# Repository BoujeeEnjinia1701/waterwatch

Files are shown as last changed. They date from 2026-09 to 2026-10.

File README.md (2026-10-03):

# WaterWatch

     

**Area:** Water Security · **TRL:** 3 of 9 (proof of concept on paper) · **Value-engineering target:** USD 300 (estimated cost of the constructable design: USD 322) · **Difficulty:** 3 of 5

Solar sentinel sensor that logs turbidity, free chlorine and temperature at a tap or tank and alerts over GSM or LoRa.

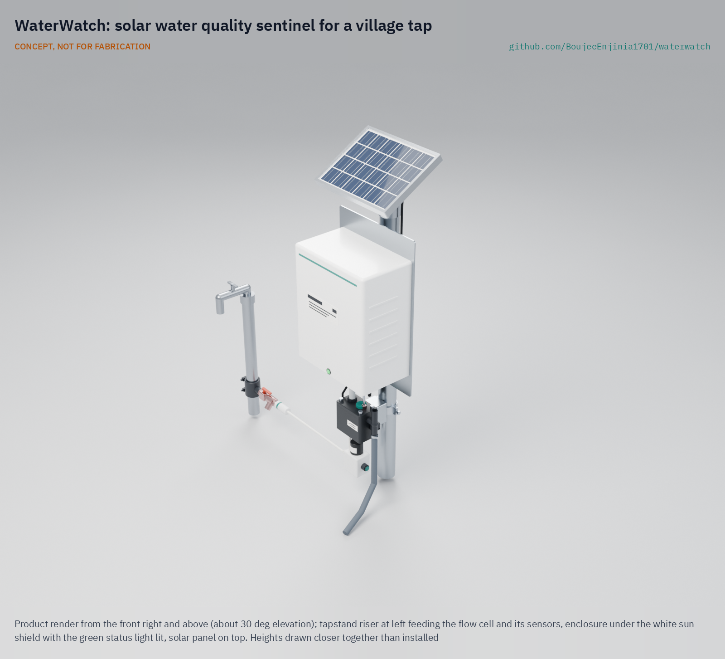
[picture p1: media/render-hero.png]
WaterWatch: solar water quality sentinel for a village tap, product render


[Exploded render](media/render-exploded.png) · [Detail render](media/render-detail.png) · [Interactive 3D model](media/viewer.html) · [Concept blueprint (PDF)](media/concept-blueprint.pdf) · [General arrangement (PDF)](cad/drawings/WWT-DWG-001.pdf) · [Sizing calculations](docs/04-calcs/01-sizing.md) · [Prototype build plan](docs/05-build-plan.md) · [Design decisions](docs/06-design-decisions.md) · [Review note](docs/REVIEW.md)

## Concept rationale

The two readings that tell a rural operator most about treated water at the tap are free chlorine residual and turbidity, and both can be measured without reagents. WaterWatch therefore pairs a membrane-free graphite chlorine sensor and an open-source infrared turbidimeter with a timed hourly flush, a small solar supply and plain SMS alerts, rather than a mains-powered utility analyzer whose chlorine probe alone costs about $1,900. It watches indicators and raises an alert; it does not dose, and it never declares water safe.

Keeping the design open and garage-buildable matters because the people who would install and maintain it are small scheme operators, maintenance service providers and caretakers, not utility instrument technicians. Every part is off the shelf or made from simple stock, the calibration is a monthly DPD comparator check that caretakers already know, and the CERN-OHL-S license lets a regional workshop build, repair and adapt the unit without a vendor.

## Burning platform

In 2024, 2.1 billion people still lacked safely managed drinking water ([WHO and UNICEF JMP, 2025](https://www.who.int/news/item/26-08-2025-1-in-4-people-globally-still-lack-access-to-safe-drinking-water---who--unicef)). WHO estimates that at least 1.7 billion people use a drinking water source contaminated with faeces, and that contaminated drinking water causes about 505,000 diarrhoeal deaths each year ([WHO, drinking-water fact sheet, 2023](https://www.who.int/news-room/fact-sheets/detail/drinking-water)).

Chlorination is the cheapest defense a piped rural scheme has, but it only protects people when a residual of at least 0.2 mg/L reaches the tap ([Oxfam WASH, chlorination in emergencies](https://www.oxfamwash.org/chlorination-in-emergencies/)). Today that is checked by hand when a technician visits, so a chlorinator that runs dry or a storm that clouds the source can go unnoticed for weeks. Remote sensors have already cut repair times for broken handpumps when someone was paid to act on the data ([Nagel et al., ES&T 2015](https://pubs.acs.org/doi/10.1021/acs.est.5b04077)); nothing comparable, open and affordable yet watches the quality of the water itself.

## Where it could be used

### By industry

| Industry | Use |
| --- | --- |
| Rural water utilities and scheme operators | Watch chlorine residual and turbidity at tapstands across many villages and target dosing and repairs |
| Maintenance service providers | Add water quality alerts to existing handpump and scheme functionality monitoring contracts |
| Humanitarian WASH response | Track free chlorine at tapstands in camps and after floods, where chlorination is routine and outbreaks spread fast |
| Schools and health facilities | Monitor the tank outlet or tap that serves pupils and patients between official tests |
| Water kiosks and small private operators | Give customers and regulators a running record of the water they sell |
| Universities and WASH research groups | Collect long, open data sets on residual decay and turbidity events at the point of use |

### By country or region

| Country or region | Why it matters there |
| --- | --- |
| Rwanda | Cellular handpump sensors paired with a paid maintenance service shortened repair times ([Nagel et al., 2015](https://pubs.acs.org/doi/10.1021/acs.est.5b04077)); the same service model could act on water quality alerts |
| Nigeria (Plateau State) | Sensors have already tracked functionality and use of rural water points ([Plateau State sensors, 2022](https://www.sciencedirect.com/science/article/pii/S2352728522000094)); water quality alerts would extend the same approach |
| India | Rural household tap connections rose from 17 % to over 49 % between 2019 and 2022 under the Jal Jeevan Mission, yet [less than 49 % of rural people use safely managed drinking water](https://www.unicef.org/india/what-we-do/clean-drinking-water); a logged residual at the tap would show whether new piped schemes deliver treated water |
| Honduras | Community water boards run passive chlorinators at storage tanks; in a 2023 study [77 % of samples met the 0.2 mg/L WHO minimum, board errors caused 39 % of chlorination lapses, and more frequent circuit-rider visits went with better results](https://pubmed.ncbi.nlm.nih.gov/38094914/) (Lindmark et al., ACS ES&T Water) |
| Canada (Ontario) | A high-income example: at Walkerton in May 2000 operators did not measure chlorine residuals at a municipal well as they should have, seven people died and 2,300 fell ill ([CBC News, highlights of the Walkerton Inquiry report](https://www.cbc.ca/news/canada/highlights-of-the-walkerton-inquiry-report-1.867604)) |

## What sparked the idea

The idea traces back to the E. coli outbreak in Walkerton, Ontario, in May 2000. Part One of the Walkerton Inquiry, released by Associate Chief Justice Dennis O'Connor in 2002, found that the Well 5 water was to carry a chlorine residual of 0.5 mg/L after 15 min of contact, that operators routinely used less chlorine than required, did not measure residuals on most days and made false entries in the daily operating records, and that seven people died and 2,300 became ill ([CBC News, highlights of the Walkerton Inquiry report](https://www.cbc.ca/news/canada/highlights-of-the-walkerton-inquiry-report-1.867604); [National Academies, Lessons from Waterborne Disease Outbreaks](https://www.ncbi.nlm.nih.gov/sites/books/NBK28459/)). The inquiry concluded that continuous chlorine residual and turbidity monitors at Well 5 would have prevented the outbreak. A town in a high-income country, with a regulated municipal supply, lost its chlorine barrier without anyone noticing in time. At a village tapstand checked only on rare visits, the gap is wider, and a logged, automatic residual and turbidity reading that raises its own alert is the part WaterWatch aims to supply.

## Problem

Rural water points go untested between rare lab visits, so a chlorinator that runs dry or a storm that clouds the source can go unnoticed for weeks. Full problem statement: [docs/01-problem.md](docs/01-problem.md)

## Concept

A pole-mounted sentinel beside a village tapstand flushes a small sample through a dark flow-through cell once an hour, measures turbidity, free chlorine and temperature, logs the readings and sends them over cellular (LTE-M, NB-IoT or 2G; LoRaWAN as a variant). An SMS goes to the caretaker and operator when chlorine drops below 0.2 mg/L or turbidity passes 5 NTU. The TRL 3 calculations give 0.54 Wh per day, 28.5 days on battery without sun, 18 L per day of flushed water and an estimated USD 322 in parts for the constructable design, USD 22 over the USD 300 value-engineering target. Following Amish's decisions of 2026-09-25 (WWT-DDR-002), the chlorine accuracy target is ±0.2 mg/L or ±25 %, and sites above pH 7.5 or with a moving pH take a pH probe in a spare port of the cell; the error budget then meets the target before drift, but the low-cost sensor's long-term drift is unknown, so chlorine accuracy and the monthly maintenance interval remain at risk.

Full design precis: [docs/02-concept.md](docs/02-concept.md)

## Key components

- Infrared (860 nm) nephelometric turbidity optics: LED, 90° scatter and 180° reference detectors on three walls of the cell
- Membrane-free three-electrode free chlorine sensor with a potentiostat front end
- Temperature probe
- Opaque 0.19 L flow-through cell fed through a pressure-compensating regulator and a latching solenoid valve from a tee on the tapstand riser, draining through an open air break
- Two aluminium back plates on U-bolts hold the enclosure and the flow cell to the pole
- ESP32 controller with microSD logging
- Cellular modem (LTE-M, NB-IoT, 2G fallback), LoRaWAN as a variant
- 5 W solar panel and 3.2 V, 6 Ah LiFePO4 battery in an enclosure under a ventilated sun shield

The priced bill of materials is in [bom/bom.csv](bom/bom.csv). The parametric model is `cad/src/model.py`, with STEP files in `cad/step/`.

## Building the prototype

The prototype build plan ([docs/05-build-plan.md](docs/05-build-plan.md)) shows how to make and fit every component of the first proof-of-concept unit, with a making sketch for each made part, close-ups of the joints and a picture for every assembly step. Making it buildable changed the concept in places: the enclosure and the flow cell now hang on aluminium back plates held to the pole by U-bolts, every cable enters the box from below so the sun shield slides off, and the turbidity optics sit on three walls of the cell (decision record WWT-DDR-003, accepted by Amish on 2026-10-02). The plan is paper only; building and testing to it is TRL 4 work. The decisions, all made as of 2026-10-02, are in the [design decisions register](docs/06-design-decisions.md).

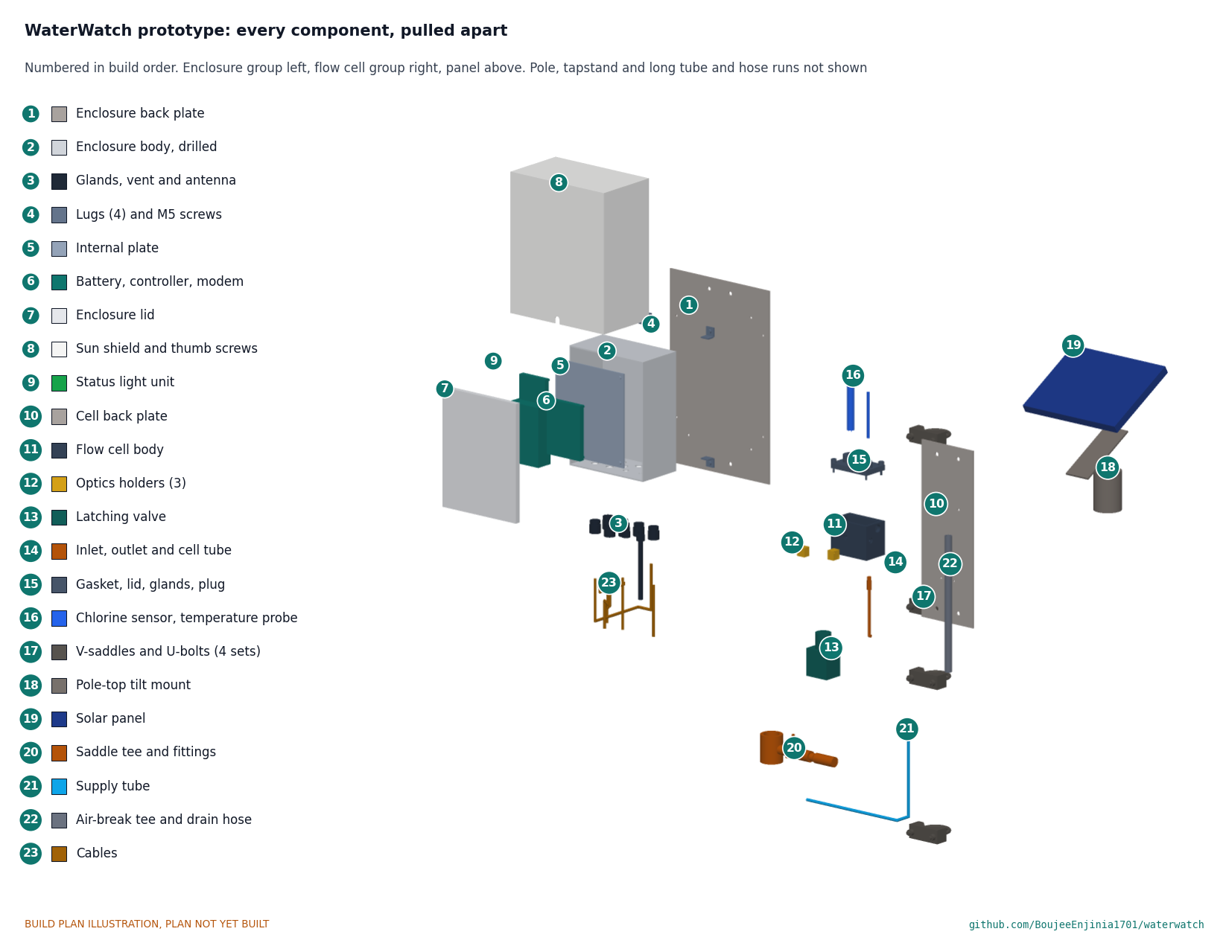
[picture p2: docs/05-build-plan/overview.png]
WaterWatch prototype: every component, pulled apart and numbered in build order


## Safety

> A sensor alert does not replace accredited lab testing, and a normal reading does not mean the water is safe to drink. Contains a LiFePO4 battery: use a protection board, a fuse and charging temperature cut-offs. The sample line connects to a pressurized drinking water supply: fit an isolation valve and a check valve so nothing flows back into the supply.

## Repository layout

| Folder | Contents |
| --- | --- |
| `docs/` | Problem, concept, requirements, calculations and design decisions |
| `cad/src/` | build123d Python source, the source of truth for all geometry |
| `cad/step/`, `cad/stl/` | Exported models for FreeCAD, other CAD tools and printing |
| `cad/drawings/` | 2D sketches and dimensioned drawings |
| `bom/` | Bill of materials |
| `electronics/` | KiCad schematics and PCB layouts |
| `firmware/` | Microcontroller code |
| `media/` | Renders, perspectives and photos |
| `build-log/` | Dated prototyping notes |

## Documentation

Controlled documents follow the portfolio [documentation standard](.kit/STANDARDS.md). Each carries a document ID (WWT-PRC-001 for the precis), a version and a revision history. Branded PDFs are built with `python .kit/render.py` and attached to GitHub Releases when a document is tagged, for example `WWT-PRC-001/v1.0`.

## Credits

Designed by Amish Chadha. See [CONTRIBUTORS.md](CONTRIBUTORS.md) for roles. To cite this design, use [CITATION.cff](CITATION.cff) (GitHub shows it as "Cite this repository").

AI assistance (Claude) was used to accelerate concept renders, prototype documentation and first-pass sizing calculations. Design direction and all decisions are Amish Chadha's, recorded in this repository's decision records (`docs/decisions/`).

## Licenses

- **Hardware** (CAD, drawings, BOM, electronics): [CERN-OHL-S v2](LICENSE)
- **Software** (firmware, scripts, notebooks): [MIT](LICENSE-SOFTWARE)

A project of the [Design Molecule](https://designmolecule.com) lab.

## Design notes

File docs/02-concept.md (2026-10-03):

---
doc_id: WWT-PRC-001
title: WaterWatch design precis
project: WaterWatch
doc_type: Design precis
version: "0.7"
status: Draft
date: '2026-10-02'
author: Amish Chadha
license: CERN-OHL-S-2.0
revisions:
- version: "0.1"
  date: '2026-09-24'
  author: Amish Chadha
  change: Initial scaffold
- version: "0.2"
  date: '2026-09-25'
  author: Amish Chadha
  change: Populate to TRL 2 (architecture, components, first-order numbers, safety, open questions, media)
- version: "0.3"
  date: '2026-09-25'
  author: Amish Chadha
  change: For TRL 3, decisions from WWT-DDR-001; numbers from WWT-CAL-001; smaller flow cell, pressure-compensating regulator, 30 s settling wait, air-break drain and sun shield; parametric model and drawing WWT-DWG-001
- version: "0.4"
  date: '2026-09-25'
  author: Amish Chadha
  change: Recommendations accepted by Amish (DDR-002)
- version: "0.5"
  date: '2026-10-02'
  author: Amish Chadha
  change: Design made constructable (WWT-DDR-003); components table, cost and drawings updated; budget treated as a value-engineering target
- version: "0.6"
  date: '2026-10-02'
  author: Amish Chadha
  change: Partner, alert and data open questions answered by Amish's decisions of 2026-10-02 (WWT-DEC-001)
- version: "0.7"
  date: '2026-10-02'
  author: Amish Chadha
  change: "Energy, autonomy and cost from WWT-CAL-001 v0.4 (status light, WWT-DEC-001)"
---

# WaterWatch design precis

WaterWatch is a solar sentinel that stands on its own pole beside a village tapstand. Once an hour a latching valve on a tee in the tapstand riser opens for 90 s and flushes water through a small, dark flow-through cell. An infrared nephelometer measures turbidity, a membrane-free three-electrode sensor measures free chlorine and a sealed probe measures temperature. An ESP32 controller logs the readings, a cellular modem uploads them every 4 h, and an SMS goes to the caretaker and operator when chlorine drops below 0.2 mg/L or turbidity passes 5 NTU. The TRL 3 calculations (WWT-CAL-001) give 0.54 Wh per day, 28.5 days on a 3.2 V, 6 Ah LiFePO4 battery without sun, 18.0 L per day of flushed water and $322 in parts for the constructable design (WWT-DDR-003 and the status light of WWT-DEC-001), USD 22 over the USD 300 value-engineering target. How each part is made and fitted is in the prototype build plan (WWT-BLD-001). The weak point is still the chlorine reading. Under Amish's decisions of 2026-09-25 (WWT-DDR-002), R1 is relaxed to ±0.2 mg/L or ±25 %, and sites whose pH is above 7.5 or moves more than 0.2 between visits take a pH probe in a spare port of the cell. With that rule the error budget meets R1 before sensor drift, but the low-cost sensor's drift over months is unknown, so R1 and R10 remain at risk. The design choices below were decided by Amish on 2026-09-25 (WWT-DDR-001 and WWT-DDR-002).

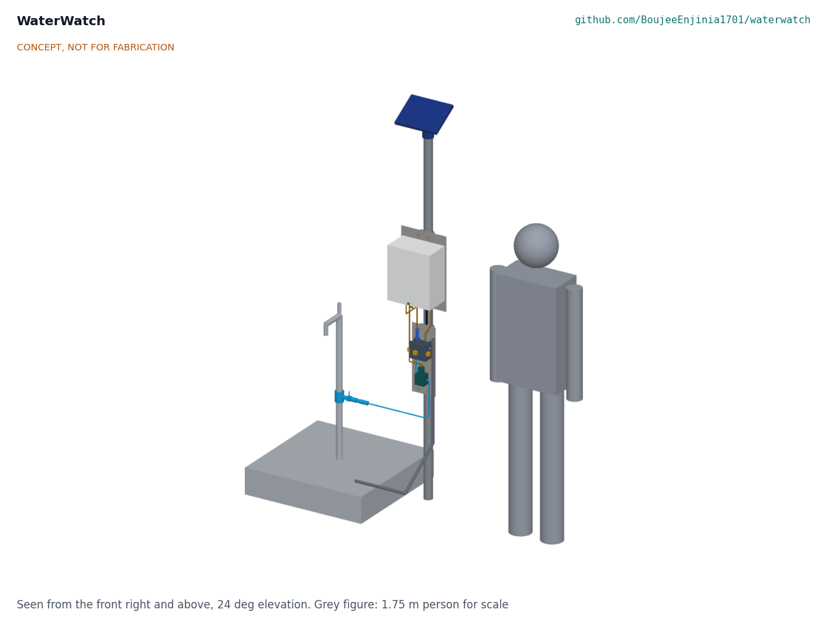
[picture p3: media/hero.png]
Hero render


*Figure 1. WaterWatch beside an existing tapstand (grey), with a 1.75 m person for scale. Solar panel on top, electronics enclosure under a white sun shield at eye height, flow-through cell below it, latching valve and sample line from a tee on the tapstand riser, drain hose to the tapstand basin. Rendered from the parametric model `cad/src/model.py`.*

## How it works

1. **Sample.** A saddle tee with an isolation valve on the tapstand riser feeds a strainer, a check valve, a pressure-compensating flow regulator (0.5 L/min) and a normally closed, direct-acting latching solenoid valve. Every hour the controller opens the valve for 90 s, flushing 0.75 L, about four volumes of the 0.19 L cell, then closes it. The sample enters at the bottom of the cell and leaves near the top, so the cell stays full and the electrodes stay wet between flushes. The outlet rises to an open air-break vent before the drain hose falls to the basin, so the hose cannot siphon the cell empty and the drain can never connect back to the cell.
2. **Measure.** During the last 10 s of flow the controller reads the chlorine sensor, because amperometric sensors need steady flow across the electrode. After the valve closes it waits 30 s for bubbles to rise clear, then reads turbidity for 5 s and temperature. The cell is opaque so daylight does not reach the turbidity detector.
3. **Log.** Each reading is stored with a timestamp on a microSD card (90 days or more) and in a short ring buffer in flash.
4. **Report.** Every 4 h the modem wakes, attaches to LTE-M, NB-IoT or 2G, and posts a compact batch to an open endpoint the operator chooses. If a reading crosses a threshold, the controller takes a confirming reading 15 min later rather than waiting for the next hourly one (WWT-DDR-002). If that one also crosses, it sends an SMS at once, retrying up to three times at 3 min spacing, without waiting for the next upload.
5. **Power.** A 5 W panel charges a 3.2 V, 6 Ah LiFePO4 battery through a small solar charger with temperature cut-offs. A ventilated sun shield keeps the enclosure cool enough for the battery to charge on hot days. Everything else sleeps between readings.

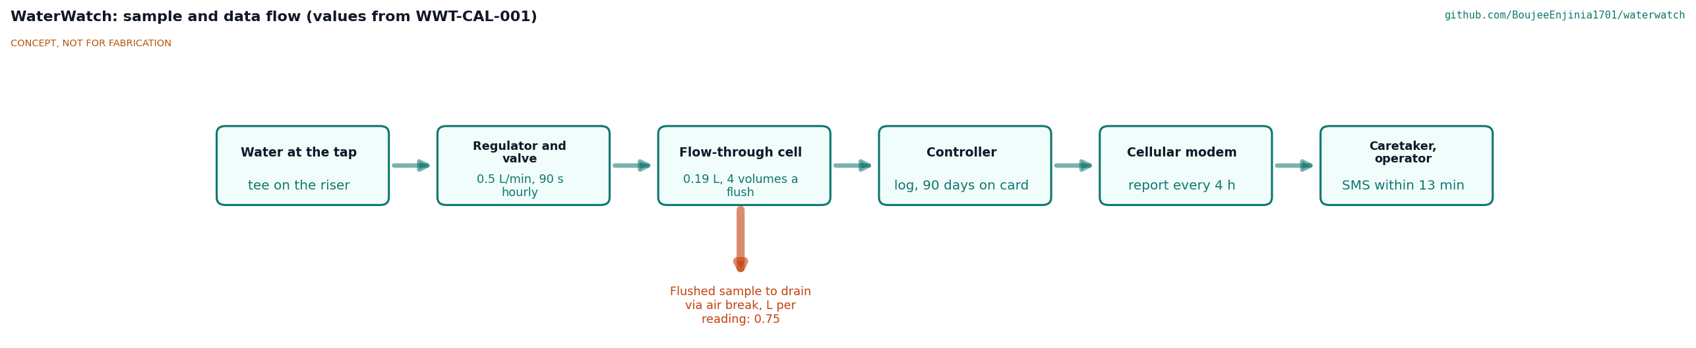
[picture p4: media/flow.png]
Sample and data flow


*Figure 2. Sample and data flow. Values from WWT-CAL-001 for the default hourly schedule.*

## Main components

Table 1. Main components. Numbers match `bom/bom.csv` and Figure 5.

| # | Component | Choice | Notes |
| --- | --- | --- | --- |
| 1 | Mounting pole, U-bolts and V-saddles | 48.3 x 3.2 mm galvanized tube, 2.1 m above ground, 0.6 m in a 300 mm concrete footing beside the tapstand; four M8 U-bolts with V-saddles hold the two back plates (item 18) | Keeps the tapstand itself unchanged; factor 4.5 in a 35 m/s gust (WWT-CAL-001, I) |
| 2 | Solar panel | 5 W monocrystalline, about 250 x 190 mm, tilted 30° toward the equator on a bought pole-top tilt mount | Oversized for the load so cloudy weeks are covered |
| 3 | Enclosure base | IP66 polycarbonate, 200 x 120 x 260 mm, UV-stabilized, pressure-equalizing vent; every cable, the vent and the antenna enter through the bottom face (WWT-DDR-003) | Light grey, under the sun shield (item 17) |
| 4 | Enclosure lid and gasket | Supplied with item 3; tamper-resistant screws | |
| 5 | Battery | LiFePO4, 1S2P 32700 cells, 3.2 V, 6 Ah (19.2 Wh), protection board and NTC | Chemistry chosen for heat tolerance and thermal stability |
| 6 | Controller board | ESP32-S3 module, LiFePO4 solar charger, LMP91000-class potentiostat front end, valve driver with boost to 12 V, microSD, real-time clock | Carrier board; a custom PCB is TRL 4 work |
| 7 | Cellular modem | LTE-M and NB-IoT with 2G fallback (SIM7000G class), SIM | Swappable; LoRaWAN module as a variant (WWT-DDR-001, D3) |
| 8 | Antenna | External LTE and GSM whip on a bulkhead in the bottom face, pointing down | Moved from the top so the sun shield can slide off (WWT-DDR-003) |
| 9 | Flow-through cell | Opaque black PVC or printed ASA block, 96 x 60 x 74 mm with a 14 mm back wall screwed to the cell plate, gasket and 10 mm lid on four studs with thumb nuts, 80 x 38 x 66 mm cavity, 0.19 L of water, baffle on the back wall, inlet in the floor and outlet near the top; lid glands for the sensors and a spare M20 port with a blanking plug | Half the TRL 2 volume so the flush clears it; opens without tools for cleaning; the spare port takes the pH probe variant (WWT-DDR-002) |
| 10 | Turbidity optics | 860 nm infrared LED on the left wall, light-to-frequency detectors on the front wall (90°, scatter) and right wall (180°, reference), each in a small holder with a window, after [Kelley et al. (2014)](https://www.mdpi.com/1424-8220/14/4/7142) | ISO 7027 style wavelength |
| 11 | Free chlorine sensor | Membrane-free three-electrode sensor: graphite working electrode, Ag/AgCl reference, stainless counter, in a PVC holder, after [Pan et al. (2015)](https://pubs.acs.org/doi/10.1021/acs.analchem.5b03164) | Decided (WWT-DDR-001, D1); long-term drift unknown |
| 12 | Temperature probe | DS18B20 in a stainless sheath | Also used for chlorine sensor temperature compensation |
| 13 | Latching solenoid valve | 12 V, 1/4 in (6.35 mm) port, normally closed, direct acting, food-safe wetted parts; screwed to the cell plate under the cell | Latching, so it draws power only while switching; direct acting so it opens at 0.5 bar |
| 14 | Sample line | Saddle tee with isolation ball valve, strainer, check valve, pressure-compensating 0.5 L/min regulator, 1/4 in food-grade PE tube | The only change to the tapstand; the regulator holds R8 from 0.7 to 4 bar |
| 15 | Drain hose and air break | Outlet elbow with an open air-break vent, then 12 mm hose to the tapstand basin | Basin by default, soakaway or container per site (WWT-DDR-001, D7) |
| 16 | Cables, glands and fuse | Sensor and panel leads, IP68 glands, battery fuse | |
| 17 | Sun shield | White aluminum hood with a 25 mm ventilated gap over the enclosure top, sides and front; flanges at the back held by four thumb screws; slides off forward | Added at TRL 3 so the battery can charge on hot days (WWT-CAL-001, C) |
| 18 | Mounting plates | Enclosure back plate 270 x 420 mm and cell back plate 140 x 385 mm, 3 mm aluminium, drilled | Added for construction (WWT-DDR-003) |
| 19 | Lugs and internal plate | The enclosure maker's four mounting lugs; a printed internal plate on the box's moulded bosses carrying the battery, controller and modem | Added for construction (WWT-DDR-003) |
| 20 | Fixings | Stainless screws, thumb screws, standoffs, battery strap, cable ties | Added for construction (WWT-DDR-003) |

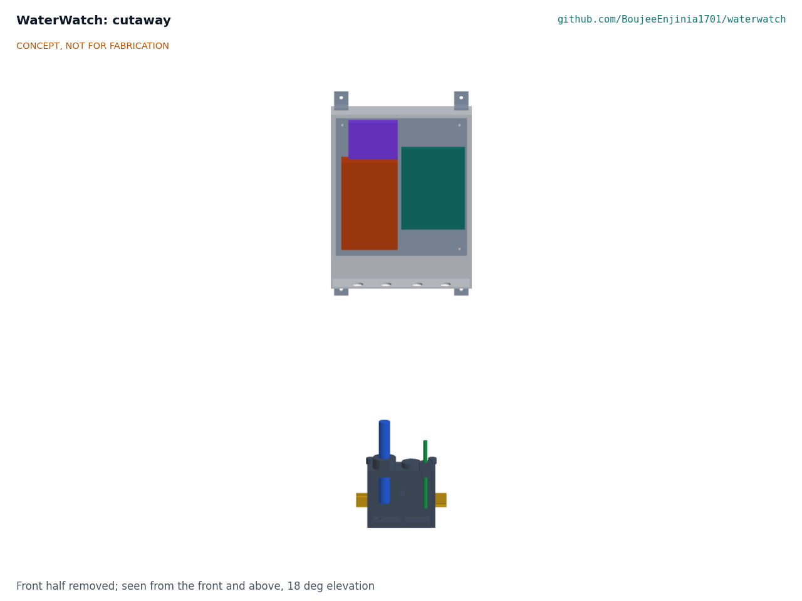
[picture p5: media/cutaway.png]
Cutaway


*Figure 3. Section through the flow cell, 7 mm in front of its centre, looking at the front, with the sun shield removed. Top: enclosure with the modem (7, purple) and battery (5, orange) on the left and the controller board (6, teal) on the right, on the internal plate. Bottom: flow-through cell (9) with the chlorine sensor (11, blue) and temperature probe (12, green) entering through the lid, the LED and 180° detector holders of the turbidity optics (10, yellow) on the left and right walls, and the outlet near the top on the right.*

## Key numbers

All values come from WWT-CAL-001, which states its assumptions; the tags in brackets are the lines of `docs/04-calcs/sizing.py` that print them. The main assumptions are hourly readings, 130 s awake per reading at 0.264 W, a 50 µA sleep floor, six uploads a day at 20 mWh each, a 1.5 margin and 4.5 peak sun hours with a 0.6 derating.

*Table 2. Key numbers.*

| Quantity | Value | Basis | Requirement |
| --- | --- | --- | --- |
| Daily energy with margin | 0.540 Wh/day | 0.229 Wh measuring, 0.120 Wh uploads, 9 mWh sleep and valve, 2 mWh status light, x 1.5 [A3] | |
| Autonomy without sun | 28.5 days (24.2 at 0 °C) | 15.36 Wh usable [B1] | R7 met on paper |
| Solar yield, 5 W panel | 13.5 Wh per clear day, 7.5 Wh overcast | [B2]; 1.19 clear days to refill [B3] | R7 met on paper |
| Enclosure peak on a 45 °C day | 50.8 °C with the sun shield; 69.8 °C without | Dusty enclosure, sun square to the front [C4] | R9 at risk |
| Flow-through cell | 0.185 L of water | Parametric model [D1] | |
| Water per reading and per day | 0.75 L; 18.0 L (19.8 L at regulator tolerance) | 0.5 L/min for 90 s, 24 readings [D2], [D5] | R8 met on paper, thin margin |
| Old water left at the chlorine reading | 2.9 % | Well-mixed cell [D3] | R1 |
| Chlorine error at 0.5 mg/L, pH 7.5 | ±0.131 mg/L before drift, against ±0.2 mg/L | Site pH ±0.2 between visits, DPD reference [E4] | R1 at risk (drift unknown) |
| Room for sensor drift | 0.13 mg/L or more | Relaxed R1 with the pH probe rule, 25 °C [E8] | R1, R10 at risk |
| Data per month | 0.86 MB | 780 B payload and 4 kB overhead per upload [G1] | R6 met on paper |
| Confirmation to SMS | 13.0 min worst case; 77 min from the event | Three tries at 3 min spacing [H1]; 15 min confirming reading [H2] | R5 met on paper |
| Installation day | 65 min critical path | Footing cast on the survey visit [J2] | R11 met on paper |
| Parts cost | $322 per base unit; $382 to $422 at a pH probe site | `bom/bom.csv` [K1], [K2] | R12: USD 22 over the USD 300 value-engineering target |
| Shared calibration kit | about $60 | DPD free chlorine and pH comparator, turbidity standards (estimate) | Not in the unit cost |

The chlorine reading is the least certain number. Free chlorine is the sum of hypochlorous acid (HOCl) and hypochlorite (OCl⁻); their split depends on pH, with a pKa of 7.54 at 25 °C, so at pH 8 only 0.26 of free chlorine is HOCl, while at pH 7 0.77 is [E2]. Amperometric sensors respond mainly to HOCl, so the same free chlorine gives very different signals across the pH range in R1. Calibrating at the site against the DPD comparator absorbs the pH on the day of calibration, but a change of 0.2 pH before the next visit shifts the reading by 12 % at pH 7.0, 22 % at pH 7.5 and 38 % at pH 8.0 [E4]. The site pH method is therefore adequate at near-neutral, stable sites and not elsewhere. That is why WWT-DDR-002 fits the pH probe variant where site pH is above 7.5 or moves more than 0.2 between visits, and relaxes R1 to ±0.2 mg/L or ±25 %, since the DPD comparator used as the field reference already takes ±0.07 mg/L. With both, all eight cases in WWT-CAL-001 meet R1 before drift [E6]; at 40 °C, 1.5 mg/L at pH 7.5 with site pH misses by 0.006 mg/L [E7].

## Key design choices

Each choice below was decided by Amish on 2026-09-25, going with the recommendation (WWT-DDR-001 and WWT-DDR-002). The options considered are kept for the record.

- **Chlorine sensor (D1).** Chosen: a membrane-free graphite three-electrode sensor with a potentiostat front end, after [Pan et al. (2015)](https://pubs.acs.org/doi/10.1021/acs.analchem.5b03164) and the [pencil graphite work in PLOS ONE (2021)](https://journals.plos.org/plosone/article?id=10.1371%2Fjournal.pone.0248142), about $25 in parts, with a monthly DPD comparison built into the maintenance routine. Not chosen: an industrial membrane amperometric probe, well proven but about $1,900 for the probe alone ([Sensorex FCL](https://sensorex.com/product/fcl-amperometric-free-chlorine-sensor/)); an ORP probe as a proxy, about $175 as a kit ([Atlas Scientific](https://atlas-scientific.com/kits/ezo-complete-orp-kit/)), which tracks chlorine only loosely. The long-term performance literature ([Water Science and Technology, 2025](https://iwaponline.com/wst/article/92/2/326/108695/Long-term-performance-of-low-cost-free-chlorine)) could not be checked in full; see `docs/REVIEW.md`.
- **pH (D2).** Chosen: site pH entered at installation and checked monthly, at no cost. A pH probe and interface (about $60 to $100, estimate) is a documented variant. Under WWT-DDR-002 it is fitted at sites whose pH is above 7.5 or moves more than 0.2 between visits, in a spare port in the cell lid that is plugged at other sites; it is priced per variant site, outside the $300 base-unit budget, which stays unchanged.
- **R1 target (WWT-DDR-002).** Chosen: relax to ±0.2 mg/L or ±25 %, whichever is greater. Not chosen: keep ±0.1 mg/L and accept that R1 is not met; keep it and make the pH probe standard, which exceeds the budget.
- **Confirming reading (WWT-DDR-002).** A firmware rule: after a first threshold crossing, the next reading is taken 15 min later instead of at the next hour, cutting the worst case from event to SMS from 122 min to 77 min for about 10 mWh and 0.75 L per event.
- **Footing on the survey visit (WWT-DDR-002).** The pole footing is dug and cast, with the pole set, on the survey visit, so installation day takes about 65 min instead of 140 min.
- **Sampling by timed flush (D5).** An hourly 90 s flush uses 18.0 L per day; continuous flow at 0.5 L/min would use 720 L. At TRL 3 the cell was halved in volume, the fixed restrictor replaced by a pressure-compensating regulator, and the outlet moved near the top with an air break, all within this decision.
- **Pole beside the tapstand (D4).** A separate pole keeps the panel above head height, keeps the electronics out of reach of splashing and buckets, and needs no drilling into the tapstand. The cost is one more concrete footing, which also sets the installation time (R11).
- **Connectivity (D3).** Cellular LTE-M and NB-IoT with 2G fallback and SMS alerts for the first build, with the modem as a swappable module so LoRaWAN is a variant; this keeps the "GSM or LoRa" pitch.
- **LiFePO4 battery (D9).** Chosen over lithium-ion 18650 cells for heat tolerance and thermal stability, with charging blocked below 0 °C and above 45 °C. At TRL 3 a ventilated sun shield was added because, without it, the enclosure stays above 45 °C for almost all of a clear hot day.
- **Default alert thresholds (D6).** Free chlorine below 0.2 mg/L and turbidity above 5 NTU, confirmed by two consecutive readings, adjustable per site.
- **Drain (D7).** To the tapstand basin by default, to a soakaway or a container for non-drinking use where users prefer, decided per site.
- **First site type (D8).** Tapstands first; tank outlets and kiosks later.
- **SwapCell (D10).** Not used: WaterWatch needs about 0.5 Wh per day, and the portfolio's 48 V SwapCell pack does not fit.

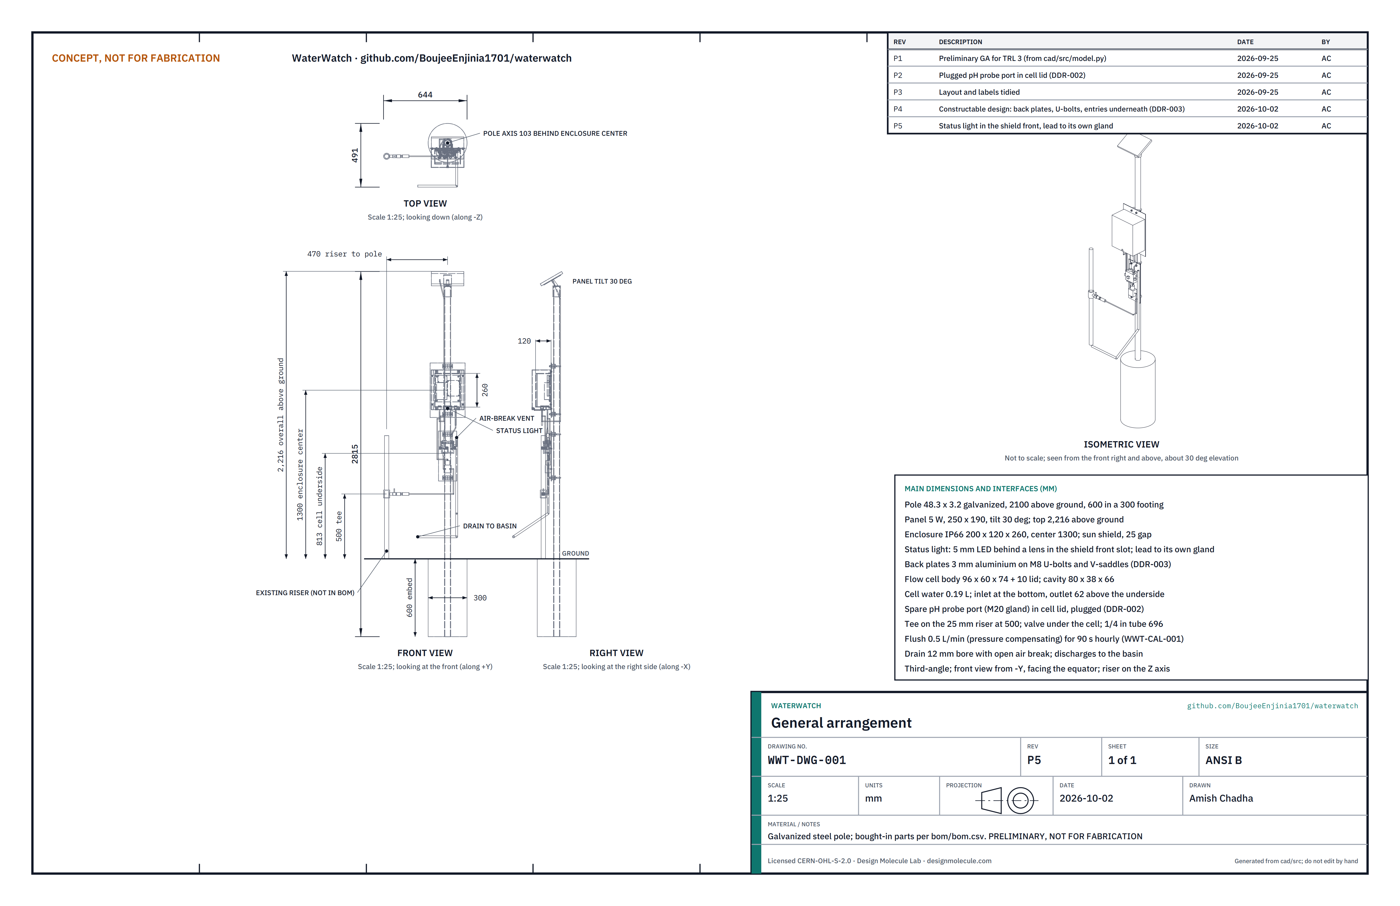
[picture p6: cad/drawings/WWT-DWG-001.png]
General arrangement


*Figure 4. General arrangement WWT-DWG-001, Rev P4, generated from `cad/src/model.py` by `cad/src/sheets.py`. Preliminary, not for fabrication.*

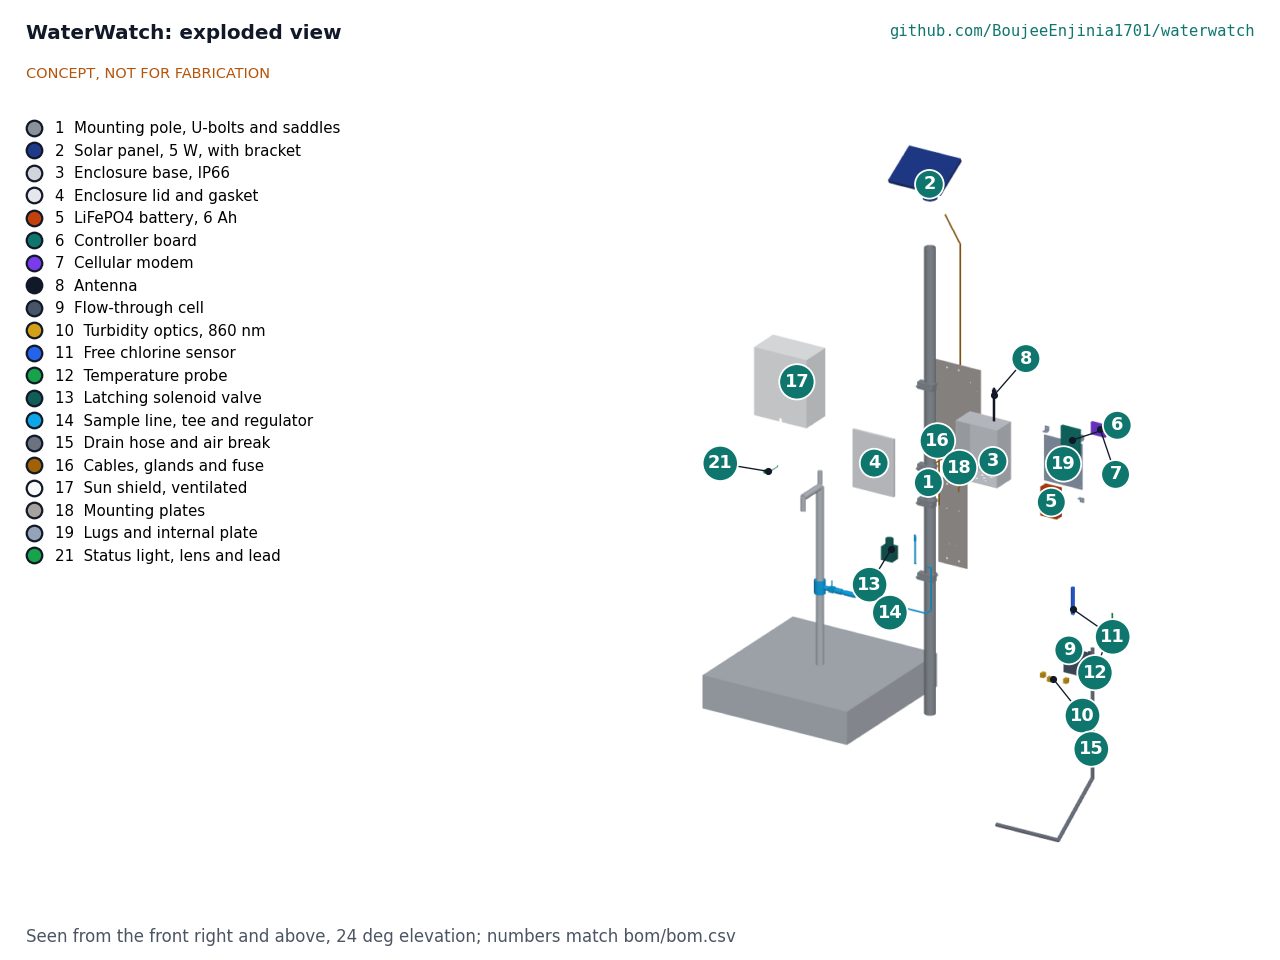
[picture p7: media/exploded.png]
Exploded view


*Figure 5. Exploded view with BOM numbers. The tapstand (grey) is existing infrastructure and not in the BOM.*

## Safety

> **Safety:** WaterWatch is a monitoring aid, not a certification of water safety. A normal reading does not mean the water is free of pathogens or chemical contaminants; accredited laboratory testing, including microbiological testing, remains necessary. Alerts must be worded as measurements, never as "safe" or "unsafe".

> **Safety:** The design contains a lithium iron phosphate battery (19.2 Wh). Use cells with a protection board, a fuse at the battery, and charging cut-offs below 0 °C and above 45 °C. Keep the enclosure vented, light-colored and under its sun shield; WWT-CAL-001 shows that an unshaded enclosure reaches about 70 °C inside on a 45 °C day.

> **Safety:** The sample line connects to a pressurized drinking water supply. Fit an isolation valve and a check valve so nothing can flow back into the supply, use food-safe wetted materials, keep the open air break at the cell outlet, and never let the flushed sample return to the drinking water. Fitting the saddle tee needs the supply shut off unless a tool for tapping under pressure is used. Flushed water contains chlorine; drain it where it cannot pool against the tapstand or be mistaken for a separate water point.

> **Safety:** Calibration and cleaning use chemicals: DPD reagent tablets, and formazin turbidity standards, which are hazardous if made from their precursors. Use prepared, stabilized standards, gloves and the supplier's safety data sheets; do not make formazin in the field.

- The pole is a fall and impact hazard if it is not set properly; set it in concrete and keep sharp edges on the panel frame and clamps covered.
- Radio and battery equipment must meet local type-approval rules before any field installation.

## Open questions

- [ ] What does the published long-term data say about low-cost chlorine sensor drift, and is it below the 0.13 mg/L per month that R1 and R10 now allow? (the WST 2025 paper is still unchecked in full)
- [ ] Does the sun shield cut the solar gain as much as assumed (a quarter)? (R9)
- [ ] How fast do the cell windows and the chlorine electrode foul at a turbid site, and does a monthly clean suffice? (R2, R10)
- [ ] How much does source pH move between monthly visits at candidate sites? (R1)
- [ ] Confirm with caretakers and operators the alert and data defaults decided by Amish on 2026-10-02 (WWT-DEC-001): SMS in the local language to the caretaker and the operator's maintenance contact, and data owned by the scheme operator.
- [ ] Approach the first candidate partner, Water Mission, and choose the first region from its East African country programs (decided by Amish, 2026-10-02, WWT-DEC-001).

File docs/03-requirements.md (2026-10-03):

---
doc_id: WWT-REQ-001
title: WaterWatch requirements
project: WaterWatch
doc_type: Requirements
version: "0.6"
status: Draft
date: '2026-10-02'
author: Amish Chadha
license: CERN-OHL-S-2.0
revisions:
- version: "0.1"
  date: '2026-09-24'
  author: Amish Chadha
  change: Initial scaffold
- version: "0.2"
  date: '2026-09-25'
  author: Amish Chadha
  change: First measurable requirements for TRL 2, with concept status
- version: "0.3"
  date: '2026-09-25'
  author: Amish Chadha
  change: For TRL 3, status of every requirement from WWT-CAL-001; decisions from WWT-DDR-001 recorded; targets unchanged
- version: "0.4"
  date: '2026-09-25'
  author: Amish Chadha
  change: Recommendations accepted by Amish (DDR-002)
- version: "0.5"
  date: '2026-10-02'
  author: Amish Chadha
  change: Status from WWT-CAL-001 v0.3 for the constructable design (WWT-DDR-003); R12 stated against the value-engineering target
- version: "0.6"
  date: '2026-10-02'
  author: Amish Chadha
  change: "R7 and R12 figures from WWT-CAL-001 v0.4 (status light); no status changed"
---

# WaterWatch requirements

These requirements were first set for the concept and are checked by calculation in WWT-CAL-001 v0.4. Version 0.4 applies Amish's decisions of 2026-09-25 (WWT-DDR-002): R1 is relaxed, R11 is restated for a footing cast on the survey visit, R5 gains a 15 min confirming reading and R12 now states that the pH probe variant is priced per variant site. The targets are still not user-validated needs and will be revised after co-design. On paper, no requirement is missed outright; four are at risk (R1, R10, R2 and R9), five are met by calculation and three by design, and the parts cost of the constructable design (WWT-DDR-003) is USD 19 over the USD 300 value-engineering target (R12). Version 0.5 updates the status for that design; no target changed. In v0.3, R1 and R10 were not met and R11 was at risk. Amish's decisions are in WWT-DDR-001 and WWT-DDR-002.

*Table 1. Requirements and TRL 3 status (from WWT-CAL-001 v0.4, Table 4), at-risk items first.*

| ID | Requirement | Target | Verification | TRL 3 status |
| --- | --- | --- | --- | --- |
| R1 | Measure free chlorine at the tap | 0 to 2.0 mg/L; within ±0.2 mg/L or ±25 %, whichever is greater, at pH 6.5 to 8.5 and 5 to 40 °C (relaxed from ±0.1 mg/L below 1.0 mg/L and ±15 % above, WWT-DDR-002). Sites whose pH is above 7.5 or moves more than 0.2 between visits use the pH probe variant | Error budget (WWT-CAL-001, E); later side-by-side with a DPD comparator | **At risk**: met in 8 of 8 cases at 25 °C before drift, with at least 0.13 mg/L left for drift; 1.5 mg/L at pH 7.5 and 40 °C misses by 0.006 mg/L; sensor drift unknown |
| R10 | Be maintainable by a caretaker | One visit per month or less, 30 min or less, no special tools: clean the cell, compare with a DPD kit, adjust calibration from a phone or keypad | Task analysis (WWT-CAL-001, J) | **At risk**: the visit takes 30 min, at the limit, and a monthly interval needs chlorine drift below about 0.13 mg/L per month under the relaxed R1 (was 0.04 mg/L), which no verified data show |
| R2 | Measure turbidity | 0 to 100 NTU, reporting "above 100 NTU" beyond; within ±0.5 NTU or ±10 %, whichever is greater | Published open-source design; bubble and settling calculation (WWT-CAL-001, F); later stabilized standards | **At risk**: the 30 s wait clears 100 µm bubbles at 5 °C; window fouling between cleans is unknown |
| R9 | Survive outdoors | Electronics IP65 or better; ambient 0 to 45 °C in direct sun; UV-stable parts; flow cell opaque to daylight; battery charging blocked below 0 °C and above 45 °C | Thermal estimate (WWT-CAL-001, C); parts selection | **At risk**: with the sun shield the inside peaks at 50.8 °C on a 45 °C day (69.8 °C without); the shield factor is assumed |
| R5 | Alert the people who act | SMS to up to three numbers within 15 min of a confirmed crossing (two consecutive readings, the second taken 15 min after the first crossing, WWT-DDR-002): free chlorine below 0.2 mg/L, turbidity above 5 NTU, device fault or low battery; thresholds adjustable per site | Latency calculation (WWT-CAL-001, H) | Met on paper where there is coverage: 13.0 min worst case with three tries at 3 min spacing; 77 min from the event (was 122 min) |
| R6 | Report and keep data | Upload readings at least every 4 h over LTE-M, NB-IoT or 2G (LoRaWAN variant); keep 90 days on board if the link fails; open CSV or JSON format; works without a cloud service | Data budget (WWT-CAL-001, G) | Met on paper: 0.86 MB per month; 90 days in 138 kB |
| R7 | Run on sunlight alone | 7 days or more with no sun from full; back to full in 3 clear days or fewer | Energy budget (WWT-CAL-001, A and B) | Met on paper: 28.5 days (24.2 at 0 °C); 1.19 clear days to refill; the status light costs 2 mWh a day; hot days rely on the sun shield (R9) |
| R8 | Use little treated water | 20 L/day or less at hourly sampling | Flow calculation (WWT-CAL-001, D) | Met on paper, thin margin: 18.0 L/day nominal, 19.8 L at the regulator's tolerance |
| R11 | Install simply and safely | Two people, 2 h or less on installation day, with the pole footing dug and cast on the survey visit (WWT-DDR-002); hand tools only; one tee and isolation valve on the riser; backflow prevented; wetted parts food-safe | Task analysis (WWT-CAL-001, J); design review | Met on paper: 65 min critical path on installation day (140 min if done in one visit); the design parts are met |
| R12 | Stay within the concept budget | Parts cost per base unit against a value-engineering target of $300 (a hypothetical control target, not a limit), excluding the shared calibration kit, airtime and the pH probe variant, which is priced per variant site (WWT-DDR-002) | Priced BOM (WWT-CAL-001, K) | Over the value-engineering target by $22: $322 per base unit for the constructable design; $382 to $422 at a pH probe variant site |
| R3 | Measure water temperature | 0 to 50 °C, within ±0.5 °C | Sensor datasheet | Met by design |
| R4 | Sample on a schedule | One reading per hour by default; configurable from 15 min to 24 h | Energy at the 15 min schedule (WWT-CAL-001, A and B) | Met by design (15 min schedule: 1.589 Wh/day, 9.7 days on battery, but 72 L/day of water) |
| R13 | Report measurements, not verdicts | Messages state what was measured and when; the device never says the water is "safe" | Design review of alert wording | Met by design |

## Assumptions

- Site: public tapstand on a piped, chlorinated rural scheme, with a supply pressure of 0.5 to 4 bar (7 to 58 psi) at the riser. Tapstands come first; tank outlets and kiosks later (WWT-DDR-001, D8).
- Alert thresholds follow the field guidance summarized in WWT-PRB-001: at least 0.2 mg/L free chlorine at the point of delivery, and chlorination losing effectiveness as turbidity rises. The defaults of 0.2 mg/L and 5 NTU were decided by Amish on 2026-09-25 (WWT-DDR-001, D6) and remain adjustable per site.
- The caretaker's DPD test is the field reference for free chlorine. The v0.3 target of ±0.1 mg/L matched the resolution of common DPD comparator kits, which WWT-CAL-001 showed made it as tight as the reference itself (the comparator alone takes ±0.07 mg/L); R1 was relaxed to ±0.2 mg/L or ±25 % for that reason (WWT-DDR-002).
- pH affects the split between hypochlorous acid and hypochlorite, and amperometric sensors respond mainly to hypochlorous acid. R1 is assessed with a site pH entered at installation and checked monthly (WWT-DDR-001, D2), assumed to move no more than ±0.2 between visits. Under WWT-DDR-002 the pH probe variant (read to ±0.1) is fitted at sites whose pH is above 7.5 or moves more than 0.2 between visits; the cell lid carries a plugged spare port for it.
- Budget: the $300 in `project.yaml` is a value-engineering target for one base unit's parts, not a spending limit (Amish, 2026-10-01). A shared calibration kit (about $60), airtime (about $1 to $3 per month) and, at variant sites only, the pH probe and interface (about $60 to $100) are listed separately; all are estimates.
- Installation: the pole footing is dug and cast on the survey visit, so the pole is set and cured before installation day (WWT-DDR-002).

> **Safety:** Meeting these requirements does not make the water safe to drink or the unit safe to install. The sample line connects to a pressurized drinking water supply and the unit contains a lithium iron phosphate battery; see WWT-PRC-001, Safety.

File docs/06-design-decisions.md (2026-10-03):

---
doc_id: WWT-DEC-001
title: WaterWatch design decisions register
project: WaterWatch
doc_type: Design decisions register
version: "0.3"
status: Draft
date: '2026-10-02'
author: Amish Chadha
license: CERN-OHL-S-2.0
revisions:
  - version: "0.1"
    date: '2026-10-02'
    author: Amish Chadha
    change: Register opened with the build plan; budget treated as a value-engineering target
  - version: "0.2"
    date: '2026-10-02'
    author: Amish Chadha
    change: Amish approved the recommendations for open items 1 to 10 on 2026-10-02 (WWT-DDR-003 accepted with A1 to A3, render and appearance items, Water Mission as first candidate partner, alert and data rules); moved to decisions made
  - version: "0.3"
    date: '2026-10-02'
    author: Amish Chadha
    change: "Decisions carried out: status light in the model, BOM line 21 and a seventh gland (cost USD 322); alert message templates; tamper-resistant shield screws named for field units"
---

# WaterWatch design decisions register

Every design decision still to be made, and every decision made, in one place. Each decision is argued in full in its decision record under `docs/decisions/`; this register is the index Amish works from. The build plan (`docs/05-build-plan.md`, WWT-BLD-001) describes the design as it stands and does not list open decisions.

## Open decisions

None. All open decisions were decided on 2026-10-02.

## To confirm when parts are bought

| # | What to confirm | Why it matters | Source |
| --- | --- | --- | --- |
| 1 | The enclosure model, its boss spacing (assumed 166 x 185 mm) and its four-lug kit | They set the internal plate holes and the lug holes in the back plate | WWT-DDR-003, P2 and P3 |
| 2 | The U-bolt and V-saddle kits fit 48.3 mm pipe, and the depth of the saddle's V | The V sets how far the pole sits behind the plates (40 mm assumed) | WWT-DDR-003, P1 |
| 3 | The valve has two M4 mounting holes in its back face, or a maker's bracket | Sets the valve holes in the cell plate | WWT-DDR-003, P10 |
| 4 | The pole-top mount fits 48.3 mm pipe and the panel frame's holes | The panel position and tilt depend on it | WWT-DDR-003, P11 |
| 5 | The M25 gland grips the 16 mm chlorine sensor body and the M12 gland the 6 mm temperature probe | Gland clamping ranges differ between makers | WWT-DDR-003, P7 |
| 6 | The push-fit elbows and the inlet fitting are 1/8 BSPT; the hose tail is 3/8 BSP for 12 mm hose | Sets the taps for the cell body | WWT-DDR-003, P9 and P10 |
| 7 | The light-to-frequency detectors and the 860 nm LED fit a 5 mm bore | Sets the holder bore | WWT-DDR-003, P6 |
| 8 | The charger's charging window is 0 to 45 °C in its datasheet | Some chargers of this class fix a different window | WWT-DDR-001, D9 |

## Value engineering

Value-engineering target: USD 300 (a hypothetical control target, not a limit). Estimated cost of the constructable design: USD 322 per base unit (USD 22 over the target), from `bom/bom.csv` (WWT-CAL-001, K1). A pH probe variant site costs about USD 382 to 422. Main cost drivers and savings worth trying:

- The largest lines are the pole with its U-bolts and saddles (USD 35), the controller carrier board (USD 32), the cellular modem (USD 30), the chlorine sensor (USD 25), the enclosure (USD 22), the battery (USD 20) and the sample line fittings (USD 20).
- Making the design constructable added USD 36: the two back plates (USD 10), the lugs and internal plate (USD 8), fixings (USD 6), three more glands and a blanking plug (USD 4), the cell's gasket, studs and lid glands (USD 4), push-fit elbows (USD 2), the shield fixing (USD 1) and the drain hose tail (USD 1). The status light of 2026-10-02 added USD 3 (lens unit and lead USD 2, a seventh gland USD 1).
- Savings worth trying: the LoRaWAN modem variant (about USD 12 instead of USD 30) where a gateway is in range, which alone brings the unit to about USD 301; a box with moulded mounting flanges instead of a separate lug kit (about USD 3); cutting both back plates from one offcut and buying fixings in bulk for several units (about USD 3 to 5); a locally sourced pole or an existing post at sites that have one (up to about USD 25).

## Decisions made

| Date | Decision | Decided by | Record |
| --- | --- | --- | --- |
| 2026-09-25 | TRL 2 review items D1 to D10: membrane-free graphite chlorine sensor with monthly DPD check, site pH with a pH probe variant, cellular with LoRaWAN as a variant, separate pole, hourly 90 s flush, 0.2 mg/L and 5 NTU alerts, drain to the basin, tapstands first, LiFePO4 with 0 to 45 °C charging, no SwapCell | Amish: "proceed with all of your recommendations across all batches. Make sure we don't proceed to TRL 4 on any of them." | WWT-DDR-001 |
| 2026-09-25 | D11 to D14: R1 relaxed to ±0.2 mg/L or ±25 %; pH probe at sites above pH 7.5 or moving more than 0.2; confirming reading 15 min after a first crossing; footing cast on the survey visit | Amish: "i accept all your recommendations, go with them across all repos." | WWT-DDR-002 |
| 2026-09-30 | Make the design physically buildable while drawing the build plan; keep open decisions out of the build plan and in this register | Amish: "If you are realising that the design cannot be built as per concept - fix the design assumptions to match and be physically feasible as you draw the illustrations." | WWT-DDR-003 (changes made under this instruction, open for review: open decision 1) |
| 2026-10-01 | `budget_usd` is a value-engineering target, not a limit | Amish: "the budgets are a hypothethical control target to ensure we are thinking along a value engineering lens." | `.kit/STANDARDS.md` section 18; this register |
| 2026-10-02 | Design for construction accepted: the changes P1 to P13 of WWT-DDR-003, as made | Amish: "APPROVED: The open decisions from the last wave (TremorTrace to ZeerBox) came in after the review and aren't on the page either." | WWT-DDR-003, Table 1 |
| 2026-10-02 | Shield fixing: knurled thumb screws for the prototype; tamper-resistant M5 screws on field units after the first site visit | Amish: "APPROVED: The open decisions from the last wave (TremorTrace to ZeerBox) came in after the review and aren't on the page either." | WWT-DDR-003, A1 |
| 2026-10-02 | Antenna: the whip points down from the bottom face, and signal strength is measured at TRL 4; a pole-top antenna is used only at a weak-signal site | Amish: "APPROVED: The open decisions from the last wave (TremorTrace to ZeerBox) came in after the review and aren't on the page either." | WWT-DDR-003, A2 |
| 2026-10-02 | Water volume in the calculation: the full-cavity 0.185 L is kept, conservative for flushing; the standing volume is measured at TRL 4 | Amish: "APPROVED: The open decisions from the last wave (TremorTrace to ZeerBox) came in after the review and aren't on the page either." | WWT-DDR-003, A3 |
| 2026-10-02 | Product render layout: the render-only layout with heights drawn closer together is kept, with the note on the hero render | Amish: "APPROVED: The open decisions from the last wave (TremorTrace to ZeerBox) came in after the review and aren't on the page either." | `docs/REVIEW.md`, 2026-09-26, item 1 |
| 2026-10-02 | Status light: one low-duty LED behind a lens in the shield front, with an open-bottom slot so the shield still slides off (carried out 2026-10-02: lens unit in a 12.2 mm slot, BOM line 21, USD 2 plus a gland USD 1) | Amish: "APPROVED: The open decisions from the last wave (TremorTrace to ZeerBox) came in after the review and aren't on the page either." | `docs/REVIEW.md`, 2026-09-26, item 2 |
| 2026-10-02 | Enclosure lid: a clear-lid enclosure is accepted, and BOM line 3 says so | Amish: "APPROVED: The open decisions from the last wave (TremorTrace to ZeerBox) came in after the review and aren't on the page either." | `docs/REVIEW.md`, 2026-09-26, item 3 |
| 2026-10-02 | First co-design partner and region: a scheme operator that runs chlorinated, solar-powered piped schemes with public tapstands; the first candidate to approach is Water Mission, which runs such schemes in East Africa, with the first region taken from its country programs | Amish: "APPROVED: The open decisions from the last wave (TremorTrace to ZeerBox) came in after the review and aren't on the page either." | WWT-DDR-001, O1 |
| 2026-10-02 | Alert language and recipients: alerts go by SMS in the site's main local language, with an English copy to the operator, stating only what was measured, when and the threshold crossed; they go to the caretaker and the operator's maintenance contact, with a weekly summary to the district water officer | Amish: "APPROVED: The open decisions from the last wave (TremorTrace to ZeerBox) came in after the review and aren't on the page either." | WWT-DDR-001, O2 |
| 2026-10-02 | Data ownership: the scheme operator owns the data; the water committee and the district water and health offices can see it; anonymized site data are published only with the operator's written agreement | Amish: "APPROVED: The open decisions from the last wave (TremorTrace to ZeerBox) came in after the review and aren't on the page either." | WWT-DDR-001, O3 |

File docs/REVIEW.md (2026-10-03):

# Review note: WaterWatch

## Session 2026-09-25: /populate to a strong TRL 2 (overnight batch run)

Amish was not available during this run, so every choice below is recorded as proposed, awaiting Amish.

### What was done

- `docs/01-problem.md` (WWT-PRB-001 v0.2): the problem with cited figures (2.1 billion people without safely managed drinking water; chlorine and turbidity guidance), users and context, constraints, out of scope, prior work, co-design checklist, open questions.
- `docs/03-requirements.md` (WWT-REQ-001 v0.2): 13 measurable requirements (R1 to R13) with targets, planned verification and concept status.
- `docs/02-concept.md` (WWT-PRC-001 v0.2): how it works, components table numbered to the BOM and exploded view, first-order numbers with assumptions, design choices with options, safety, open questions.
- `cad/src/concept_media.py`: massing model of the pole, 5 W panel, enclosure and lid, battery, controller, modem, antenna, flow-through cell, turbidity head, chlorine sensor, temperature probe, latching valve, sample line, drain hose and cables, beside an existing tapstand (grey, not in the BOM). The scene is shifted so the enclosure sits near the origin, because the kit's cutaway cutter is centered on the origin.
- `media/`: hero with a 1.75 m person, blueprint sheet (PNG, PDF, SVG), cutaway, exploded view with BOM callouts, sample and data flow diagram (estimates marked), `model.glb` and `viewer.html`.
- `bom/bom.csv`: 16 lines with indicative prices, numbered to match the exploded view; `bom/bom-notes.md` updated.
- `README.md`: hero image, links line, concept paragraph, key components and safety updated.
- `docs/pdf/`: branded PDFs of the three controlled documents.
- `project.yaml`: unchanged. The pitch and problem still match the concept.

### Key results (estimates, to be checked at TRL 3)

| Quantity | Estimate | Requirement |
| --- | --- | --- |
| Daily energy | about 0.5 Wh (0.32 Wh plus 50 % margin) | |
| Autonomy without sun | about 30 days on 3.2 V, 6 Ah LiFePO4 | R7 met (7 days) |
| Solar refill, 5 W panel | about 13 Wh per clear day; about 1.2 days from empty | R7 met |
| Water to drain | about 0.75 L per reading, about 18 L/day | R8 met (20 L), thin margin |
| Data | under 1 MB per month | R6 met |
| Parts cost | about $270 | R12 met, about $30 margin |
| Shared calibration kit and airtime | about $60 once; about $1 to $3 per month | Outside the unit budget |

Requirements not met on present evidence:

- **R1, free chlorine accuracy.** No low-cost membrane-free sensor has shown months of unattended accuracy at the ±0.1 mg/L level, and the reading depends on pH, which the base design does not measure.
- **R10, monthly maintenance.** The chlorine sensor's drift and recalibration interval are unknown.

At risk: R2 (turbidity accuracy under fouling and bubbles in continuous use) and R9 (enclosure and battery temperature in full sun).

### Proposed, awaiting Amish

(Record of the TRL 2 run. Items 1 to 8 and 10 were decided by Amish, 2026-09-25: go with recommendation (WWT-DDR-001, D1 to D10); item 9, the first partner, stays proposed, awaiting Amish (WWT-DDR-001, O1).)

1. **Chlorine sensor.** (a) Membrane-free graphite three-electrode sensor with a potentiostat front end, about $25; (b) industrial membrane amperometric probe, about $1,900, over budget; (c) ORP probe as a proxy, about $175 as a kit, loose correlation. Recommendation: (a), with a monthly DPD comparison.
2. **pH.** (a) Site pH entered at installation and checked monthly; (b) add a pH probe (about $60 to $100, estimate), raising parts to about $330 to $370, over the $300 budget. Recommendation: (a) now, (b) as a documented variant. If Amish prefers (b), the budget in `project.yaml` would need to rise to about $375; that change is proposed only, and `project.yaml` is unchanged at $300.
3. **Connectivity.** Cellular LTE-M and NB-IoT with 2G fallback and SMS alerts (recommended), with a LoRaWAN module as a swappable variant.
4. **Mounting.** Separate pole beside the tapstand (recommended) rather than on the tapstand itself.
5. **Sampling.** Hourly 90 s timed flush with a latching valve (recommended) rather than continuous flow (about 720 L/day).
6. **Default alert thresholds.** Free chlorine below 0.2 mg/L and turbidity above 5 NTU, two consecutive readings, adjustable per site.
7. **Drain destination.** Tapstand basin by default; soakaway or a container for non-drinking use per site.
8. **First site type.** Tapstands first; tank outlets and kiosks later.
9. **First partner.** A rural utility or maintenance service provider already using handpump sensors, a WASH NGO running chlorinated piped schemes, or a university WASH research group. Recommendation: a maintenance service provider, because alerts only help if someone is paid to act on them.
10. **SwapCell.** Not proposed; WaterWatch needs under 1 Wh per day, and a 48 V pack does not fit.

### Safety concerns

- The biggest risk is false reassurance: a normal reading must never be presented as "safe water". Alert wording is a requirement (R13).
- Backflow into a drinking water supply: an isolation valve, a check valve and food-safe wetted parts are in the concept; they need review against local plumbing rules.
- LiFePO4 battery in a sun-heated box: protection board, fuse and charging temperature cut-offs are in the concept; the enclosure temperature is not yet estimated.
- Calibration chemicals (DPD reagents, turbidity standards): prepared, stabilized standards only; no formazin preparation in the field.

### Gaps and notes

- Some sources could not be opened in full during this run (access limits on publisher sites). The long-term low-cost chlorine sensor study (Water Science and Technology, 2025) and the Rwanda handpump study are cited from their titles and abstracts, not the full text; check them at TRL 3.
- Several prices, including items 6, 9, 10 and 11, are rough estimates without a named supplier listing.
- The exploded view is dense around the flow-through cell; small callouts (10 to 12) partly cover their parts.

### Recommended next step

Review this note and the media. If Amish approves, run `/advance-trl3` to review the low-cost chlorine sensor literature for drift and pH effects, size the energy and thermal budgets by calculation, estimate the enclosure temperature, and produce the parametric model and drawing sheet.

## Session 2026-09-25: TRL 3

Amish reviewed the TRL 2 review points on 2026-09-25 and wrote: "proceed with all of your recommendations across all batches. Make sure we don't proceed to TRL 4 on any of them." This session ran `/advance-trl3` on that instruction and stopped at TRL 3.

### What was done

- `docs/decisions/0001-trl2-review-decisions.md` (WWT-DDR-001 v0.1): ten items decided by Amish on 2026-09-25, going with the recommendations (D1 to D10), and three items left open (O1 to O3).
- `docs/04-calcs/01-sizing.md` (WWT-CAL-001 v0.1) and `docs/04-calcs/sizing.py`: energy, solar, enclosure temperature, flushing and water use, a free chlorine error budget, turbidity bubbles and settling, data, alert latency, wind on the pole and footing, installation and maintenance task times, and cost, with a status for every requirement. The script imports the model's parameters and reads the BOM and `project.yaml`; every number in the note is printed by it.
- `cad/src/model.py`: parametric build123d model (pole and footing, panel, enclosure and contents, sun shield, flow cell with ports and baffle, sensors, valve, sample line from the riser tee, drain with air break). Exports `cad/step/` and `cad/stl/` for `waterwatch-assembly`, `flow-cell` and `enclosure`.
- `cad/src/sheets.py` and `cad/drawings/WWT-DWG-001.svg`, `.pdf`, `.png`: general arrangement at Rev P1, 1:25, marked "CONCEPT, NOT FOR FABRICATION" and "PRELIMINARY, NOT FOR FABRICATION". WWT-DWG-001 was free because the concept blueprint is WWT-DWG-010.
- `bom/bom.csv` (17 lines, all priced with a supplier type, $282.00) and `bom/bom-notes.md`.
- `cad/src/concept_media.py` now builds from the model; all of `media/` was re-rendered and every image checked. The cutaway now cuts on the cell's center plane (a project-side wrapper; the kit is unchanged) so the cavity and both sensors show.
- WWT-PRB-001, WWT-PRC-001 and WWT-REQ-001 revised to v0.3; `README.md` and `project.yaml` (`trl: 3`, `trl_target: 3`, evidence list) updated. PDFs rebuilt in `docs/pdf/`.

Design changes found necessary by the calculations, all within the decided choices: the flow cell is halved to 0.19 L of water (the TRL 2 cell kept 17 % old water at the chlorine reading); a pressure-compensating 0.5 L/min regulator replaces the fixed restrictor (a restrictor would pass 36 L/day at 4 bar); the outlet sits near the top with an open air break so the cell stays full and cannot siphon; the valve is specified direct acting for 0.5 bar sites; the bubble wait before the turbidity reading rises from 10 s to 30 s; SMS retries are at 3 min spacing; and a ventilated sun shield (item 17, $8) is added.

### Requirement status (WWT-CAL-001, Table 4)

2 not met, 3 at risk, 5 met on paper, 3 met by design.

| ID | Status | Key number |
| --- | --- | --- |
| R1 Free chlorine | **Not met** | ±0.131 mg/L at 0.5 mg/L and pH 7.5 with site pH, before sensor drift (target ±0.1); met only at pH 7.0 |
| R10 Maintenance | **Not met** on present evidence | Visit 30 min, at the limit; monthly interval needs drift below about 0.04 mg/L per month, unknown |
| R2 Turbidity | At risk | Bubbles handled by the 30 s wait; window fouling unknown |
| R9 Outdoors | At risk | 50.8 °C inside on a 45 °C day with the shield, 69.8 °C without; shield factor assumed |
| R11 Installation | At risk | 140 min critical path with the footing cast on the day (target 120 min); 65 min if cast earlier |
| R5, R6, R7, R8, R12 | Met on paper | 13.0 min to SMS; 0.86 MB/month; 28.6 days autonomy, 1.18 days to refill; 18.0 L/day (19.8 L at tolerance); $282 of $300 |
| R3, R4, R13 | Met by design | DS18B20 ±0.5 °C; 15 min schedule within energy; wording rule |

Key numbers: 0.537 Wh/day; 13.5 Wh per clear day from the 5 W panel; pole 52 MPa (factor 4.5) and footing factor 4.9 in a 35 m/s gust.

### Decisions recorded (WWT-DDR-001)

Decided by Amish, 2026-09-25, going with the recommendation: D1 membrane-free graphite chlorine sensor with monthly DPD comparison; D2 site pH, pH probe as a variant, budget unchanged at $300; D3 cellular with LoRaWAN as a swappable variant; D4 separate pole; D5 hourly 90 s timed flush; D6 defaults of 0.2 mg/L and 5 NTU, two consecutive readings; D7 drain to the basin by default, per site; D8 tapstands first; D9 LiFePO4 with 0 to 45 °C charging; D10 no SwapCell. No budget, pitch or problem rewording was recommended, so none was applied. The SwapCell interface v0.3 items do not apply to this design.

### Still awaiting Amish

1. **O1, first co-design partner and region.** Left open by Amish's direction that community designs pick partners per area later.
2. **O2, alert language and recipients; O3, data ownership.** No recommendation was made; for co-design.
3. **New, R1 target.** Options: (a) keep ±0.1 mg/L and accept that R1 is not met; (b) relax to ±0.2 mg/L or ±25 %, whichever is greater, which the design meets with site pH up to pH 7.5 at zero drift (WWT-CAL-001, E6); (c) keep the target and make the pH probe standard, which exceeds the budget. Recommendation: (b), because the DPD field reference alone takes ±0.07 of the ±0.1 mg/L budget. Decided by Amish, 2026-09-25: go with recommendation (WWT-DDR-002, D11).
4. **New, pH probe trigger.** Recommendation: fit the pH probe variant at sites whose pH is above 7.5 or moves more than 0.2 between visits. Decided by Amish, 2026-09-25: go with recommendation (WWT-DDR-002, D12).

Suggestions at the time (now decided by Amish, 2026-09-25: go with recommendation, WWT-DDR-002, D13 and D14): a confirming reading 15 min after a first threshold crossing would cut the worst case from event to SMS from 122 min to 77 min (WWT-CAL-001, H2); casting the footing on a survey visit would bring installation to about 65 min.

### Safety concerns

- False reassurance remains the biggest risk: R1 is not met, so a low chlorine reading could be missed at high-pH sites. Alerts must stay worded as measurements (R13), and the monthly DPD test stays part of the routine.
- Battery heat: without the sun shield the enclosure reaches about 70 °C on a 45 °C day, above typical LiFePO4 discharge limits. The shield is essential, and its benefit is assumed, not measured.
- Backflow and cross-connection: the check valve, isolation valve and the new open air break at the outlet need review against local plumbing rules; fitting the saddle tee needs the supply shut off or a tool for tapping under pressure.
- Calibration chemicals: prepared, stabilized standards only; no formazin preparation in the field.

### Gaps and notes

- Citations: a web search on 2026-09-25 confirmed the titles and venues of "Long-term performance of low-cost free chlorine sensors to monitor on-site water reuse" (Water Science and Technology, 2025, doi 10.2166/wst.2025.090) and the Rwanda handpump study (Nagel et al., Environmental Science and Technology 49(24), 2015, doi 10.1021/acs.est.5b04077). Neither the full text nor the abstract could be opened (publisher 403, a CAPTCHA on PubMed, and the proxy blocked Europe PMC), so their findings, and in particular any drift data for R1 and R10, remain unchecked.
- Assumptions that only tests can settle: the sun shield factor, sensor drift, pH movement between visits, and window fouling.
- The exploded view is still dense around the flow cell: callouts 9 to 12 partly cover their small parts.
- Existing material beyond TRL 3: `build-log/README.md` (scaffold) is present, untouched and not extended. No test, build or firmware material exists.

### Recommended next step

TRL 4 is on hold by Amish's instruction; this repo stops at TRL 3. Amish's review is needed on the R1 target and the pH probe trigger above. For the record only, TRL 4 would need: a bench build of the flow cell, chlorine sensor and turbidity head; a lab test report (TST, `environment: lab`) of chlorine accuracy and drift against DPD over pH 6.5 to 8.5, turbidity against stabilized standards with bubbles and fouling, and enclosure temperature with and without the shield in sun; and build log entries. None of this has been started.

## Session 2026-09-25: recommendations accepted

Amish wrote on 2026-09-25: "i accept all your recommendations, go with them across all repos." Every item with a recommendation is now decided by Amish, 2026-09-25: go with recommendation. Items without one stay proposed, awaiting Amish. Recorded in `docs/decisions/0002-recommendations-accepted.md` (WWT-DDR-002 v0.1).

### Decisions applied and what changed

| # | Decision | Before | After |
| --- | --- | --- | --- |
| D11 | Relax R1 to ±0.2 mg/L or ±25 %, whichever is greater | ±0.1 mg/L below 1.0 mg/L, ±15 % above; 2 of 8 cases met at zero drift; 0.038 mg/L left for drift | 8 of 8 cases met at 25 °C and zero drift (with D12); at least 0.130 mg/L left for drift; R10 drift allowance about 0.13 mg/L per month (was 0.04) |
| D12 | pH probe variant where site pH is above 7.5 or moves more than 0.2 between visits | No port for a probe | Spare 12 mm port with blanking plug in the cell lid; BOM item 9 $12 to $13; parts $282 to $283; variant site $343 to $383, priced outside the base-unit budget (R12 restated) |
| D13 | Confirming reading 15 min after a first threshold crossing (firmware rule) | 122 min worst case from event to SMS | 77 min; 9.7 mWh and 0.75 L per event |
| D14 | Cast the pole footing on the survey visit | 140 min critical path on installation day | 65 min; R11 restated as 2 h on installation day |

Budget: `budget_usd` unchanged at $300; no budget change was recommended. Pitch and problem in `project.yaml` unchanged; `trl: 3` and `trl_target: 3`.

Files changed: `cad/src/model.py` (plugged pH port; STEP and STL re-exported), `cad/src/sheets.py` and WWT-DWG-001 (Rev P1 to P2), `bom/bom.csv` and `bom/bom-notes.md`, `docs/04-calcs/sizing.py` and WWT-CAL-001 (v0.1 to v0.2: new sections E4 to E8, H2, H3, J2, K2 and Table 4), WWT-REQ-001 (v0.3 to v0.4: R1, R5, R11 and R12 restated), WWT-PRC-001 (v0.3 to v0.4), WWT-DDR-001 (v0.1 to v0.2), `cad/src/concept_media.py` and all of `media/` regenerated, `README.md` (new write-up sections before "Problem"), `project.yaml` (DDR-002 added to the evidence list), all PDFs in `docs/pdf/` rebuilt.

### Requirement status (WWT-CAL-001 v0.2)

0 not met, 4 at risk, 6 met on paper, 3 met by design (before: 2 not met, 3 at risk, 5 met on paper, 3 met by design).

| ID | Status | Key number |
| --- | --- | --- |
| R1 Free chlorine | **At risk** (was not met) | 8 of 8 cases at 25 °C before drift; 1.5 mg/L at pH 7.5 and 40 °C with site pH misses by 0.006 mg/L; drift unknown |
| R10 Maintenance | **At risk** (was not met) | Visit 30 min, at the limit; needs drift below about 0.13 mg/L per month, unverified |
| R2 Turbidity | At risk | Window fouling unknown |
| R9 Outdoors | At risk | 50.8 °C inside on a 45 °C day with the shield; shield factor assumed |
| R11 Installation | Met on paper (was at risk) | 65 min on installation day |
| R5, R6, R7, R8, R12 | Met on paper | 13.0 min to SMS (77 min from the event); 0.86 MB/month; 28.6 days; 18.0 L/day; $283 of $300 |
| R3, R4, R13 | Met by design | |

### Still awaiting Amish

- O1, first co-design partner and region (no choice made; partners are picked per area later).
- O2, alert language and recipients; O3, data ownership. No recommendation was made for either.

### Cross-repo actions

None. No decision in this repo needs a change in another repo.

### Other changes in this session

- Every generated file was re-rendered so that the footer shows designmolecule.com: `docs/pdf/`, WWT-DWG-001 and `media/`. The hero, blueprint and exploded images were checked after rendering.
- `README.md` gained "Concept rationale", "Burning platform", "Where it could be used" and "What sparked the idea". The inspiration point is the Walkerton, Ontario outbreak of May 2000 and Part One of the Walkerton Inquiry (2002). The inquiry report itself could not be opened from this environment (access blocked); its figures are cited as summarized, with the report's archive link.

### TRL 4

TRL 4 remains on hold by Amish's instruction. Nothing was built, bought, tested or programmed. D13 is recorded as a firmware rule only. The drift test that would settle R1 and R10 is TRL 4 work and has not started.

## Session 2026-09-26: sources strengthened

Amish asked to fix the weaker sources in the README (2026-09-26). Every new link below was fetched and checked against the claim it supports. No controlled document changed; `docs/01-problem.md` did not cite the replaced sources.

| Where | Old source | New source |
| --- | --- | --- |
| Country row, India (was "South Asia (Bangladesh, India)") | None | [UNICEF India, clean drinking water](https://www.unicef.org/india/what-we-do/clean-drinking-water): rural tap connections 17 % to over 49 % (2019 to 2022); under 49 % of rural people use safely managed water. Bangladesh and the uncited monsoon and intermittent-chlorination claims were dropped |
| Country row, Honduras (was "Andean and Central American rural schemes") | None | Lindmark et al., ACS ES&T Water 2023 ([PubMed 38094914](https://pubmed.ncbi.nlm.nih.gov/38094914/)): passive tank chlorinators run by community water boards; 77 % of samples at or above 0.2 mg/L; board errors 39 % of lapses; circuit-rider visits correlated with better chlorination |
| Country row, Canada (Walkerton) | Walkerton Inquiry Part One on archives.gov.on.ca (could not be opened from this session) | [CBC News, highlights of the Walkerton Inquiry report](https://www.cbc.ca/news/canada/highlights-of-the-walkerton-inquiry-report-1.867604): residuals not measured daily, seven deaths, 2,300 ill |
| What sparked the idea (Walkerton) | Walkerton Inquiry Part One (archives.gov.on.ca, unopened) plus Wikipedia summary | CBC News (above) and the [National Academies workshop summary, Lessons from Waterborne Disease Outbreaks](https://www.ncbi.nlm.nih.gov/sites/books/NBK28459/). The residual range "0.12 to 0.4 mg/L" and "weekly instead of daily" tests could not be verified in a credible source and were removed; the text now states what CBC and the National Academies report: 0.5 mg/L required after 15 min, too little chlorine used, residuals not measured on most days, false entries, seven deaths, 2,300 ill, and the inquiry's finding that continuous residual and turbidity monitors would have prevented the outbreak |

The inspiration event is unchanged; its line in `INSPIRATIONS.md` was updated to match the verified findings. Kept but not re-opened this session: Nagel et al., ES&T 2015 (publisher returned 403) and the Oxfam WASH chlorination page (fetch refused). No budget change.

## Session 2026-09-26: product appearance model and photoreal renders

Amish chose this repo for the first batch of product renders on 2026-09-26.

### What was added

`cad/src/product_model.py` exposes `product_parts()` (79 parts: 49 shell, 14 internal, 15 accessory, 1 context), `TITLE` and `RENDER_VIEWS` (hero, exploded and a detail view without the tapstand and plumbing). It reuses PARAMS and derived() from `cad/src/model.py`; every part size, the X and Y positions and every interface are as model.py. It adds:

- Sun shield: rounded front and top edges, pressed side louvers, a teal accent band, a printed name plate, a grommet for the antenna and a lit green status light.
- Enclosure: filleted IP66 base with cable glands and a vent plug, a clear polycarbonate lid, a gasket line and four tamper-resistant lid screws.
- Inside: the LiFePO4 pack with a label, fuse holder and a hook-and-loop strap; the controller board (ESP32-S3 module and shield can, charger, potentiostat and boost ICs, microSD and RTC, terminal blocks); the cellular modem board with its module can and SIM holder; the whip antenna.
- Solar panel: aluminum frame, backsheet, cell grid with busbars, junction box, tilt rail, hinge and pole-top bracket.
- Flow cell: filleted black body and top plate, four knurled thumb nuts for the tool-free lid, the teal blanking plug in the spare pH port, a label; the turbidity head with flange, screws, label and gland; the chlorine sensor with gland nut and strain relief; the temperature probe with its fitting.
- Plumbing: saddle tee, isolation ball valve with lever, strainer, check valve and regulator, 1/4 in tube, the latching solenoid valve with push-fit ports, the inlet fitting, the outlet elbow with its open air-break vent, and the drain hose and clamp.
- Pole section with band clamps, mounting plates and a top cap; sensor and panel cables.
- Context (not in the BOM): a short section of the tapstand riser with its tap.

`README.md` now shows `media/render-hero.png` and links `media/render-exploded.png`; the orchestrator produces both files.

### Differences from model.py (Proposed, awaiting Amish)

1. **Render layout of heights.** Installed, the parts spread over 2.2 m of pole, which makes each part small in a product render. The appearance model keeps the enclosure at its model.py height and draws the panel and pole top 520 mm lower, the flow cell 130 mm higher and the saddle tee and valve 350 mm higher (tee at 850 mm instead of 500 mm). The pole, riser and drain hose are shown as short sections, and the sample tube is rerouted to suit. All sizes and X and Y positions are unchanged. Proposed, awaiting Amish. Recommendation: keep this as a render-only layout (the hero note says heights are drawn closer together than installed); the installed heights stay as in model.py and WWT-DWG-001.
2. **Status light.** model.py and the BOM have no status light. The appearance model shows a lit green lens in the shield front, which would be fed by a light pipe from an LED on the controller board (BOM line 6). Proposed, awaiting Amish. Recommendation: adopt a single low-duty status LED behind a lens in the shield, with an open-bottom slot so the shield still lifts off; its power draw is negligible against the 0.54 Wh per day budget but should be added to WWT-CAL-001 if adopted. Option: omit the light and show nothing lit.
3. **Clear enclosure lid.** BOM lines 3 and 4 specify an IP66 polycarbonate enclosure without saying whether the lid is clear. The appearance model uses a clear lid so the exploded view shows the board, battery and modem; under the sun shield a clear lid gains no sun load. Proposed, awaiting Amish. Recommendation: accept a clear-lid enclosure (common and similar in price) and add "clear lid" to BOM line 3 at the next BOM revision; the BOM was not edited now.
4. **Panel cable gland on the enclosure top.** model.py brings the panel cable to the enclosure top but shows glands only underneath. The appearance model adds a fourth, small gland on the top, under the shield. Proposed, awaiting Amish. Recommendation: accept; it is within BOM line 16 (glands). Option: route the panel cable down the pole to a fourth gland underneath, which keeps all entries on the bottom face.
5. **Appearance detail only.** The louvers, labels, thumb nuts, strap and fixings are appearance detail within the existing BOM lines; no new BOM lines are implied. The flow cell stays opaque black, as the turbidity measurement requires.

### Status

This is an appearance model only: no tolerances, no fabrication detail, nothing past TRL 3. `trl: 3` and `trl_target: 3` are unchanged, and TRL 4 remains on hold. model.py, the BOM and the other documents were not edited.

## Session 2026-09-27: kit 1.5.0 and image quality

- Kit 1.5.0 synced: STANDARDS v1.5 (sections 12 to 15: product renders, storefront images and image quality, public release, authorship and signing), `.kit/cards.py`, `.kit/image_qc.py`, `.kit/release_gate.py`, issue templates, and the `/render-product` and `/release` commands. `CLAUDE.md` now matches `.kit/CLAUDE.md`.
- Every `media/render-*.png` recaptioned from its original render with the new layout: the title, concept label and repository sit in a band above the render and the view note in a band below it, each line wrapped to the image width, so no text overlaps other text or the render or runs off the image. `media/card.png` and `media/social-preview.png` regenerated with the same rules.
- `python .kit/image_qc.py` and `python .kit/release_gate.py` pass. trl stays 3.

## Session 2026-10-02: kit 1.7.0, constructable design and prototype build plan

Amish approved the build plan format on 2026-09-30 and asked for it in every repo, with outstanding decisions kept in a separate register, and wrote: "If you are realising that the design cannot be built as per concept - fix the design assumptions to match and be physically feasible as you draw the illustrations." On 2026-10-01 he set budgets as value-engineering targets. This session applied both to WaterWatch. Nothing was built, bought or tested; `trl` stays 3.

### What was done

- Kit 1.7.0 installed (`.kit/`, `.claude/commands/`); `CLAUDE.md` now matches `.kit/CLAUDE.md`.
- Constructability review with build123d: `cad/src/model.py` rewritten to separate components and now runs 97 checks (`python cad/src/model.py --check`: 68 required contacts, 17 clearances, an overlap scan of all 53 parts, the light path in the cell and the standing water level). All pass. STEP and STL re-exported.
- `docs/decisions/0003-design-for-construction.md` (WWT-DDR-003 v0.1, Draft): every change, made under Amish's 2026-09-30 instruction to make the design physically buildable; open for his review.
- `docs/05-build-plan.md` (WWT-BLD-001 v0.1) from the kit template, with `cad/src/build_plan_media.py`: overview, 9 making sketches (`cad/drawings/WWT-DWG-101` to `109`), 3 drilling layouts, a wiring diagram, 12 joint close-ups and 18 assembly step pictures in `docs/05-build-plan/`.
- `docs/06-design-decisions.md` (WWT-DEC-001 v0.1): 10 open decisions, 8 items to confirm when parts are bought, a value engineering section and the decisions made.
- WWT-DWG-001 Rev P3 to P4; WWT-CAL-001 v0.2 to v0.3; WWT-REQ-001 v0.4 to v0.5; WWT-PRC-001 v0.4 to v0.5; `bom/bom.csv` (20 lines) and `bom/bom-notes.md`; `README.md` (links line, "Building the prototype", value-engineering wording); `project.yaml` (`design_state: constructable`, three evidence files added; `budget_usd` unchanged at 300). Three BOM rows that had unquoted commas in their notes were re-quoted.
- Concept media regenerated from the new model (`media/hero.png`, `cutaway.png`, `exploded.png`, `flow.png`, `concept-blueprint.*`, `model.glb`). PDFs rebuilt.

### Design changes made for construction (WWT-DDR-003)

1. P1. The solid concept plates and loose clamp rings became two 3 mm aluminium back plates, each on two M8 U-bolts with V-saddles; the pole axis moves from 94 to 103 mm behind the enclosure centre.
2. P2. The enclosure hangs on the maker's four lugs, one M5 screw each.
3. P3. A printed internal plate on the box's moulded bosses carries the battery, controller and modem.
4. P4. Every entry is in the bottom face: six glands (one a plugged spare for the pH probe), the vent and the antenna, which now points down; the panel lead runs down the back of the pole.
5. P5. The sun shield has flanges and four thumb screws and slides off forward.
6. P6. The turbidity optics are three holders on three walls (LED, 90° and 180° detectors); the baffle, unchanged in size, moved to the back wall so the beam is clear.
7. P7. The lid glands were laid out so none overlaps and every probe clears the beam and the baffle.
8. P8. The cell lid has a gasket, four studs and thumb nuts.
9. P9. The cell's back wall is 14 mm (body 60 deep instead of 54) and takes two M5 screws from behind the plate; the cavity and its volume are unchanged.
10. P10. The valve is screwed to the cell plate under the cell; the tube run falls from 738 to 696 mm.
11. P11. The panel sits on a bought pole-top tilt mount.
12. P12. The riser fittings are one screwed brass line with the check valve shown.
13. P13. Every cable has a defined route, clear of every part it is not fixed to.

### Key results

- Estimated cost of the constructable design: USD 319 against the USD 300 value-engineering target (USD 19 over); the construction parts added USD 36. A pH probe variant site: USD 379 to 419.
- Requirement status (WWT-CAL-001 v0.3): none not met; 4 at risk (R1, R2, R9, R10); 5 met on paper; 3 met by design; R12 over the value-engineering target by USD 19. No other status changed. The tube change moves two chlorine error figures by 0.001 mg/L.

### Open decisions (in WWT-DEC-001)

Review of WWT-DDR-003; shield thumb screws at public sites; antenna position; water volume basis in the calculation; and, carried over, the render layout, status light and clear lid (2026-09-26) and O1 to O3. All proposed, awaiting Amish.

### Picture notes

- The concept exploded view (`media/exploded.png`) is still dense around the small flow cell parts (callouts 9 to 12), although they were pulled further apart; the build plan overview shows them clearly.
- Some joint close-ups have leader lines that end close together where a part is mostly hidden behind another (joints 2, 4 and 5); the captions in the plan say which face meets which.

### Stale until regenerated on Amish's Mac

`media/render-*.png`, `media/card.png` and `media/social-preview.png` are to be made again on Amish's Mac from the render scenes exported on 2026-10-02 (see "Approved follow-ups carried out" below). The appearance model `cad/src/product_model.py` was brought in line with `model.py` on 2026-10-02 (optics holders, antenna and entries in the bottom face, back plate size, status light).

### Safety

No change to the safety case. The plan adds safety stops for the battery, the connection to the drinking water supply (supply shut off, check valve direction, air break), the concrete footing and work at height. The shield now comes off by hand (open decision 2).

### Recommended next step

Amish reviews WWT-DDR-003 and the open decisions in WWT-DEC-001, and has the photoreal renders regenerated on the Mac. TRL 4 (building to the plan and testing) remains on hold.

## Session 2026-10-02: open decisions decided

Amish, 2026-10-02: "APPROVED: The open decisions from the last wave (TremorTrace to ZeerBox) came in after the review and aren't on the page either." This approves the recommendation written for each open decision in the design decisions register (WWT-DEC-001), as he did for the other 555 open decisions ("i approve your recommendations for all 555 open decisions."). trl stays 3; no build or test work was done, and the model, BOM quantities and prices, and pictures are unchanged.

### Decisions recorded

Ten decisions, all moved to Decisions made in WWT-DEC-001, dated 2026-10-02:

1. Design for construction accepted: the changes P1 to P13 of WWT-DDR-003, as made.
2. Shield fixing: knurled thumb screws for the prototype; tamper-resistant M5 screws on field units after the first site visit.
3. Antenna: the whip points down from the bottom face, and signal strength is measured at TRL 4; a pole-top antenna is used only at a weak-signal site.
4. Water volume in the calculation: the full-cavity 0.185 L is kept, conservative for flushing; the standing volume is measured at TRL 4.
5. Product render layout: the render-only layout with heights drawn closer together is kept, with the note on the hero render.
6. Status light: one low-duty LED behind a lens in the shield front, with an open-bottom slot so the shield still slides off.
7. Enclosure lid: a clear-lid enclosure is accepted, and BOM line 3 says so.
8. First co-design partner and region: a scheme operator that runs chlorinated, solar-powered piped schemes with public tapstands; the first candidate to approach is Water Mission, which runs such schemes in East Africa, with the first region taken from its country programs.
9. Alert language and recipients: alerts go by SMS in the site's main local language, with an English copy to the operator, stating only what was measured, when and the threshold crossed; they go to the caretaker and the operator's maintenance contact, with a weekly summary to the district water officer.
10. Data ownership: the scheme operator owns the data; the water committee and the district water and health offices can see it; anonymized site data are published only with the operator's written agreement.

### Documents changed

- `docs/06-design-decisions.md` (WWT-DEC-001 v0.2): open decisions moved to Decisions made.
- `docs/decisions/0003-design-for-construction.md` (WWT-DDR-003 v0.2): acceptance recorded in the status line; A1 to A3 decided (record stays Draft).
- `docs/decisions/0001-trl2-review-decisions.md` (WWT-DDR-001 v0.3) and `docs/decisions/0002-recommendations-accepted.md` (WWT-DDR-002 v0.2): O1 to O3 recorded as decided.
- `docs/01-problem.md` (WWT-PRB-001 v0.4): partner, alert and data questions answered.
- `docs/02-concept.md` (WWT-PRC-001 v0.6): open questions answered.
- `bom/bom.csv` (line 3 specification text only: clear lid; no quantity or price change).
- `README.md`: the build plan paragraph says WWT-DDR-003 is accepted and the decisions are all made.

### Follow-up actions to carry approved decisions into the design

1. Decision 6 (model): Model the status LED and its lens in the shield front, with the open-bottom slot so the shield still slides off, and check its clearance to the enclosure.
2. Decision 6 (BOM): Add the status LED, lens and lead to the BOM with a price basis.
3. Decision 6 (calculations): Add the LED's low-duty energy to the energy budget in WWT-CAL-001.
4. Decision 6 (pictures): Show the status LED and its wiring in the general arrangement, the build plan's shield and wiring pictures and the concept media.
5. Decision 2 (docs): Name tamper-resistant M5 shield screws as the field-unit fixing in the build plan's shield step and BOM line 20 note when field units are planned.
6. Decision 9 (docs): Write the alert message templates (SMS, local language with an English copy) and the recipient list into the firmware settings notes.
7. Decisions 8, 9 and 10 (docs): Approach Water Mission, choose the first region from its East African country programs, and confirm the alert and data defaults with the operator and caretakers.

### Points found in the review

- None.

## Session 2026-10-02: approved follow-ups carried out

Amish approved on 2026-10-02 that every follow-up action from the open-decision sign-off be carried out. `trl: 3` is unchanged; no build or test work was done.

### Follow-ups

1. Done. Decision 6, model: the status light is in `cad/src/model.py` (parts `status_lens`, `status_holder`, `status_led`, `status_cable`): a 16 mm lens and printed holder whose 12 mm barrel sits in a 12.2 mm slot, open at the bottom, in the shield front panel (round end 10 mm above the lower edge); the lead hangs to a seventh gland in the bottom face (middle row, centre line). The unit drops out of the slot downward, so the shield still slides off forward. Interpretation recorded: the decision text does not say where the lead goes or how the unit is held, so this is the reading chosen. New checks: 7 touches and 2 clearances (holder 10 mm or more from the clear lid; lead 20 mm or more from the antenna); 106 of 106 checks pass; STEP and STL regenerated.
2. Done. Decision 6, BOM: line 21 (USD 2.00; LED about 0.40, lens disc 0.40, printed holder 0.30, lead with crimps and resistor 0.90) and a seventh gland on line 16 (USD 19.00, +1.00).
3. Done. Decision 6, calculations: WWT-CAL-001 v0.4 and `sizing.py`: 5 mA for 50 ms every 10 s adds 1.98 mWh a day; daily need 0.540 Wh (was 0.537), autonomy 28.5 days (was 28.6).
4. Done. Decision 6, pictures: WWT-DWG-001 Rev P5 (status light leader and note); shield sketch WWT-DWG-104 and enclosure sketch WWT-DWG-102; bottom-face drilling layout; joint 3; steps 1, 17 and 18; new step 19; overview; wiring diagram; concept media (new line 21 in the exploded view).
5. Done. Decision 2, docs: tamper-resistant M5 screws named for field units in the build plan (shield section and steps 18) and in the BOM line 20 note (about USD 2 a unit, not in the total).
6. Done. Decision 9, docs: alert message templates (five, English copy; the local language text is translated with the caretakers) and the recipient list are in WWT-DDR-001 v0.4, section "Firmware settings notes". The repo has no firmware sketch (TRL cap), so the notes live in that record.
7. Not done: decisions 8, 9 and 10, approach Water Mission, choose the first region and confirm the defaults with the operator and caretakers; this is outreach by Amish.

### Other changes

- Value-engineering target: USD 300. Estimated cost of the constructable design: USD 322 (USD 22 over the target), 21 lines (was USD 319, 20 lines). `budget_usd` unchanged. The pH probe variant site is now about USD 382 to 422.
- Requirement status changes: none. R7 is still met on paper (28.5 days); R12 is still over the target, by USD 22.
- Appearance model (`cad/src/product_model.py`) was stale against the constructable model and did not run (it read a turbidity parameter that no longer exists). Now it takes the three optics holders from `model.py`, puts the antenna and all entries in the bottom face at the model's positions, sizes the enclosure back plate from `model.py`, and shows the status light in the slot with its lead (the green light moves from the upper right of the shield front to the bottom centre). Still render-only, kept by Amish's decision of 2026-10-02: heights drawn closer together, the cell back bar, the pole clamps in place of U-bolts and saddles, and the louvers on the shield. Render scenes exported to `/home/claude/renders/waterwatch` (hero, exploded, detail, with `waterwatch__jobs.json`); photoreal renders, `media/card.png` and `media/social-preview.png` are for Amish's Mac.

### Cross-repo actions

- None needed in other repos for the status light. Water Mission outreach and the first region are Amish's.

### Documents changed

WWT-CAL-001 v0.4, WWT-REQ-001 v0.6, WWT-PRC-001 v0.7, WWT-DDR-001 v0.4, WWT-DDR-003 v0.3, WWT-DEC-001 v0.3, WWT-BLD-001 v0.2, README, `bom/bom.csv`, `bom/bom-notes.md`, WWT-DWG-001 Rev P5.

## 2026-10-02: photoreal renders redone on the constructable design

Rendered with Blender Cycles on Amish's Mac from the updated appearance model; captioned with `.kit/photo_caption.py`; `media/card.png` and `media/social-preview.png` regenerated with `.kit/cards.py`. Views: hero, exploded, detail. image_qc passes. Appearance deviations are those logged above as proposed, awaiting Amish.

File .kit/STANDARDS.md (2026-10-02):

---
doc_id: OHP-STD-001
title: Documentation and drawing standard
project: Open Hardware Portfolio
doc_type: Standard
version: "1.7"
status: Released
date: 2026-09-30
author: Amish Chadha
license: CC-BY-SA-4.0
revisions:
  - version: "1.0"
    date: 2026-09-24
    author: Amish Chadha
    change: First release of the standard
  - version: "1.1"
    date: 2026-09-24
    author: Amish Chadha
    change: Adopt Technology Readiness Levels (section 9) for project maturity
  - version: "1.2"
    date: 2026-09-24
    author: Amish Chadha
    change: Portfolio phase cap (section 10), concept media standard (section 11), CLAUDE.md guardrails
  - version: "1.3"
    date: 2026-09-24
    author: Amish Chadha
    change: Scale figure, interactive 3D viewer and flow diagrams added to concept media; session slash commands
  - version: "1.4"
    date: 2026-09-26
    author: Amish Chadha
    change: Every sheet and render names the project and its GitHub repository; overall dimensions, ISO centre lines and 300 dpi PNG on sheets; titles name the device and view labels state the viewing direction; optional photoreal renders with Blender
  - version: "1.5"
    date: 2026-09-27
    author: Amish Chadha
    change: Product renders (section 12), storefront images and image quality check (section 13), public release and release gate (section 14), authorship, citation and commit signing (section 15)
  - version: "1.6"
    date: 2026-09-29
    author: Amish Chadha
    change: Licensing metadata with REUSE (section 16), Zenodo DOI and Software Heritage archiving (section 17), release gate checks REUSE and a single CITATION.cff license, archive.py
  - version: "1.7"
    date: 2026-09-30
    author: Amish Chadha
    change: Concept and constructable design states; design decisions register (DEC) kept apart from the build plan; prototype build plan (BLD, section 18) with pictures by component is required TRL 3 evidence; every repo targets TRL 3 during the populate phase; build_views.py; /to-trl3 and /build-plan commands
---

# Documentation and drawing standard

Every project in the portfolio uses this standard, so that each precis, write-up and sketch looks the same and carries its own version history. The standard ships as a kit in each repo's `.kit/` folder. The kit version is in `.kit/KIT_VERSION`.

## 1. Document types and IDs

Every controlled document has a unique ID in the form `PRJ-TYP-NNN`.

- `PRJ` is the three-letter project code listed in section 7.
- `TYP` is the document type code from the table below.
- `NNN` is a sequence number within that project and type, starting at 001.

| Code | Type | Typical file |
| --- | --- | --- |
| PRC | Design precis | `docs/02-concept.md` |
| PRB | Problem statement | `docs/01-problem.md` |
| REQ | Requirements | `docs/03-requirements.md` |
| CAL | Calculation or sizing note | `docs/04-calcs/*.md` |
| DDR | Design decision record | `docs/decisions/*.md` |
| BOM | Bill of materials | `bom/bom.csv` |
| DWG | Drawing or sketch sheet | `cad/drawings/*.svg` |
| BLD | Prototype build plan (section 18) | `docs/05-build-plan.md` |
| DEC | Design decisions register (section 18) | `docs/06-design-decisions.md` |
| TST | Test plan or test report (front matter adds `environment: lab` or `relevant`) | `docs/05-tests/*.md` |

Example: `TBK-PRC-001` is the ThermaBrick design precis.

## 2. Revision scheme

| Artifact | While in draft | When released | Change after release |
| --- | --- | --- | --- |
| Documents | 0.1, 0.2, 0.3 ... | 1.0 | 1.1 for minor edits, 2.0 for a design change |
| Drawings | Rev P1, P2 ... (preliminary) | Rev A | Rev B, C ... |

- Every change to a controlled document adds a row to its revision history before the commit.
- The `version` field in front matter always equals the newest row in `revisions`. The renderer rejects a document where they differ.
- Status is one of `Draft`, `In review`, `Released` or `Superseded`. Draft and In review documents print with a status band on every page.
- Every release is tagged in Git as `<doc_id>/v<version>`, for example `TBK-PRC-001/v1.0`. Drawings are tagged `TBK-DWG-001/revA`.
- Git history is the full audit trail. The in-document revision table is the human-readable summary.

## 3. Document front matter

Every Markdown document under version control starts with this block:

```yaml
---
doc_id: TBK-PRC-001
title: ThermaBrick design precis
project: ThermaBrick
doc_type: Precis
version: "0.1"
status: Draft
date: 2026-09-24
author: Amish Chadha
license: CERN-OHL-S-2.0
revisions:
  - version: "0.1"
    date: 2026-09-24
    author: Amish Chadha
    change: Initial draft
---
```

Quote version numbers so YAML keeps `1.0` as text instead of turning it into a number. List revisions newest last.

## 4. Writing style

- Chicago Manual of Style.
- No em dashes. Restructure the sentence instead.
- Lead each section with its conclusion, then support it.
- SI units throughout, in the form `12 kW`, `450 °C`, `3.2 m`. Imperial values may follow in parentheses.
- Number every figure and table ("Figure 2", "Table 1") and give each a caption.
- State every assumption in the calculation that depends on it.
- Put safety notes in a blockquote starting with **Safety:**.

## 5. Visual identity

| Element | Specification |
| --- | --- |
| Typeface | IBM Plex Sans for text, IBM Plex Mono for code and values (SIL Open Font License, bundled in `.kit/fonts`) |
| Ink | `#111827` |
| Secondary text | `#4B5563` |
| Rules and grid | `#D1D5DB` |
| Accent (one only) | `#0F766E` teal |
| Document page | US Letter, 20 mm margins |
| Drawing sheet | ANSI B landscape (431.8 x 279.4 mm) |
| Footer | Document ID, version, status, license and designmolecule.com on every page |

## 6. Drawing and sketch conventions

- Units are millimeters unless the title block says otherwise.
- Third-angle projection, marked with the symbol in the title block.
- Line weights: visible outlines 0.5 mm, hidden lines 0.25 mm dashed, center lines 0.18 mm chain.
- The title block contains the project, title, drawing number, revision, scale, units, projection, sheet, author, date, material or notes, and license.
- Every sheet and every render names the project and its GitHub repository (from `repo:` in `project.yaml`), at the top of the sheet and in the title block, so a printed or forwarded sheet is never anonymous.
- The drawing title names the device, not only the drawing type (for example "Handheld near-infrared resin scanner: general arrangement").
- Every view label states its scale and viewing direction (for example "Scale 1:1; side elevation looking along +Y"), and every isometric or render states where it is seen from.
- Orthographic views generated with `add_ortho` carry overall dimensions (length and depth on the top view, height on the front view) and ISO 128 centre lines on cylinders; hidden lines are dashed. Tolerances are not shown before TRL 4.
- Sheets are exported as SVG, PDF and a 300 dpi PNG.
- The revision table in the top right of the sheet lists every revision.
- Concept sketches use the same sheet and title block and carry the label "CONCEPT, NOT FOR FABRICATION".
- Geometry comes from `cad/src/*.py` (build123d). Sheets are generated by `.kit/drawing.py` and never edited by hand.

## 7. Project codes

| Code | Project | Code | Project | Code | Project |
| --- | --- | --- | --- | --- | --- |
| TBK | ThermaBrick | PCF | PicoFlow | HLT | HelioLite |
| CCB | CharCube | DRN | DustRunner | TRT | TremorTrace |
| STC | StepCue | FXH | FlexHand | CPD | ColdPod |
| SCL | SunClave | STR | SteamRoot | GGD | GrainGuard |
| SDL | SeedLine | ZBX | ZeerBox | RMS | RootMesh |
| DWD | DewDrive | SSK | StillStack | PPR | PotPress |
| WWT | WaterWatch | LMF | LumaFlow | FCL | FieldCell |
| CNP | ConePro | CVC | CulvertCrawl | EGD | EmberGuard |
| SNF | SnapFrame | CGM | CargoMule | SCM | StepClimber |
| SWC | SwapCell | PLP | PalletPilot | FTK | FlatTrike |
| WWK | WaterWalker | GRR | GrowRider | SSP | SunSpoke |
| SGN | StepGen | PBX | PowerBox | WML | WasteWise-ml |
| WSC | WasteWise Scan | RFE | ReflowEconomy | | |
| OHP | Portfolio-wide | | | | |

## 8. Build and publish

- `python .kit/render.py` checks every controlled document and renders it to `docs/pdf/<doc_id>_v<version>.pdf`.
- `python .kit/drawing.py` (called from each project's `cad/src/sheets.py`) builds drawing sheets as SVG and PDF in `cad/drawings/`.
- The GitHub Action in `.github/workflows/docs.yml` runs the checks on every push and attaches PDFs to a GitHub Release whenever a release tag is pushed.
- Public releases follow section 14: `python .kit/release_gate.py` must pass, and the release tag is `v0.<TRL>.0` (for example `v0.3.0` at TRL 3).

## 9. Technology Readiness Level (TRL)

Each project states its maturity as a Technology Readiness Level on the NASA and US DOE 1 to 9 scale. The TRL rates this specific design, not the underlying technology. A sand battery is commercial elsewhere, but a new sand battery design starts at TRL 2 until evidence shows otherwise.

| TRL | Definition | Evidence the repo must contain |
| --- | --- | --- |
| 1 | Basic principles observed | Problem statement (PRB) |
| 2 | Technology concept formulated | Draft precis (PRC) and requirements (REQ) |
| 3 | Analytical or experimental proof of concept | Calculation note (CAL), working build123d model with STEP export, drawing sheet (DWG), priced BOM with every unit cost filled in, prototype build plan (BLD) with pictures, `design_state: constructable` |
| 4 | Components validated in the lab | Test report (TST) with `environment: lab`, build log entries |
| 5 | Validated in a relevant environment | Test report (TST) with `environment: relevant` |
| 6 | System prototype demonstrated in a relevant environment | Precis at version 1.0 or later with status Released, a drawing at a lettered revision (Rev A or later), and a system-level TST with `environment: relevant` |
| 7 to 9 | Operational demonstration through proven in service | Beyond portfolio scope; claim only with a named deployment partner and evidence |

Rules:

- `project.yaml` records `trl` (current level), `trl_target` (the level the current effort aims for) and `trl_evidence` (the files that support the claim).
- `python .kit/render.py --check` fails if the evidence for the claimed TRL is missing. CI runs this check on every push.
- Documentation alone cannot go past TRL 3. TRL 4 and above require hardware and a test report.
- TRL and visibility are independent. A repo can be public at TRL 3 as a documented design ready to build.
- A change of TRL is recorded in the build log with the date and the evidence that justified it.

## 10. Portfolio phase and TRL cap

`.kit/PHASE.yaml` sets the current phase. During the **populate** phase every repo is capped at **TRL 3**: `trl` and `trl_target` may not exceed 3, and the check fails if they do. Every repo targets the cap: `trl_target` must equal 3, so a new repo is taken all the way to TRL 3 (scaffold, populate and advance, see `/to-trl3`). Work that belongs to TRL 4 or later (building or testing hardware, test articles, test plans and reports, build-log entries, purchasing lists, PCB layouts) must not be started. The prototype build plan (BLD, section 18) is TRL 3 paper work and is required. Where it already exists it is kept, flagged in the check output, and not extended. Only Amish changes `PHASE.yaml`.

Every repo carries a `CLAUDE.md` with the working rules for AI sessions: the TRL cap, decision rights (nothing is recorded as decided unless Amish decided it), one step per session, and a mandatory `docs/REVIEW.md` before stopping.

## 11. Concept media

Every repo at TRL 2 or above explains its idea visually. Media are generated from a build123d massing model with `.kit/concept.py`, never drawn by hand, so they stay in step with the design.

| File | Required | Purpose |
| --- | --- | --- |
| `media/hero.png` | TRL 2+ | Shaded isometric render with a 1.75 m person for scale; the website card image |
| `media/concept-blueprint.png` and `.pdf` | TRL 2+ | Blueprint concept sheet: orthographic and isometric views, scale, key figures, title block |
| `media/model.glb` and `media/viewer.html` | TRL 2+ | Interactive 3D viewer (glTF plus model-viewer) for the website |
| `media/cutaway.png` | When the inside matters | Section view showing internal parts |
| `media/exploded.png` | Recommended | Exploded view with numbered callouts matching the BOM |
| `media/flow.png` | When energy or material moves | System, energy or material flow diagram with losses |

Session commands in `.claude/commands/` (`/populate`, `/advance-trl3`, `/rein-in`, `/refresh-media`) carry the standard prompts, so every Claude Code session starts from the same instructions.

At TRL 2 a massing model is enough: correct overall proportions and main components. All concept media carry "CONCEPT, NOT FOR FABRICATION". The check warns when required media are missing at TRL 2 and fails at TRL 3.

## 12. Product renders

Every repo at TRL 3 shows the product as it would look, not only as a massing model.

- `cad/src/product_model.py` is the appearance model. It defines `product_parts()` (named parts with a shape and a material), `TITLE` ("Name: what it is") and `RENDER_VIEWS`. It is for renders only: every main dimension comes from `cad/src/model.py`, never typed in again.
- Where the appearance model departs from `model.py` (a chamfer, a label, a fastener drawn for realism), record the deviation in `docs/REVIEW.md` as "Proposed, awaiting Amish".
- Scale comes from context, not from a floating figure: a hand or forearm for handheld objects, and the posed mannequin (`mannequin()` in `.kit/context_parts.py`: stand, walk, push, ride, sit, reach) for anything a person uses at body scale.
- Renders are made with `.kit/export_views.py` (one scene per view) and `.kit/photoreal.py` (Blender Cycles), then captioned with `.kit/photo_caption.py`. Files are `media/render-<view>.png`; `media/render-hero.png` is required.
- Every caption names the project, the repository and the viewing direction, and carries "CONCEPT, NOT FOR FABRICATION".
- Captions never sit on the render. `.kit/photo_caption.py` adds a header band (title, concept label, repository) above the render and a footer band (view note) below it, wraps every line to the image width, and steps the font down to a floor before adding a line.
- The README opens with `media/render-hero.png`.
- Software-only and scene repositories (no single product) may use a scene render as the hero instead of a product model.

## 13. Storefront images

Two images, both made from `media/render-hero.png` by `python .kit/cards.py .`:

| File | Size | Purpose |
| --- | --- | --- |
| `media/card.png` | 800 x 800 | Square thumbnail for the organization profile page |
| `media/social-preview.png` | 1280 x 640, under 1 MB | GitHub social preview, shown when a repository link is shared |

- The social preview shows the area, name, one-line description, the first sentence of the pitch, the brand line and the repository address. Design Molecule repos read "Design Molecule · open hardware concept, TRL n"; OpenRatio repos read "OpenRatio · research and educational prototype, TRL n".
- GitHub has no API for the social preview. Upload it under the repository's Settings, Social preview, on release day.
- Regenerate both images whenever `render-hero.png` changes.

### Image quality

Every render, card and social preview must be clear and readable. `python .kit/image_qc.py` checks each one, and the release gate blocks on any failure:

| Check | Rule |
| --- | --- |
| Layout | Made by the current `photo_caption.py` or `cards.py`, which store the text layout in the PNG |
| Text inside the image | Every line at least 1.2 % of the image width from each edge; nothing runs off the side |
| No overlap | No line of text touches another line, and no caption text sits on the render |
| Text size | Render captions at least 1.05 % of the image width in pixel height (17 px at 1600 px); social preview text at least 16 px |
| Resolution | Renders at least 1200 px wide; card 800 x 800; social preview 1280 x 640 and under 1 MB |
| Sharpness | The render is not blurred or upscaled (edge sharpness at least 15 on the `image_qc.py` scale) |

Long titles and notes wrap to more lines rather than shrinking below the floor. The social preview shortens the pitch sentence with an ellipsis only if it cannot fit at the smallest size.

## 14. Public release

A repository goes public only when Amish approves it, and only after `python .kit/release_gate.py` passes. The gate checks:

1. `render.py --check` passes (document control, TRL cap, concept media).
2. Storefront: hero render, card, social preview under 1 MB, README leading with the hero, and every image passing the image quality check (section 13).
3. Issue templates in `.github/ISSUE_TEMPLATE/`: question, build report, design suggestion. The build report template restates that the design is a TRL 3 concept, not released for fabrication (OpenRatio: a research and educational prototype, not a medical device).
4. `CITATION.cff` valid, with an author ORCID.
5. License files match `project.yaml`.
6. No em dashes in the repository's own text.
7. BioMedical and OpenRatio repos use soft, non-clinical wording: "research and educational prototype, not a medical device".
8. No secrets anywhere in the history (gitleaks).
9. No links to sibling repositories that are still private.
10. REUSE files present (`REUSE.toml`, `LICENSES/`, `.github/workflows/reuse.yml`) and `reuse lint` passes (section 16).
11. `CITATION.cff` names exactly one license, because Zenodo rejects a list (section 17).

It warns, without blocking, when the README lacks a Safety heading or a "not for fabrication" statement, when `CITATION.cff` has no DOI yet, and when the README lacks the Zenodo DOI, REUSE or Software Heritage badge, so a person can confirm.

On release day, per repository:

- A signed, annotated tag `v0.<TRL>.0` on `main`.
- A GitHub release with short notes (what it is, TRL, status, licenses, how to cite) and a design pack, `<repo>-v0.<TRL>.0-design-pack.zip`, holding `cad/step`, `cad/drawings`, `docs/pdf`, `bom`, README, licenses and `CITATION.cff`.
- Description from the first sentences of `pitch` (350 characters at most), website `https://designmolecule.com` (OpenRatio: `https://openratio.ai`), topics from `project.yaml`.
- Before the first release, the repository is switched on in Zenodo (section 17), so the release is archived and gets a DOI.
- Visibility switched to public last, after the release exists.
- The social preview uploaded and the organization profile updated with the new cards.
- After the release: the concept DOI written to `CITATION.cff` and a Software Heritage save requested (section 17).

The internal working files (`CLAUDE.md`, `.kit/CLAUDE.md`, `.claude/commands/`, `docs/REVIEW.md`) stay public, and open "Proposed, awaiting Amish" items stay visible as open questions (Amish, 2026-09-27).

## 15. Authorship, citation and signing

- Amish Chadha is the author of every design, ORCID 0009-0000-8079-7141. Commits are authored as Amish Chadha <amish@designmolecule.com>.
- `CITATION.cff` lists Amish (with ORCID) first, then any credited contributors; `CONTRIBUTORS.md` and the README Credits section agree with it.
- `CITATION.cff` names one license: the hardware license (CERN-OHL-S-2.0), or the software license in a software-only repository. The full split between hardware and software licenses lives in `REUSE.toml` and the README. Once the repository is archived, `CITATION.cff` carries the concept DOI in `doi:`.
- Work done with Claude carries the trailer `Co-Authored-By: Claude <noreply@anthropic.com>` (with the model name), and the README Credits section says designs are developed with AI assistance.
- Every commit and tag pushed to GitHub is signed with Amish's SSH signing key, so GitHub shows it as Verified. Commits prepared elsewhere are re-signed on Amish's Mac before they are pushed.
- Once a repository is public, its history is never rewritten.

## 16. Licensing metadata (REUSE)

Every file states its copyright and license in a machine-readable way, following the REUSE Specification 3.3 (https://reuse.software). A repository is set up with:

```
python .kit/archive.py reuse
```

This writes three things and adds the REUSE and Software Heritage badges to the README badge line:

- `REUSE.toml`, built from the licenses in `project.yaml`. Everything is under the hardware license by default. Scripts, firmware, notebooks, web viewers, workflows and agent commands are under the software license. `cad/` and `electronics/` stay under the hardware license even where they are written as Python. The bundled IBM Plex fonts are OFL-1.1 (IBM Corp.). Copyright is "<first commit year> Amish Chadha".
- `LICENSES/`, with the full text of each license used (`reuse download`). The root `LICENSE` and `LICENSE-SOFTWARE` files stay for GitHub's license detection.
- `.github/workflows/reuse.yml`, which runs the REUSE check (fsfe/reuse-action) on every push and drives the README badge.

A new kind of file that falls outside these rules gets a new annotation in `REUSE.toml` rather than a header comment. `reuse lint` must pass before every commit that adds files, and the release gate enforces it.

## 17. Archiving and DOI (Zenodo and Software Heritage)

Every public repository is archived twice, so the design stays citable and retrievable if GitHub changes.

Zenodo (a citable DOI for each release):
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

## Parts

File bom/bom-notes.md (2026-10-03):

# BOM notes

- Row numbers match the callouts in `media/exploded.png`, Table 1 of WWT-PRC-001 and the parts in `cad/src/model.py` (`BOM_OF`). Line 20, fixings, is too small to show in the exploded view.
- All prices are indicative USD for one prototype, taken from typical retail and distributor listings in 2026. They are estimates, not quotes; every line has a supplier type. Value-engineering target: USD 300 (`budget_usd` in `project.yaml`, a hypothetical control target, not a limit). Estimated cost of the constructable design: USD 322.00 (USD 22 over the target), checked by `docs/04-calcs/sizing.py` (WWT-CAL-001, K1). Savings worth trying are in `docs/06-design-decisions.md`.
- TRL 3 changes from WWT-CAL-001: item 9 is a smaller cell (0.19 L of water); item 13 is specified as direct acting; item 14 carries a pressure-compensating flow regulator in place of the fixed restrictor (+$3); item 15 adds an outlet elbow with an open air break (+$1); item 17, a ventilated sun shield, is new (+$8).
- DDR-002 change (2026-09-25): item 9 gains a spare 12 mm port in the lid with a blanking plug (+$1), so that a site that needs the pH probe variant can take one without a new cell.
- Not in the unit cost: the existing tapstand; concrete for the pole footing; a shared calibration kit (DPD free chlorine and pH comparator, stabilized turbidity standards, about $60, estimate); cellular airtime (about $1 to $3 per month, estimate).
- Item 11 is the least certain line. An industrial amperometric probe costs about $1,900, far above the value-engineering target; see the design choices in WWT-PRC-001. The pH probe variant (probe and interface, about $60 to $100, estimate) is fitted only at sites whose pH is above 7.5 or moves more than 0.2 between visits (WWT-DDR-002). It is priced per variant site, outside the base-unit value-engineering target, which puts a variant unit at about $379 to $419 (WWT-CAL-001, K2).
- WWT-DDR-003 (2026-10-02, design for construction): lines 1, 2, 3, 8, 9, 10, 13, 14, 15, 16 and 17 respecified; lines 18 (mounting plates), 19 (lugs and internal plate) and 20 (fixings) added; +$36 in all. The solid mounting plates of the concept, once part of line 1, are now line 18.
- Status light (2026-10-02, WWT-DEC-001): line 21 added ($2.00: LED about $0.40, lens disc about $0.40, printed holder about $0.30, lead with crimps and resistor about $0.90) and line 16 gains a seventh gland (+$1.00, so $19.00); total $322.00. The shield screws are knurled thumb screws on the prototype; tamper-resistant M5 screws (about $2 a unit) are for field units after the first site visit and are not in this total.

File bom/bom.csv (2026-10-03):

item | qty | spec | supplier | unit_cost_usd | make_buy | notes
1 Mounting pole, U-bolts and V-saddles | 1 | 40 NB galvanized steel tube, 48.3 x 3.2 mm, 2.7 m (2.1 m above ground, 0.6 m in a 300 mm footing); 4 M8 U-bolts for 48 mm pipe, each with a 90 degree V-saddle, washers and nyloc nuts (antenna mast clamp kits) | Local hardware or steel supplier | 35.00 | buy | Indicative price; concrete for the footing supplied on site. The mounting plates moved to line 18 (WWT-DDR-003); price unchanged
2 Solar panel, 5 W, with pole-top tilt mount | 1 | 5 W monocrystalline, about 250 x 190 mm, 6 V class, aluminium frame with fixing holes; bought pole-top mount for 48 mm pipe: slip-on sleeve with two set screws and an adjustable tilt rail | Online retailer | 18.00 | buy | Indicative price; mount specified for construction (WWT-DDR-003)
3 Enclosure base | 1 | IP66 polycarbonate with a clear lid (decided 2026-10-02, WWT-DEC-001), about 200 x 120 x 260 mm, UV-stabilized, four moulded mounting bosses inside the back wall; eight holes drilled in the bottom face for glands, vent and antenna | Electrical distributor | 22.00 | buy | Indicative price; sold with item 4; all entries on the bottom face (WWT-DDR-003)
4 Enclosure lid and gasket | 1 | Supplied with item 3; tamper-resistant screws | Electrical distributor | 0.00 | buy | Included in item 3
5 LiFePO4 battery | 1 | 1S2P 32700 cells, 3.2 V, 6 Ah (19.2 Wh), protection board, NTC, fuse holder | Battery distributor | 20.00 | buy | Indicative price
6 Controller board | 1 | ESP32-S3 module, LiFePO4 solar charger with temperature cut-off, LMP91000-class potentiostat, 12 V boost valve driver, microSD, RTC, on a carrier board | Electronics distributor | 32.00 | buy | Indicative price; custom PCB is TRL 4 work
7 Cellular modem | 1 | LTE-M and NB-IoT with 2G fallback (SIM7000G class), SIM holder | Electronics distributor | 30.00 | buy | Indicative price; LoRaWAN module variant about $12 (WWT-DDR-001, D3)
8 Antenna | 1 | External LTE and GSM whip about 140 mm on an SMA bulkhead for a 6.5 mm hole, with pigtail; fitted in the bottom face, pointing down | Electronics distributor | 8.00 | buy | Indicative price; moved from the top to the bottom face (WWT-DDR-003)
9 Flow-through cell | 1 | Black PVC or printed ASA block, 96 x 60 x 74 mm body (14 mm back wall with two tapped M5 holes), 80 x 38 x 66 mm cavity, 0.19 L water volume, baffle on the back wall, 1.5 mm EPDM gasket, 10 mm lid on four M4 studs with knurled thumb nuts, lid glands M25 (chlorine sensor), M12 (temperature probe) and M20 with blanking plug (spare pH port), 1/4 in inlet in the floor, outlet near the top | Self | 17.00 | make | Material and fittings only; back wall, gasket, studs and lid glands added for construction (WWT-DDR-003), +$4; plugged pH port for the pH probe variant (WWT-DDR-002)
10 Turbidity head | 1 | 860 nm IR LED and two light-to-frequency detectors in three black holders with 2 mm acrylic windows: LED on the left wall, 90 degree scatter detector on the front wall, 180 degree reference on the right wall; the dark back wall is the light trap | Self with electronics distributor parts | 12.00 | make | Indicative price; after Kelley et al. (2014); split into three holders so the 90 and 180 degree paths exist (WWT-DDR-003)
11 Free chlorine sensor | 1 | Membrane-free three-electrode sensor: graphite working, Ag/AgCl reference, stainless counter, PVC holder | Self with lab supplier parts | 25.00 | make | Indicative price; choice decided in WWT-DDR-001, D1; long-term accuracy unproven
12 Temperature probe | 1 | DS18B20 in stainless sheath with 1 m cable | Online retailer | 5.00 | buy | Indicative price
13 Latching solenoid valve | 1 | 12 V latching, direct acting (no minimum pressure), normally closed, 1/4 in ports, food-safe wetted parts, two M4 mounting holes in its back face (or the maker's bracket) | Online retailer | 18.00 | buy | Indicative price; screwed to the cell plate under the cell (WWT-DDR-003)
14 Sample line, tee and strainer | 1 | 25 mm saddle tee, isolation ball valve, strainer, check valve and pressure-compensating 0.5 L/min flow regulator screwed in line on brass nipples; 1 m of 1/4 in (6.35 mm) food-grade PE tube; two push-fit elbows | Plumbing supplier | 20.00 | buy | Indicative price; regulator replaces the TRL 2 fixed restrictor (WWT-CAL-001, D); push-fit elbows added (WWT-DDR-003), +$2
15 Drain hose | 1 | Hose tail for the cell outlet, tee with an open air-break vent, 2 m of 12 mm bore PVC hose with clamp | Plumbing supplier | 6.00 | buy | Indicative price; hose tail and tee specified (WWT-DDR-003), +$1
16 Cables, glands and fuse | 1 | Seven M16 IP68 nylon glands with nuts (one spare, one for the status light lead), one M12 pressure-equalizing vent, one M16 blanking plug, sensor and panel cables, battery fuse, connectors | Electrical distributor | 19.00 | buy | Indicative price; glands rise from three to six because every cable now enters through the bottom face (WWT-DDR-003), +$4; a seventh gland takes the status light lead, +$1 (about $1 for a nylon M16 IP68 gland and nut, catalog level; WWT-DEC-001, 2026-10-02)
17 Sun shield | 1 | White powder-coated aluminium sheet 2 mm, folded hood with a 25 mm ventilated gap over the enclosure top, sides and front, open at the bottom; 15 mm flanges folded in at the back of each side, held by four M5 thumb screws; slides off forward | Local sheet metal shop | 9.00 | buy | Indicative price; added at TRL 3 so the battery can charge on hot days (WWT-CAL-001, C); flanges and fixing added (WWT-DDR-003), +$1; a 12.2 mm slot open at the bottom of the front panel takes the status light unit (WWT-DEC-001, 2026-10-02), no change in price
18 Mounting plates | 1 | Enclosure back plate 270 x 420 mm and cell back plate 140 x 385 mm, aluminium sheet 3 mm, 5052 class, drilled | Metal stockist (offcuts) | 10.00 | make | Indicative price; replaces the solid concept plates of line 1 (WWT-DDR-003)
19 Enclosure lugs and internal plate | 1 | Enclosure maker's kit of four external mounting lugs; internal plate 186 x 205 x 3 mm, ASA, 3D printed, on the box's four bosses | Electrical distributor; self | 8.00 | make | Indicative price; added so the box and the parts inside are fixed (WWT-DDR-003)
20 Fixings | 1 | Stainless: 4 x M5 x 12 screws with nyloc nuts (lugs), 4 x M4 x 12 screws (internal plate), 4 x M5 knurled thumb screws (shield), 2 x M5 x 16 screws (cell), 2 x M4 x 10 screws (valve); M3 screws and 6 mm nylon standoffs; battery strap; UV-stable cable ties | Fastener supplier | 6.00 | buy | Indicative price (WWT-DDR-003); the shield screws are knurled thumb screws on the prototype and become tamper-resistant M5 screws (security head | stainless | same thread and length) on field units | planned after the first site visit (WWT-DEC-001 | 2026-10-02); the field-unit screws add about $2 per unit and are not in this total
21 Status light, lens and lead | 1 | One 5 mm bi-colour (red and green) LED, low current (5 mA lit) with a series resistor; 16 mm clear polycarbonate lens disc 1.5 mm thick cut from sheet; printed ASA holder with a 12 mm barrel, an 18 mm collar and a bore for the LED, which drops into a 12.2 mm slot open at the bottom of the shield front panel; 1 m of two-core 3.5 mm lead with crimps, entering the enclosure through the seventh gland | Electronics distributor; self for the holder and lens | 2.00 | make | Indicative price: LED about $0.40, lens disc about $0.40, printed holder about $0.30, lead with crimps and resistor about $0.90 (catalog level); added by decision of 2026-10-02 (WWT-DEC-001), the flash is 50 ms every 10 s (WWT-CAL-001, A2)

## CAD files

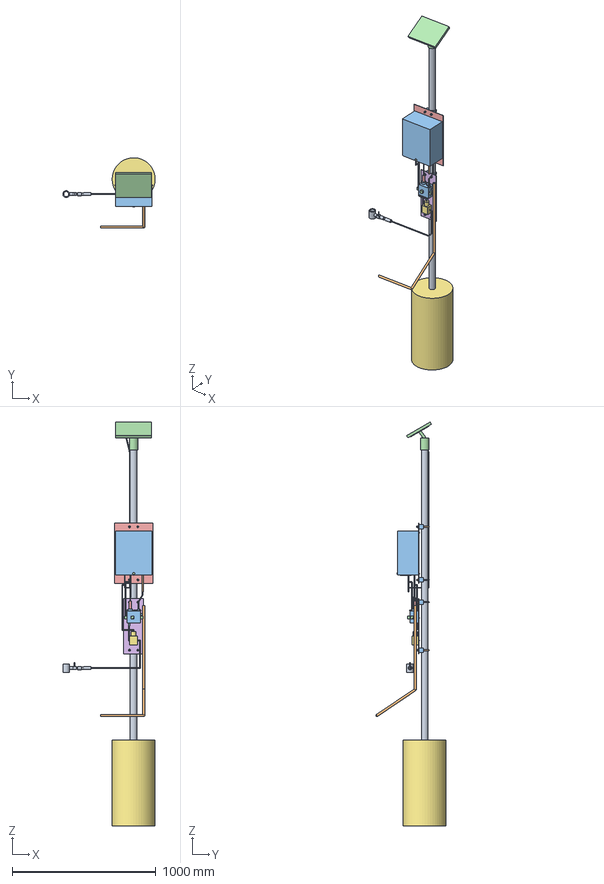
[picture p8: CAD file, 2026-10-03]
cad/step/waterwatch-assembly.step
643.8 x 491.1 x 2815.3 mm

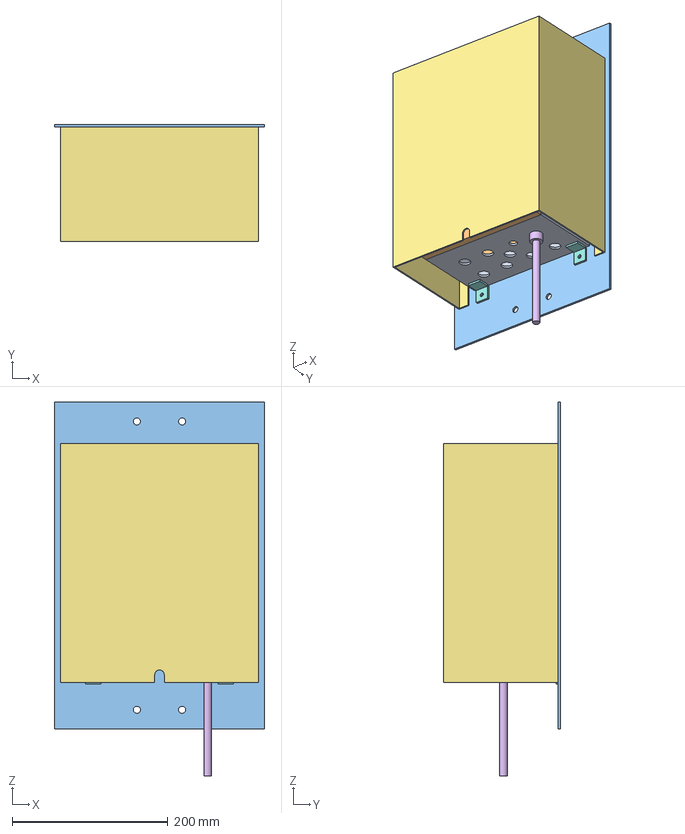
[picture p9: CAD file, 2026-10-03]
cad/step/enclosure.step
270.0 x 150.0 x 480.0 mm

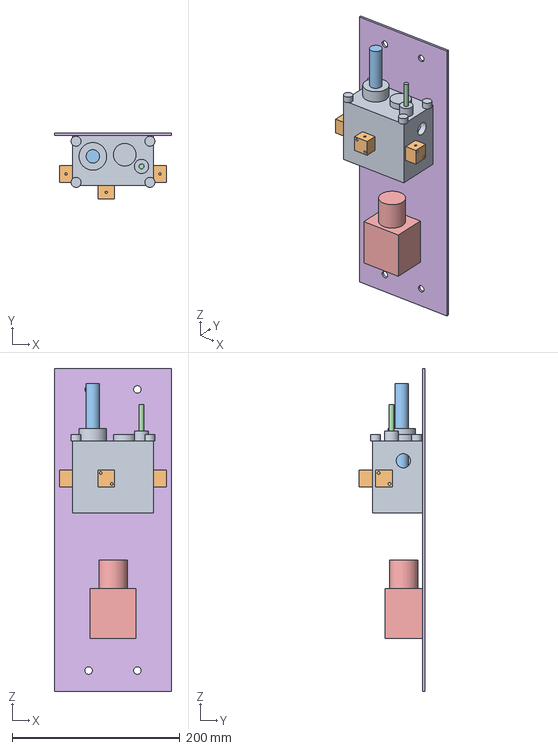
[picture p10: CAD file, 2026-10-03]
cad/step/flow-cell.step
140.0 x 79.0 x 385.0 mm

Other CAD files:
cad/stl/enclosure.stl
cad/stl/flow-cell.stl
cad/stl/waterwatch-assembly.stl

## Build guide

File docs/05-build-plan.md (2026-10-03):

---
doc_id: WWT-BLD-001
title: WaterWatch prototype build plan
project: WaterWatch
doc_type: Build plan
version: "0.2"
status: Draft
date: '2026-10-02'
author: Amish Chadha
license: CERN-OHL-S-2.0
revisions:
  - version: "0.1"
    date: '2026-10-02'
    author: Amish Chadha
    change: First build plan; design made constructable (WWT-DDR-003)
  - version: "0.2"
    date: '2026-10-02'
    author: Amish Chadha
    change: "Status light unit (line 21) and its slot, lead and gland added; tamper-resistant M5 shield screws named for field units; Step 19 added; pictures regenerated"
---

# WaterWatch prototype build plan

**Plan, not yet built.** How to build the first proof-of-concept prototype, component by component. Building and testing to it is TRL 4 work. Decisions still to be made are kept in the design decisions register ([docs/06-design-decisions.md](06-design-decisions.md)), not here.

## 1. What you are building

Figure 1. Every component, pulled apart and numbered in build order

*Figure 1. Every component pulled apart and numbered in build order: the enclosure group on the left, the flow cell group on the right, the panel above. The pole, the existing tapstand and the long runs of tube, hose and cable are left out.*

The prototype is one WaterWatch on its own galvanized pole beside a village tapstand. Two flat aluminium back plates are held to the pole by U-bolts: the upper one carries a grey plastic box holding the battery, controller and cellular modem under a white sun shield; the lower one carries a small black flow cell with its sensors and, under it, the valve that lets a sample in once an hour. A saddle tee on the tapstand riser feeds the valve through a line of screwed brass fittings and a thin plastic tube; the cell drains through an open air break to the tapstand basin. A 5 W panel sits on the pole top. Figure 1 shows the 23 components in the order you make or fit them. Eight are made in a small workshop: the two back plates, the internal plate, the flow cell body and lid, the three optics holders and the chlorine sensor; the sun shield is folded by a sheet metal shop to a sketch; the bought box is drilled. Everything else is bought and fitted. The work is cutting and drilling aluminium sheet, drilling a plastic box, milling or printing a plastic block, tapping threads in plastic, two small prints, soldering and potting three electrodes, wiring bought boards with screw terminals, and simple plumbing with thread tape and push-fit tube. The parts cost about USD 322 from the bill of materials.

> **Safety:** The prototype holds a lithium iron phosphate battery of 19.2 Wh and its charger. Keep the battery fuse out until section 6 says otherwise, never charge below 0 °C or above 45 °C, and never leave a first build charging unattended. The sample line connects to a pressurized drinking water supply: shut the supply off before fitting the saddle tee, fit the check valve the right way round, and keep the open air break so nothing can flow back. Cut aluminium edges are sharp; deburr everything. Printing ASA and milling PVC give off fumes and dust; work with ventilation. Wet concrete burns skin; wear gloves.

## 2. What changed to make it buildable

The concept showed what WaterWatch does; many of its parts could not be made, fixed or fitted as drawn. Each change below keeps what it does, and all of them are recorded in decision record WWT-DDR-003, open for Amish's review.

*Table 1. Changes from the concept.*

| Component | The concept had | The buildable design has | Why |
| --- | --- | --- | --- |
| Pole fixing | Solid 10 mm and 43 mm blocks touching the round pole along a line; clamp rings joined to nothing | Two 3 mm aluminium back plates, each on two M8 U-bolts through V-saddles (Figure 4) | The standard bought way to hold a flat plate to a round pole |
| Enclosure | No fixing to its plate; parts inside floating | The maker's four lugs (Figure 6); a printed internal plate on the box's moulded bosses (Figure 9) | The box back stays sealed; everything inside is screwed down |
| Entries | Antenna and panel lead through the sun shield top; three glands for five cables | Seven glands (one a plugged spare, one for the status light lead), the vent and the antenna all in the bottom face, in three rows (Figure 7) | Nothing passes through the shield, and no entry faces the rain |
| Sun shield | No fixing; trapped by the antenna | Flanges folded in at the back, four thumb screws; slides off forward; a slot open at the bottom of its front takes the status light unit (Figure 13) | Comes off by hand at the pole; same 25 mm air gap |
| Status light | A green light on the product drawings, with nothing behind it | One LED behind a lens, in a unit that sits in the slot in the shield front, with its own lead and gland (Figure 12a) | Shows the state at the tapstand; the shield still slides off |
| Turbidity optics | One block on one wall, which cannot see at both 90° and 180°; the beam would have hit the baffle | Three holders on three walls; baffle moved to the back wall, same size (Figure 21) | Gives the 90° scatter and 180° reference paths the concept cites |
| Flow cell lid | Three ports in a line, two of them overlapping; no seal or fixing | Glands laid out clear of each other, a gasket, four studs and thumb nuts (Figures 24 and 25) | Every gland fits and every probe clears the beam and the baffle |
| Flow cell body | Held on by nothing; 8 mm back wall | 14 mm back wall with two screws from behind the plate (Figure 17) | No hole through a wet wall |
| Valve | Hanging on the plastic tube 230 mm from the riser | Screwed to the cell plate under the cell (Figure 26) | A tube cannot carry a valve; shorter stale run (696 mm instead of 738 mm) |
| Panel | A rod pushed into the pole top | A bought pole-top tilt mount (Figure 28) | A stock part for a 48 mm pole |
| Fittings at the riser | Fittings joined by plastic tube; check valve not drawn | One screwed brass line with the check valve shown (Figure 29) | Rigid, and the check valve is where it must go |

## 3. Making the components

Make and check each component before the assembly step that needs it. Sizes are in millimetres. "Left" and "right" are as seen standing in front of WaterWatch, looking at the enclosure lid. Workshop tolerance is 0.5 mm unless a step says otherwise; drawings do not carry tolerances before TRL 4.

### 3.1 Enclosure back plate

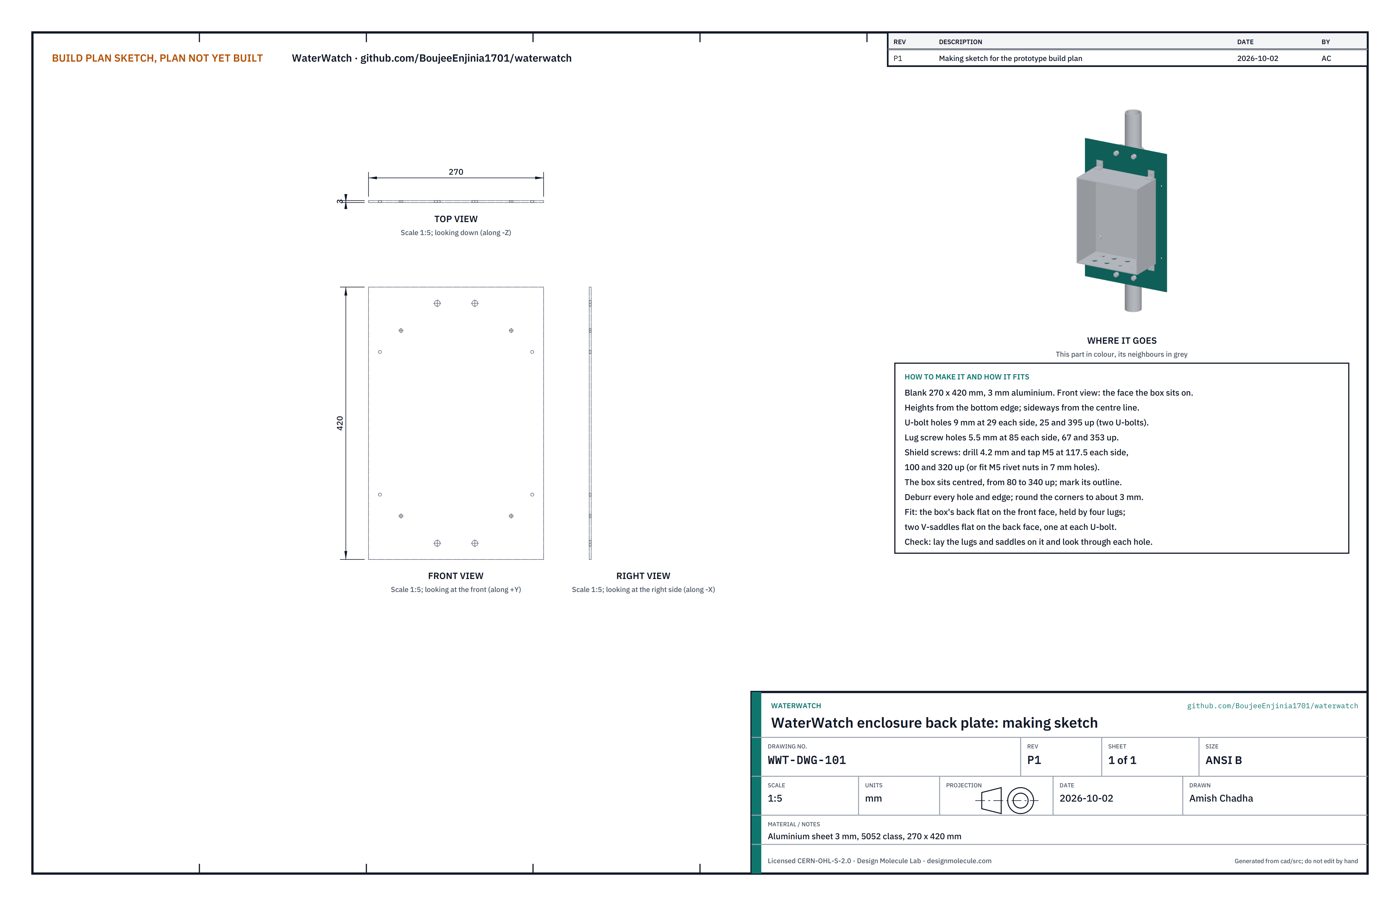
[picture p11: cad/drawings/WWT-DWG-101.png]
Figure 2. Making sketch of the enclosure back plate


*Figure 2. Enclosure back plate making sketch (WWT-DWG-101).*

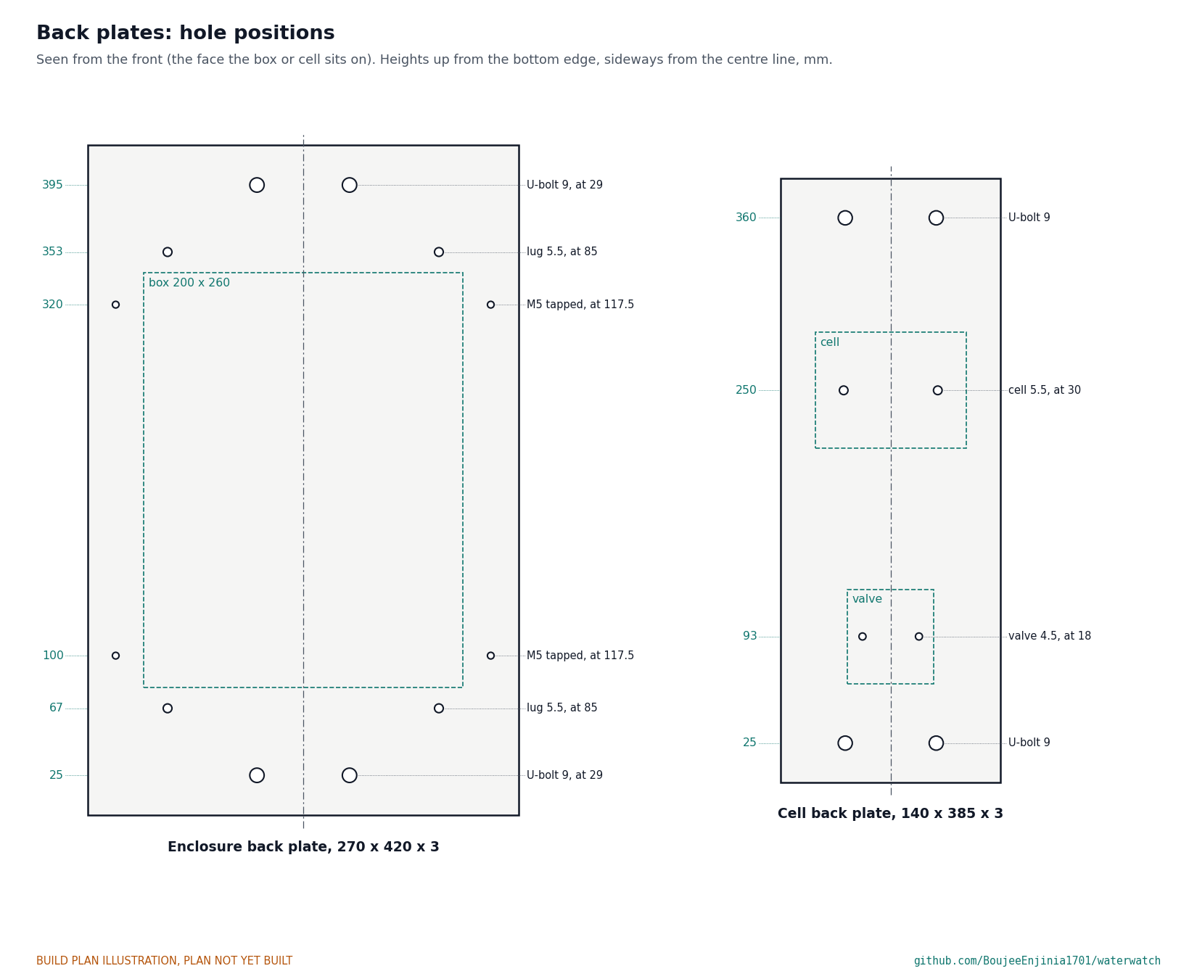
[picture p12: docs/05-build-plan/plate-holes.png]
Figure 3. Hole positions on both back plates


*Figure 3. Every hole on both back plates, up from the bottom edge and sideways from the centre line.*

**What it is and what it is made from.** The flat plate the enclosure hangs on, held to the pole by two U-bolts. Aluminium sheet 3 mm thick, 5052 class, cut to 270 x 420 mm.

**How to make it.**

1. Cut the blank square to 270 x 420 mm. File the edges and round the corners to about 3 mm.
2. Scribe a centre line down the long side. Choose one face as the front (the box side) and mark it.
3. Mark every hole from Figure 3: heights up from the bottom edge, sideways from the centre line. Every hole is one of a pair, the same distance each side.
4. U-bolt holes: four 9 mm holes, 29 each side of centre, 25 and 395 up.
5. Lug holes: four 5.5 mm holes, 85 each side of centre, 67 and 353 up.
6. Shield screw holes: four holes 117.5 each side of centre, 100 and 320 up. Drill 4.2 mm and tap M5 (or drill 7 mm and fit M5 rivet nuts).
7. Mark the box outline on the front: 200 wide, centred, from 80 to 340 up.
8. Deburr every hole on both faces.

**How it fits the parts next to it.**

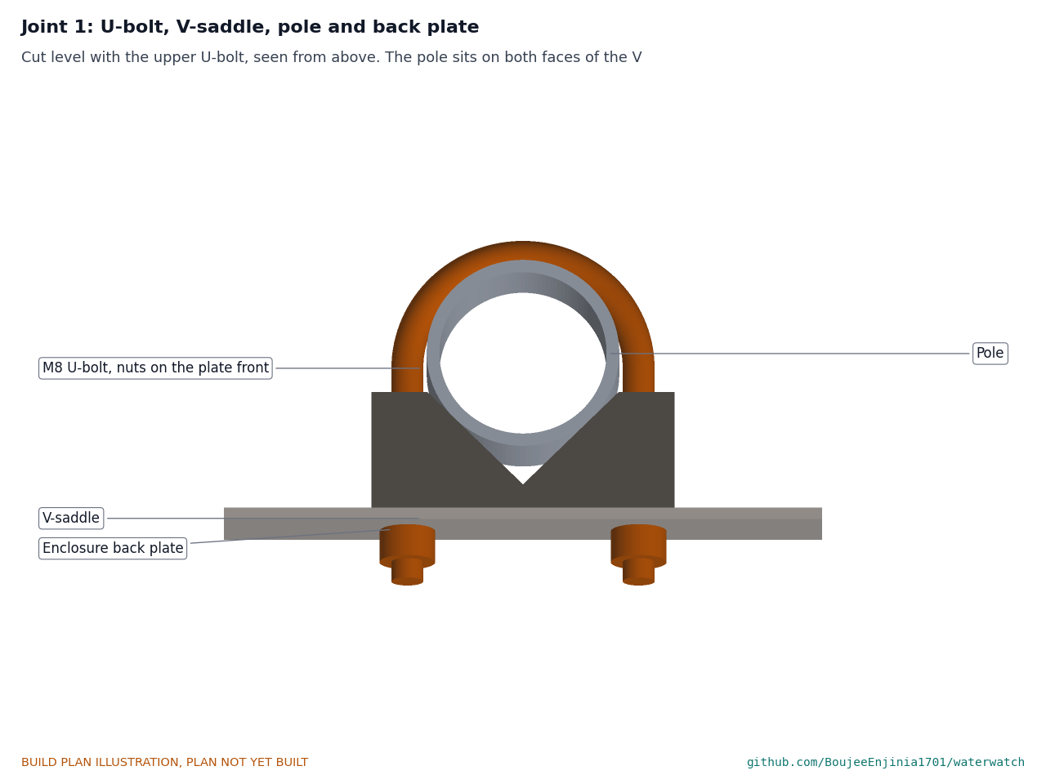
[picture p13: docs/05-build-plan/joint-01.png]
Figure 4. Joint 1: U-bolt, V-saddle, pole and back plate


*Figure 4. The V-saddle lies flat on the back of the plate; the pole sits on both faces of its V; the U-bolt passes round the back of the pole, through the saddle and the plate, with nyloc nuts on the front.*

The box's back sits flat on the front face between 80 and 340 up, held by four lugs (Figure 6). A V-saddle sits flat on the back face at each U-bolt; the pole centre ends up 40 behind the back face. The sun shield's flanges lie flat on the front face either side of the box (Figure 13).

**Check before moving on.** Lay the lugs and the saddles on the plate and look through each hole: the holes must line up without forcing a screw or a U-bolt leg.

### 3.2 Enclosure body, drilled, with its glands, vent, antenna and lugs

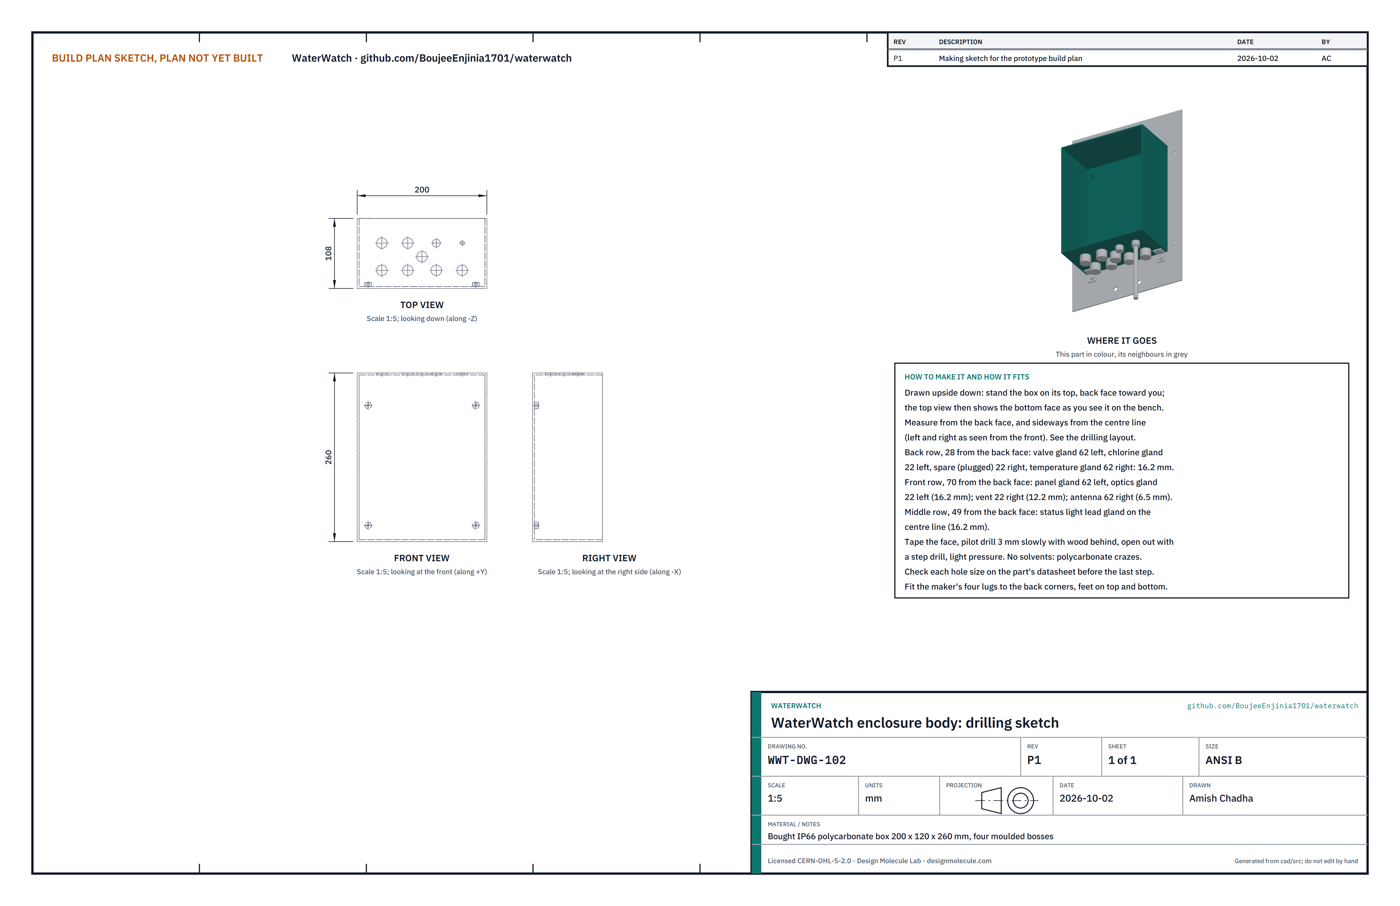
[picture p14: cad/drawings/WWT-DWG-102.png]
Figure 5. Drilling sketch of the enclosure body


*Figure 5. Enclosure drilling sketch (WWT-DWG-102), drawn upside down so the top view shows the bottom face.*

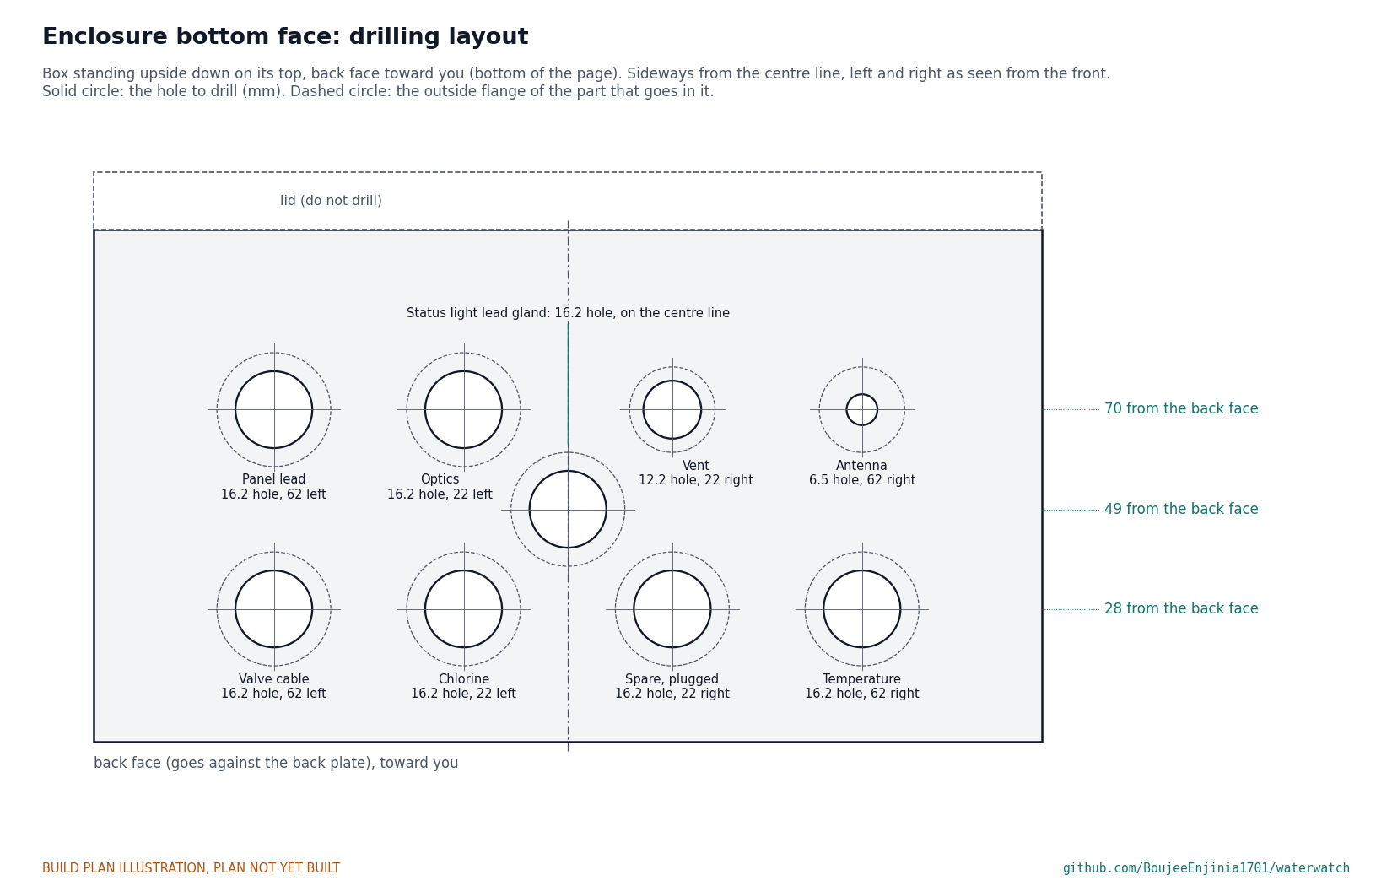
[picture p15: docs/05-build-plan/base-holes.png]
Figure 5a. Bottom face drilling layout


*Figure 5a. Drilling layout, with the box standing upside down on its top and its back face toward you.*

**What it is and what it is made from.** A bought grey polycarbonate box, 200 wide, 120 deep and 260 tall, rated IP66, with a gasketed lid on the front, four moulded bosses inside the back wall and the maker's kit of four external mounting lugs. Nine holes are drilled in its bottom face.

**How to make it.**

1. Stand the box upside down on its top on a soft cloth, back face toward you. Cover the bottom face with masking tape.
2. Mark the holes from Figure 5a. Back row, 28 from the back face: valve cable gland 62 left of centre, chlorine gland 22 left, the spare (plugged) 22 right, temperature gland 62 right. Middle row, 49 from the back face: the status light lead gland on the centre line. Front row, 70 from the back face: panel lead gland 62 left, optics gland 22 left, vent 22 right, antenna 62 right. Left and right are as seen from the front of the box.
3. Put a block of wood inside under the face. Pilot drill every hole 3 mm at low speed; do not centre punch hard, since polycarbonate cracks.
4. Open each hole with a step drill, light pressure, low speed: 16.2 for the seven glands (one is the spare), 12.2 for the vent, 6.5 for the antenna. Before the last step, check the size against the part's datasheet.
5. Deburr inside and out, peel the tape, and clean with water and mild soap only; solvents craze polycarbonate.
6. Fit the four lugs to the box's back corners as the lug kit's maker describes, feet on the top and bottom faces, tabs flush with the back face.

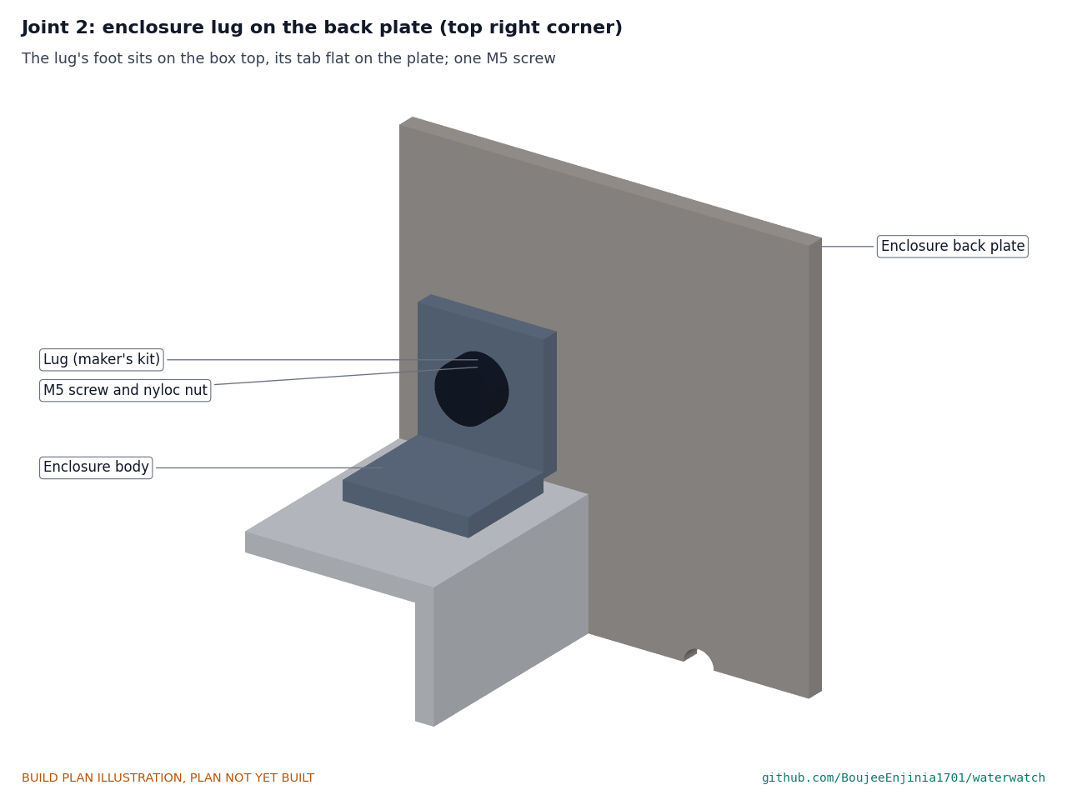
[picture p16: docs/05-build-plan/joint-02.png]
Figure 6. Joint 2: enclosure lug on the back plate


*Figure 6. Each lug's foot sits on the box; its tab lies flat on the plate beside the box, held by one M5 screw from behind the plate with a nyloc nut in front.*

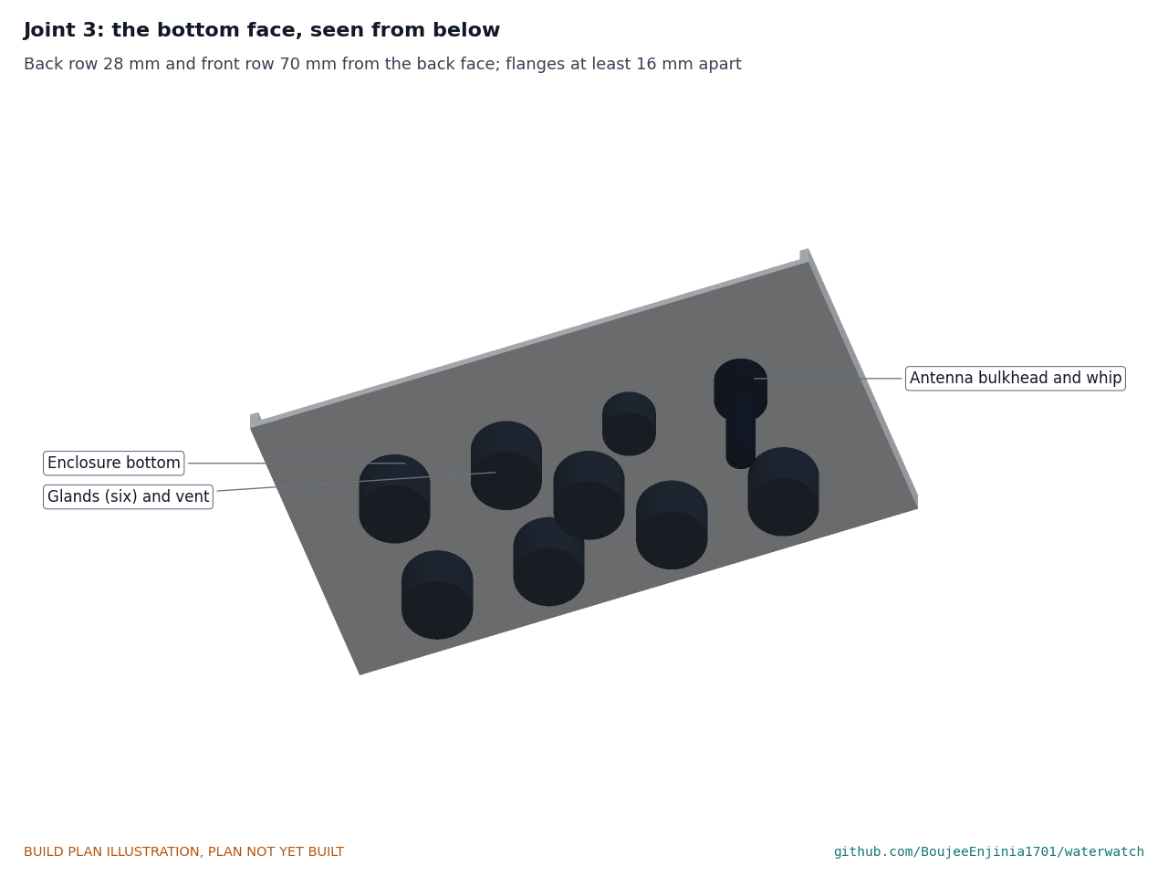
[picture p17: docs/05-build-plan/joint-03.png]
Figure 7. Joint 3: the bottom face, seen from below


*Figure 7. Seven glands, the vent and the antenna bulkhead in three rows; the whip points down.*

**How it fits the parts next to it.** Each gland, the vent and the antenna bulkhead go in from below with the sealing washer outside and the nut inside (step 1). The outside flanges are at least 16 apart, room for a spanner. The box back sits flat on the back plate, held by the four lugs (step 5).

**Check before moving on.** Each part seats flat on its washer; no crack runs out from any hole under a bright lamp; with the lugs fitted, the box sits flat on the plate and all four lug holes line up.

### 3.3 Internal plate and the electronics on it

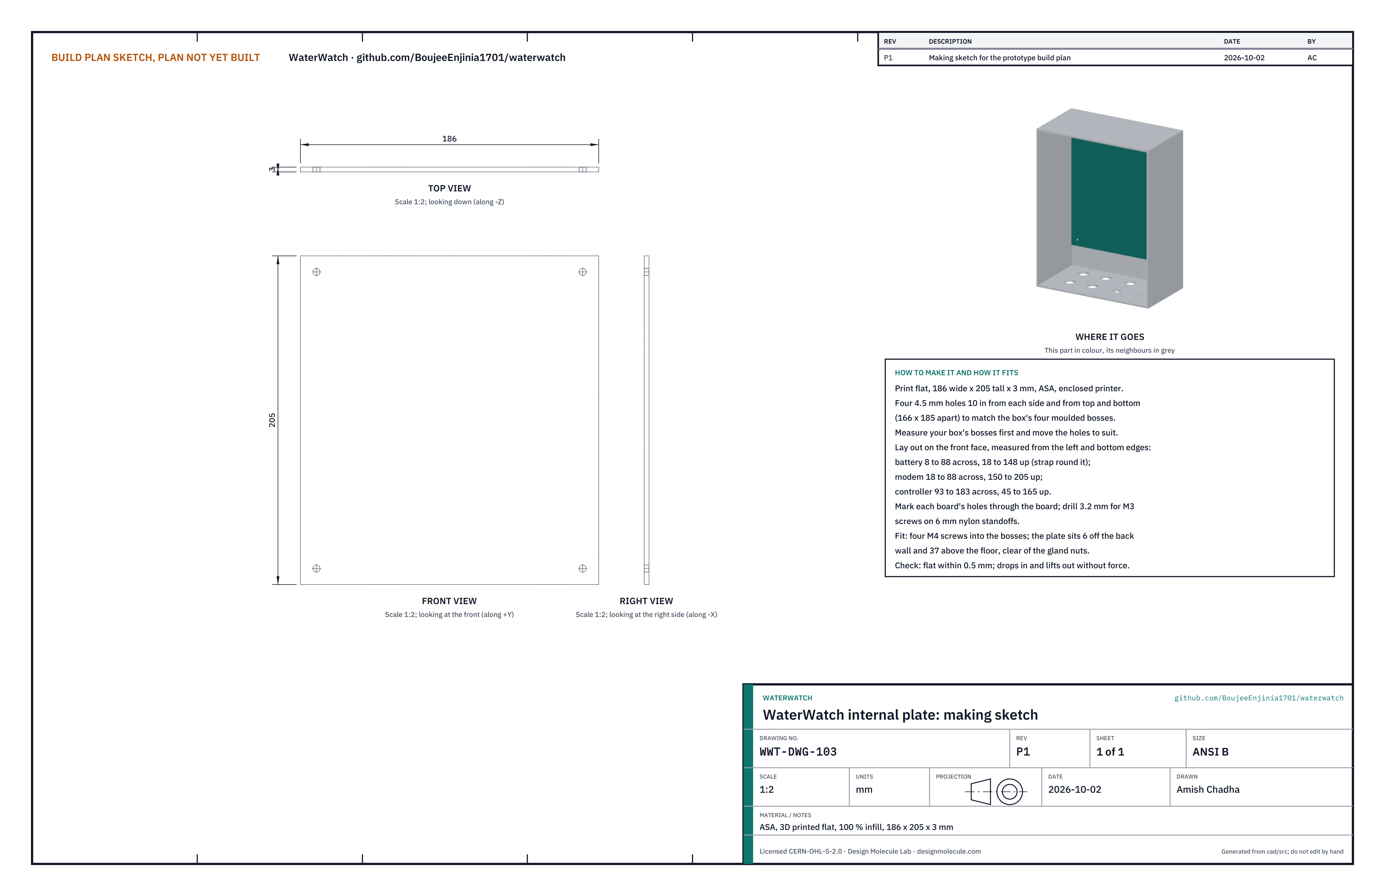
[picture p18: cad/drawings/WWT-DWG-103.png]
Figure 8. Making sketch of the internal plate


*Figure 8. Internal plate making sketch (WWT-DWG-103).*

**What it is and what it is made from.** A printed plate that carries the battery, the controller carrier board and the cellular modem, and lifts out of the box as one unit. ASA plastic, 186 x 205 x 3 mm, printed flat at 100 % infill in an enclosed printer.

**How to make it.**

1. Measure the four bosses inside your box. The model assumes they are 166 apart across and 185 apart up and down; move the plate's holes to match your box.
2. Print the plate with four 4.5 mm holes at the bosses, 10 in from each edge. Let it cool on the bed so it does not warp.
3. Lay out the parts on the front face, measured from the plate's left and bottom edges: the battery from 8 to 88 across and 18 to 148 up; the modem from 18 to 88 across and 150 to 205 up; the controller from 93 to 183 across and 45 to 165 up.
4. Mark each board's mounting holes through the board, drill 3.2 mm, and fit the boards on M3 screws with 6 mm nylon standoffs. Hold the battery with a strap round it and the plate, with its fuse out.
5. Wire the boards as Figure 10 shows.

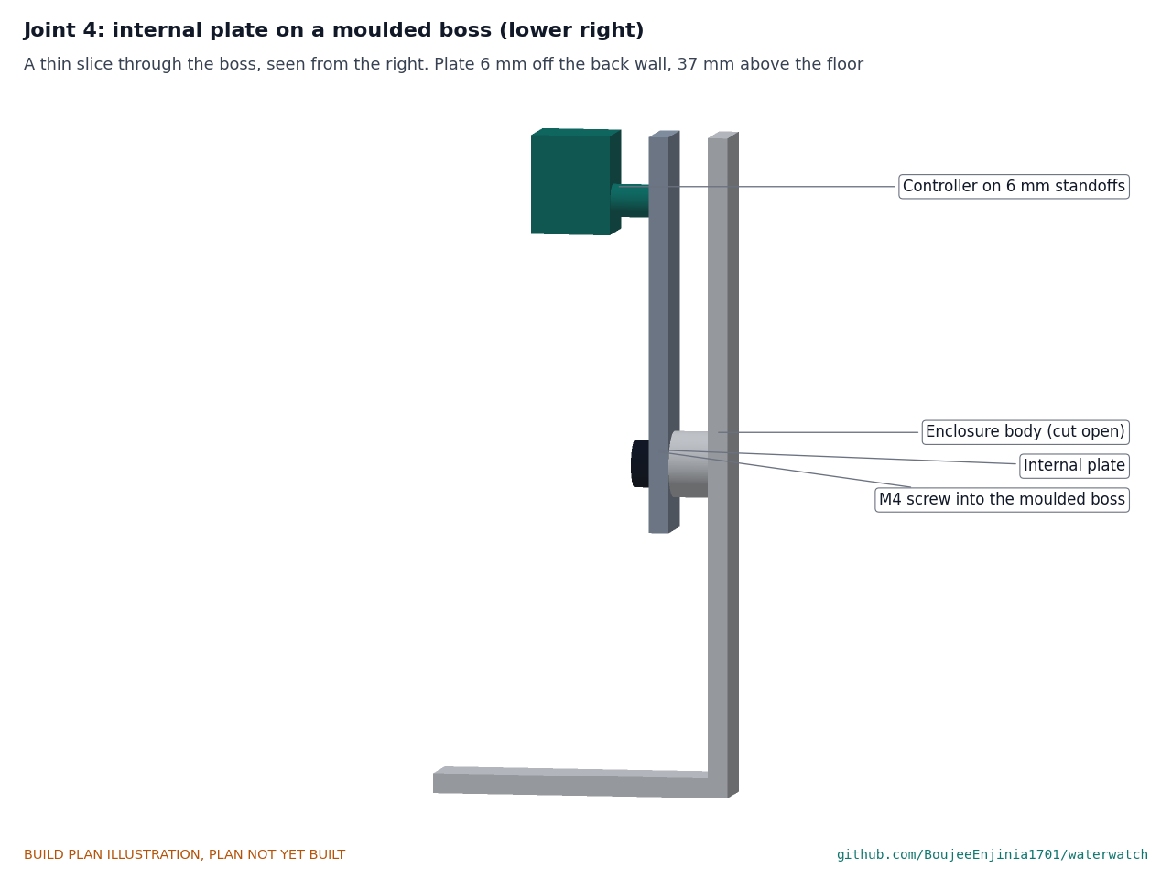
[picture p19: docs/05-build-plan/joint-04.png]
Figure 9. Joint 4: internal plate on a moulded boss


*Figure 9. The plate sits on the four moulded bosses, 6 off the back wall and 37 above the floor, clear of the gland nuts, held by four M4 screws.*

**How it fits the parts next to it.** The plate's back face sits on the ends of the four bosses; four M4 screws go into the bosses. The 37 mm below the plate leaves room for each cable to bend up from its gland.

#### 3.3.1 Wiring

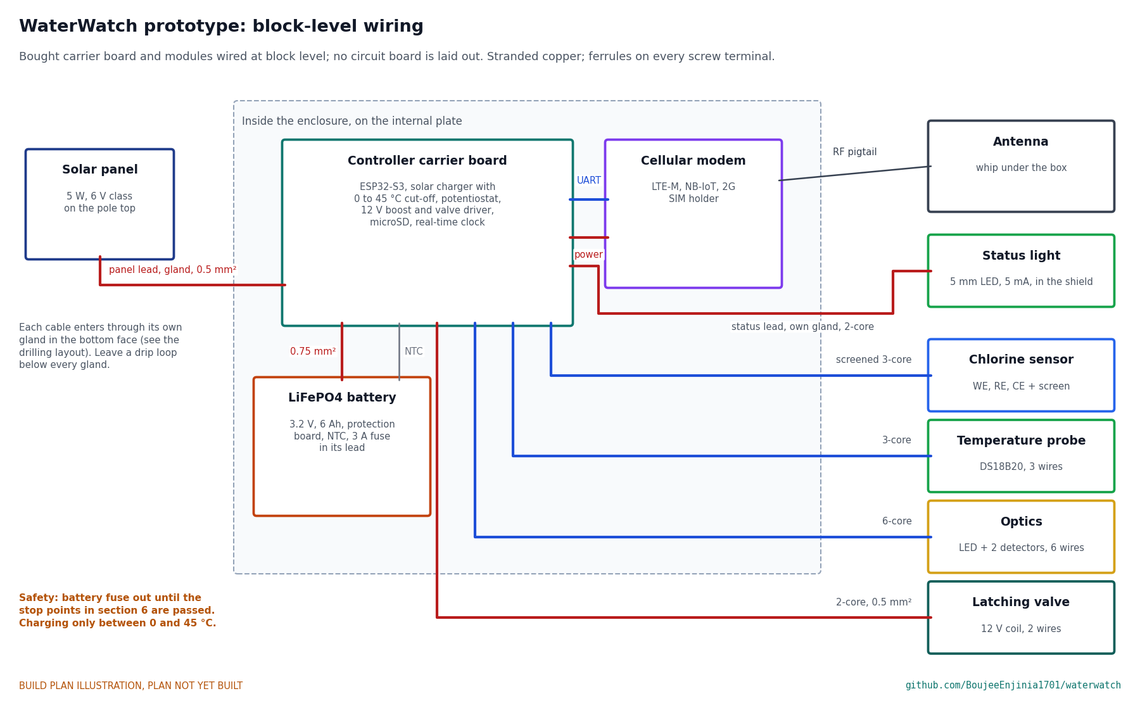
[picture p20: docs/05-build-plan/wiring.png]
Figure 10. Block-level wiring


*Figure 10. Block-level wiring. No circuit board is laid out at this stage; the bought carrier board stands in for a custom board, which is TRL 4 work.*

Wire it like this, with stranded copper and a ferrule on every screw terminal:

1. Battery to the carrier board's battery terminals, through the 3 A fuse in the battery lead: 0.75 mm² (18 AWG).
2. The battery's temperature sensor to the charger's temperature input, twisted, with the sensor taped to the cells.
3. Panel lead, through its gland, to the carrier board's solar input: 0.5 mm² (20 AWG).
4. Carrier board to the modem: power and serial lines, as the modem maker's carrier describes; antenna pigtail from the modem to the bulkhead, away from the power wires.
5. Chlorine sensor: screened 3-core cable to the potentiostat's working, reference and counter terminals, screen to ground at the board end only.
6. Temperature probe: 3-core to the one-wire input.
7. Optics: 6-core to the LED driver and the two frequency inputs.
8. Valve: 2-core 0.5 mm² to the 12 V valve driver.
9. Status light: 2-core lead from a spare output of the carrier board through a series resistor that sets about 5 mA, to the LED in the shield (Figure 10); the lead leaves through its own gland and the other end stays free until step 19.

Check that the charger's temperature window really is 0 to 45 °C in its datasheet before buying: some chargers of this class fix a different window.

**Check before moving on.** Every wire continues end to end; with the battery fuse out, the battery terminals and every supply read open to ground; every wire is labelled; the plate is flat within 0.5 mm and drops in and lifts out without force.

### 3.4 Sun shield

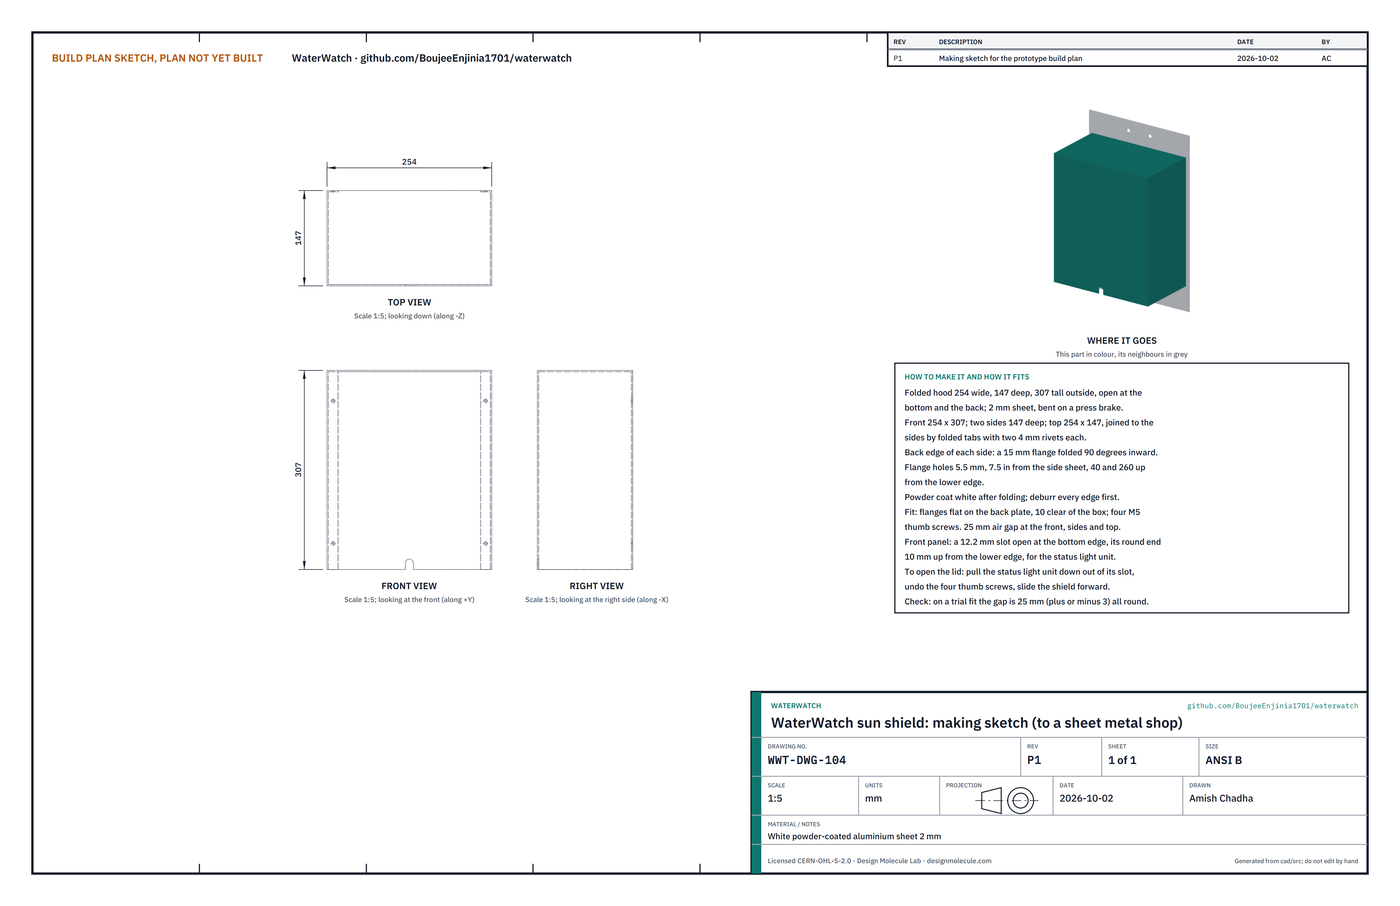
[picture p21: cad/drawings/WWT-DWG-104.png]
Figure 11. Making sketch of the sun shield


*Figure 11. Sun shield making sketch (WWT-DWG-104), for a sheet metal shop.*

**What it is and what it is made from.** A white folded hood that shades the box on its front, sides and top with a 25 mm air gap, so the battery can charge on hot days. White powder-coated aluminium sheet 2 mm.

**How to make it.** Order it from a sheet metal shop with the sketch, or fold it on a press brake:

1. Cut a front 254 x 307 mm with a side 147 deep on each long edge and a top 147 deep on the top edge; add a 10 mm tab on each end of the top and a 15 mm flange on the back edge of each side. Cut a slot 12.2 mm wide in the middle of the front, open at the lower edge, with a round end 10 mm up from that edge.
2. Drill a 3 mm relief hole wherever two fold lines cross, so the sheet does not tear.
3. Fold the sides back 90°, then the top, then the tabs down over the sides; rivet each tab with two 4 mm rivets.
4. Fold each flange 90° inward. Drill two 5.5 mm holes in each flange, 7.5 in from the side sheet, 40 and 260 up from the lower edge.
5. Deburr every edge, then powder coat white.

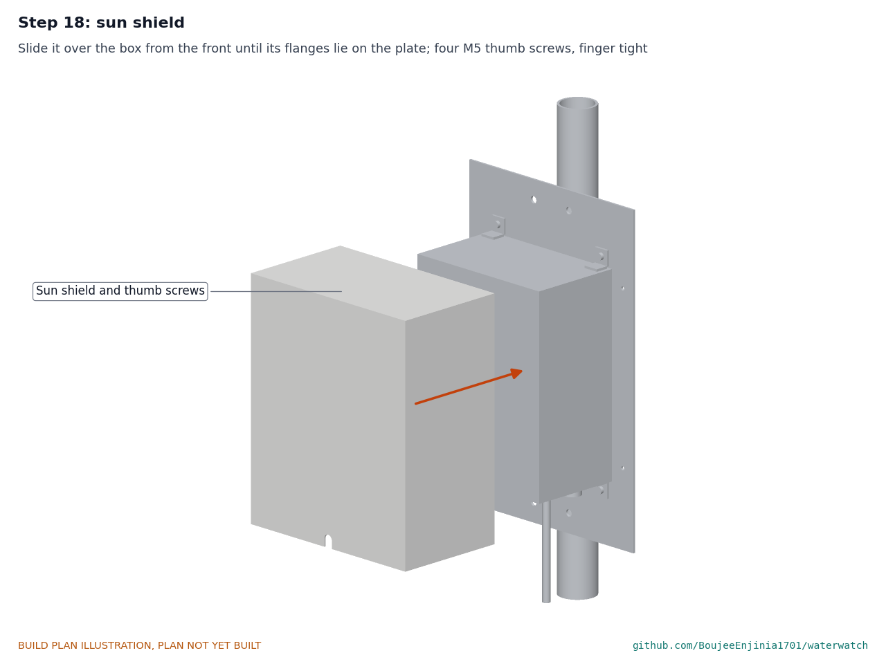
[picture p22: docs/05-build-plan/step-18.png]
Figure 12. Step 18 picture: the shield going on


*Figure 12. The shield slides over the box from the front.*

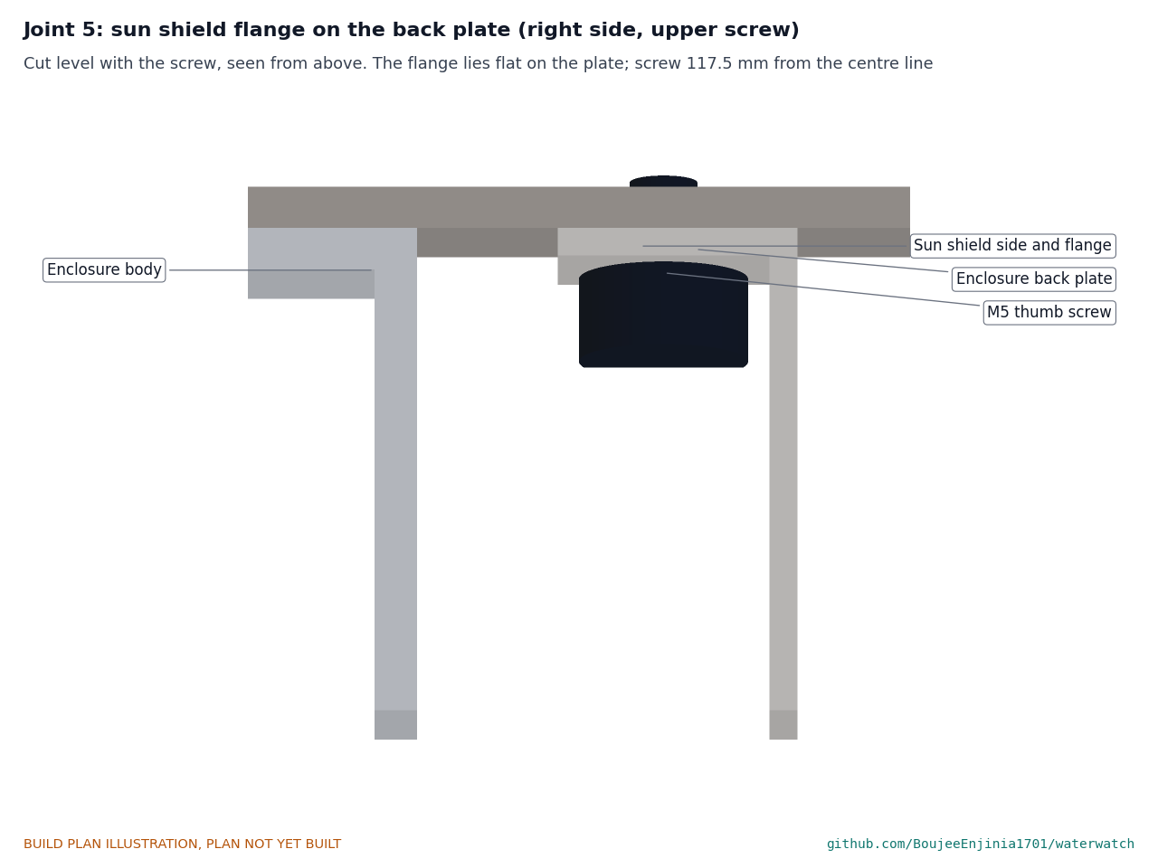
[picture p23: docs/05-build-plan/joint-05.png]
Figure 13. Joint 5: shield flange on the back plate


*Figure 13. The flange lies flat on the back plate, 10 beside the box; an M5 thumb screw holds it.*

**How it fits the parts next to it.** The flanges lie flat on the front of the back plate either side of the box, and four M5 thumb screws go through them into the tapped holes in the plate. The shield stands 25 off the box's front, sides and top, its lower edge 20 below the box, open at the bottom. The slot in the front, open at the bottom, takes the status light unit below. To open the box, pull the status light unit down out of its slot, undo the four thumb screws and slide the shield forward. On field units the four thumb screws are replaced by tamper-resistant M5 screws (stainless, security head, same thread and length) after the first site visit; the prototype keeps the thumb screws.

**Check before moving on.** On a trial fit over the box, the gap is 25, give or take 3, all round, and the slot is clear of burrs.

**The status light unit (line 21).** A small unit that shows the state of the sensor at the tapstand. Make it as follows:

1. Print the holder in ASA: a barrel 12 mm across and 14 mm long, an 18 mm collar 2 mm thick at one end of the barrel, and a 5.2 mm hole bored 9 mm deep into the other end.
2. Cut a 16 mm disc from 1.5 mm clear polycarbonate sheet and glue it to the bored end of the barrel, with a thin film of clear glue.
3. Push the 5 mm LED into the bore until its lens touches the disc. Solder a resistor to one leg, then solder the 1 m two-core lead, and cover both joints with heat-shrink.
4. Check by eye: the collar and the disc are the same distance apart as the front panel is thick, so the unit holds in the slot.

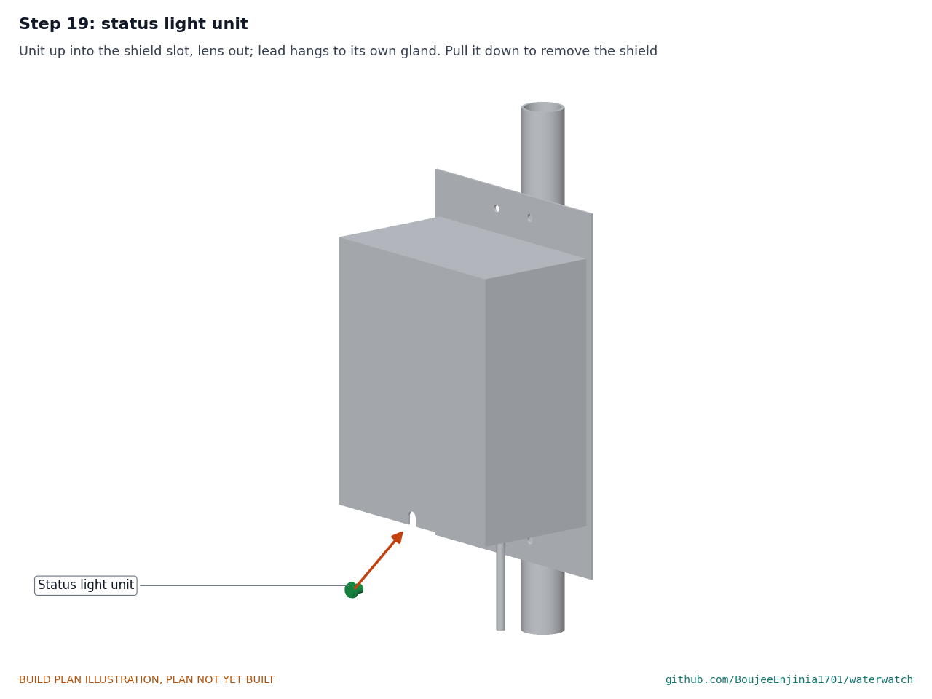
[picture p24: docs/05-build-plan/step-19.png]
Figure 12a. Step 19 picture: the status light unit going into the slot


*Figure 12a. The unit goes up into the slot from below, lens facing out; its lead hangs to the gland under the box.*

The barrel sits in the slot with the disc in front of the panel and the collar behind it; the lead runs from the barrel back under the box and up into its own gland. The unit stays 10 or more from the box lid and the lead stays 20 or more from the antenna whip.

### 3.5 Cell back plate

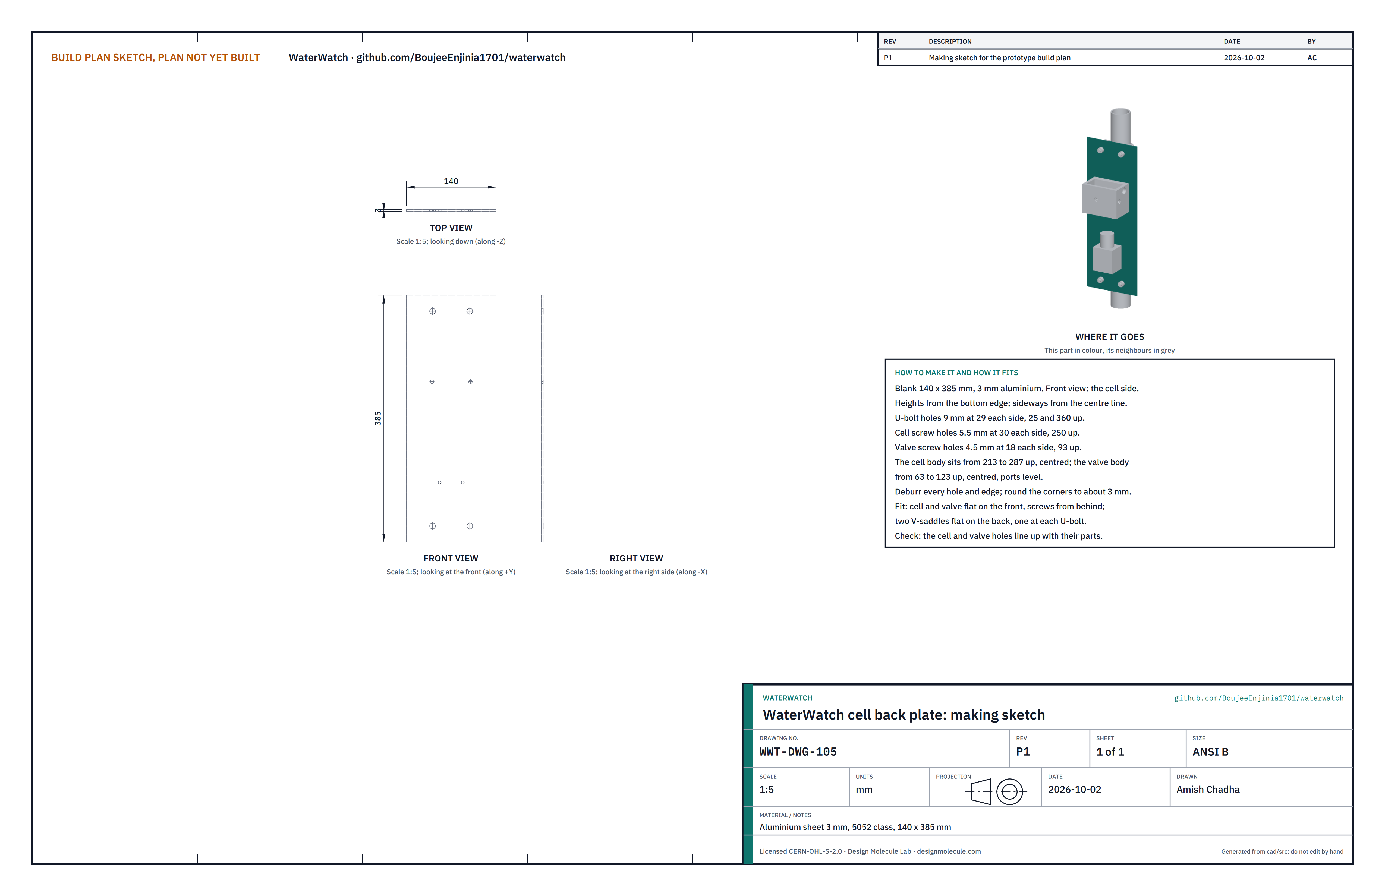
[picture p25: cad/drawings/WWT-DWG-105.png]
Figure 14. Making sketch of the cell back plate


*Figure 14. Cell back plate making sketch (WWT-DWG-105); hole positions also in Figure 3.*

**What it is and what it is made from.** The flat plate the flow cell and the valve hang on, held to the pole by two U-bolts below the enclosure. Aluminium sheet 3 mm, 5052 class, cut to 140 x 385 mm.

**How to make it.**

1. Cut the blank square to 140 x 385 mm, file the edges and round the corners to about 3 mm. Scribe a centre line and mark the front face.
2. U-bolt holes: four 9 mm holes, 29 each side of centre, 25 and 360 up.
3. Cell screw holes: two 5.5 mm holes, 30 each side of centre, 250 up.
4. Valve screw holes: two 4.5 mm holes, 18 each side of centre, 93 up.
5. Mark the outlines: the cell from 213 to 287 up, 96 wide; the valve from 63 to 123 up, 55 wide; both centred.
6. Deburr every hole on both faces.

**How it fits the parts next to it.** The flow cell's back and the valve's back sit flat on the front face, held by screws from behind (Figures 17 and 26). Two V-saddles sit on the back face, one at each U-bolt, as on the enclosure plate (Figure 4).

**Check before moving on.** Hold the cell body and the valve against the plate: their tapped holes line up with the plate holes.

### 3.6 Flow cell body

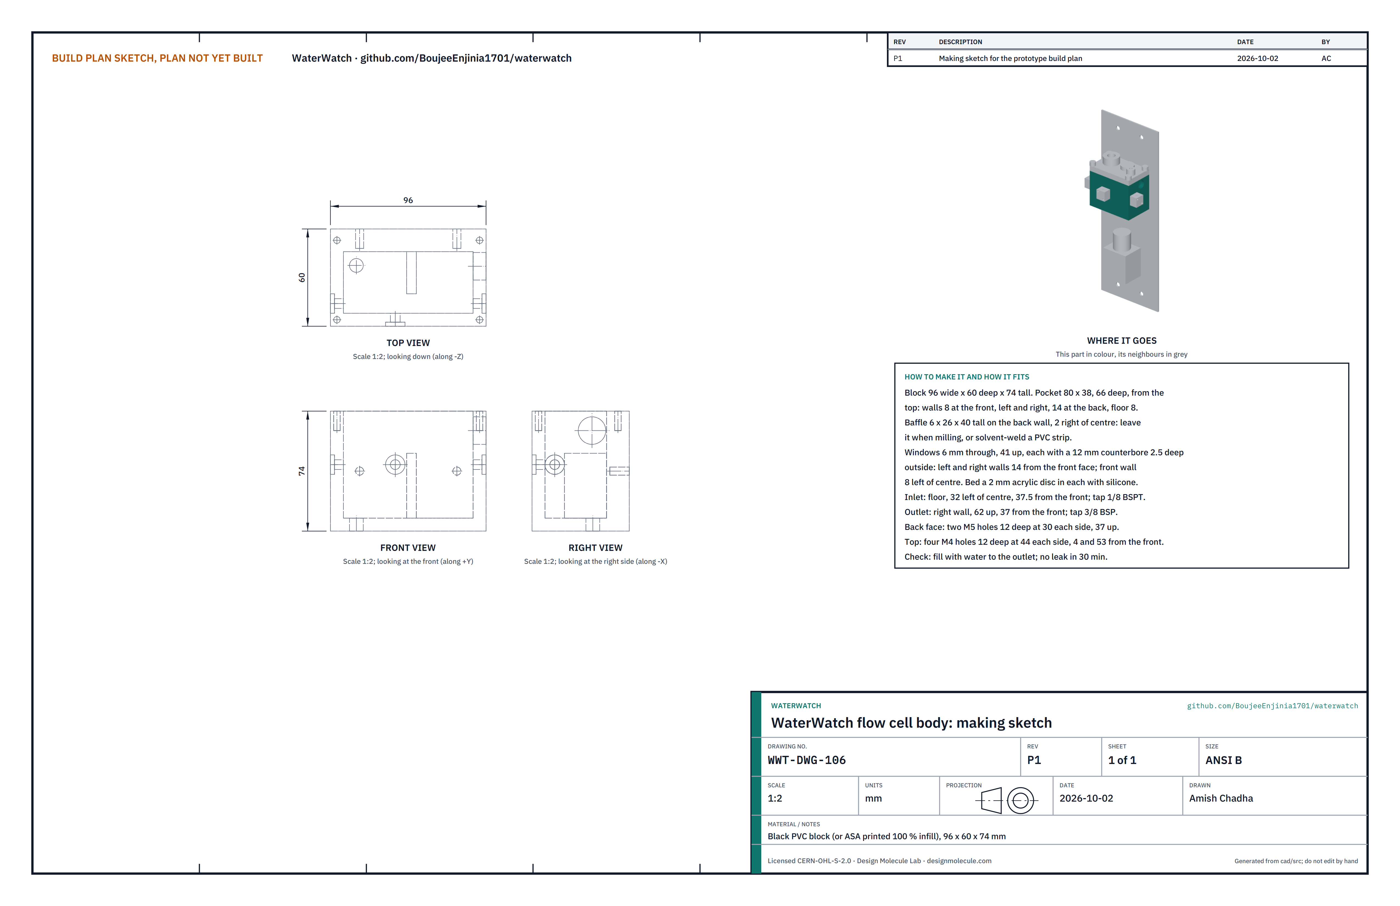
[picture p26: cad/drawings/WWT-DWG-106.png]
Figure 15. Making sketch of the flow cell body


*Figure 15. Flow cell body making sketch (WWT-DWG-106).*

**What it is and what it is made from.** The dark block the sample flows through: a pocket of 0.19 L with an inlet in the floor, an outlet near the top of the right wall, a baffle on the back wall and three windows for the light. Black PVC block, 96 x 60 x 74 mm, milled; or black ASA printed at 100 % infill.

**How to make it.**

1. Square the block to 96 wide, 60 deep and 74 tall. Mark the front face.
2. Mill a pocket 80 wide and 38 deep (front to back), 66 down from the top, leaving walls of 8 at the front, left and right, 14 at the back, and a floor of 8. Leave a baffle standing on the back wall, 6 thick, 26 deep and 40 tall from the floor, its centre 2 right of the pocket centre; or solvent-weld a PVC strip of that size in place.
3. Windows: drill three 6 mm holes through the walls, centred 41 up from the underside. In the left and right walls they are 14 from the front face; in the front wall it is 8 left of centre. Counterbore each 12 mm, 2.5 deep, from outside, and bed a 2 mm clear acrylic disc in each with neutral-cure silicone.
4. Beside each window, drill and tap two M3 holes 6 deep at the holder's corners (Figure 19).
5. Inlet: in the floor, 32 left of centre and 37.5 from the front face; drill 8.8 and tap 1/8 BSPT.
6. Outlet: in the right wall, 62 up from the underside and 37 from the front face; drill 14.75 and tap 3/8 BSP.
7. Back face: two M5 holes 12 deep, 30 each side of centre, 37 up.
8. Top face: four M4 holes 12 deep, 44 each side of centre, 4 and 53 from the front face, for the lid studs.
9. Deburr; wash out every chip.

**How it fits the parts next to it.**

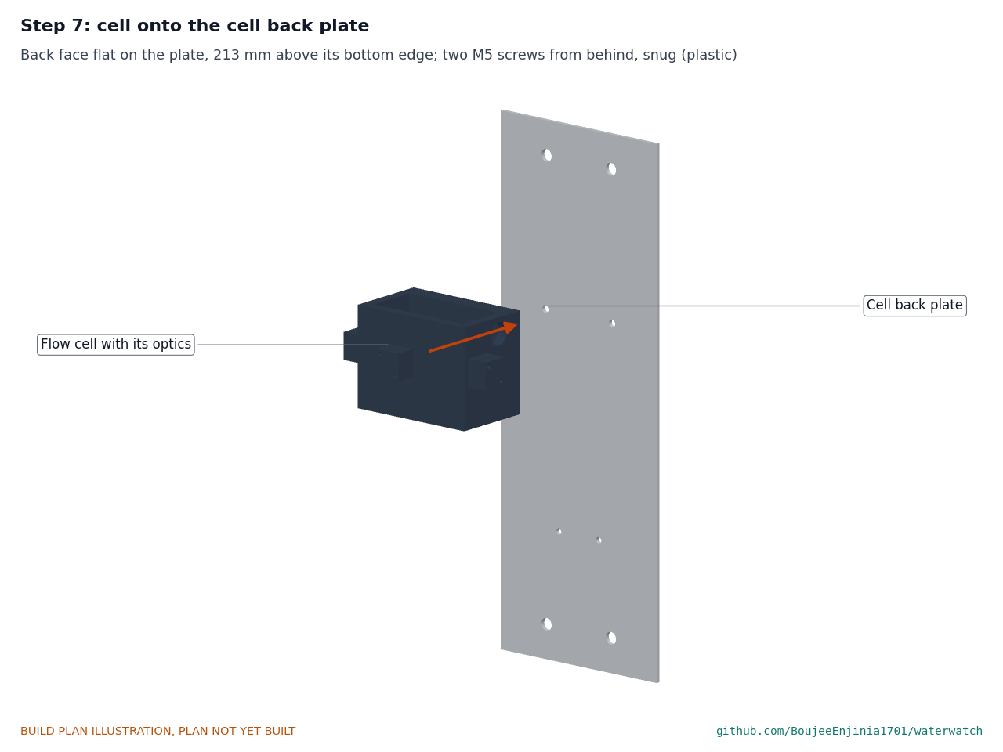
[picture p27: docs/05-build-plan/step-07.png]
Figure 16. Step 7 picture: the cell going onto its plate


*Figure 16. The cell goes onto the cell plate with its optics holders already fitted.*

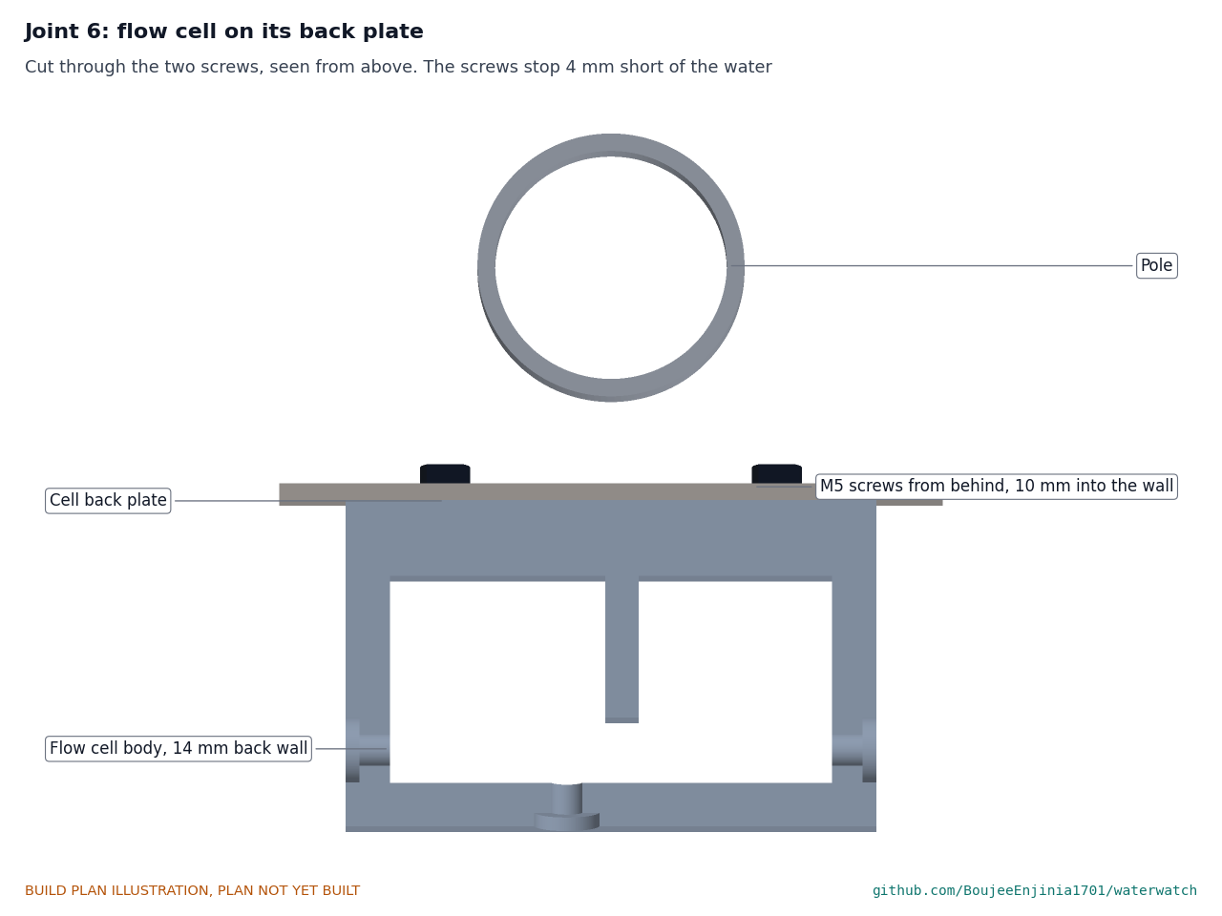
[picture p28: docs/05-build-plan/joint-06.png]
Figure 17. Joint 6: flow cell on its back plate


*Figure 17. Two M5 screws from behind the plate go 10 into the 14 mm back wall and stop 4 short of the water.*

The back face sits flat on the cell plate, held by two M5 screws from behind. The holders sit on the three windows (Figure 21), the lid on the top face (Figure 24), the inlet fitting in the floor (Figure 26) and the outlet hose tail in the right wall (Figure 27).

**Check before moving on.** Plug the inlet and the outlet, fill the pocket with water and stand it on paper for 30 min: no wet mark. The windows show no daylight from inside when you look in from the top with the holders off and your hand over the pocket.

### 3.7 Optics holders (make 3)

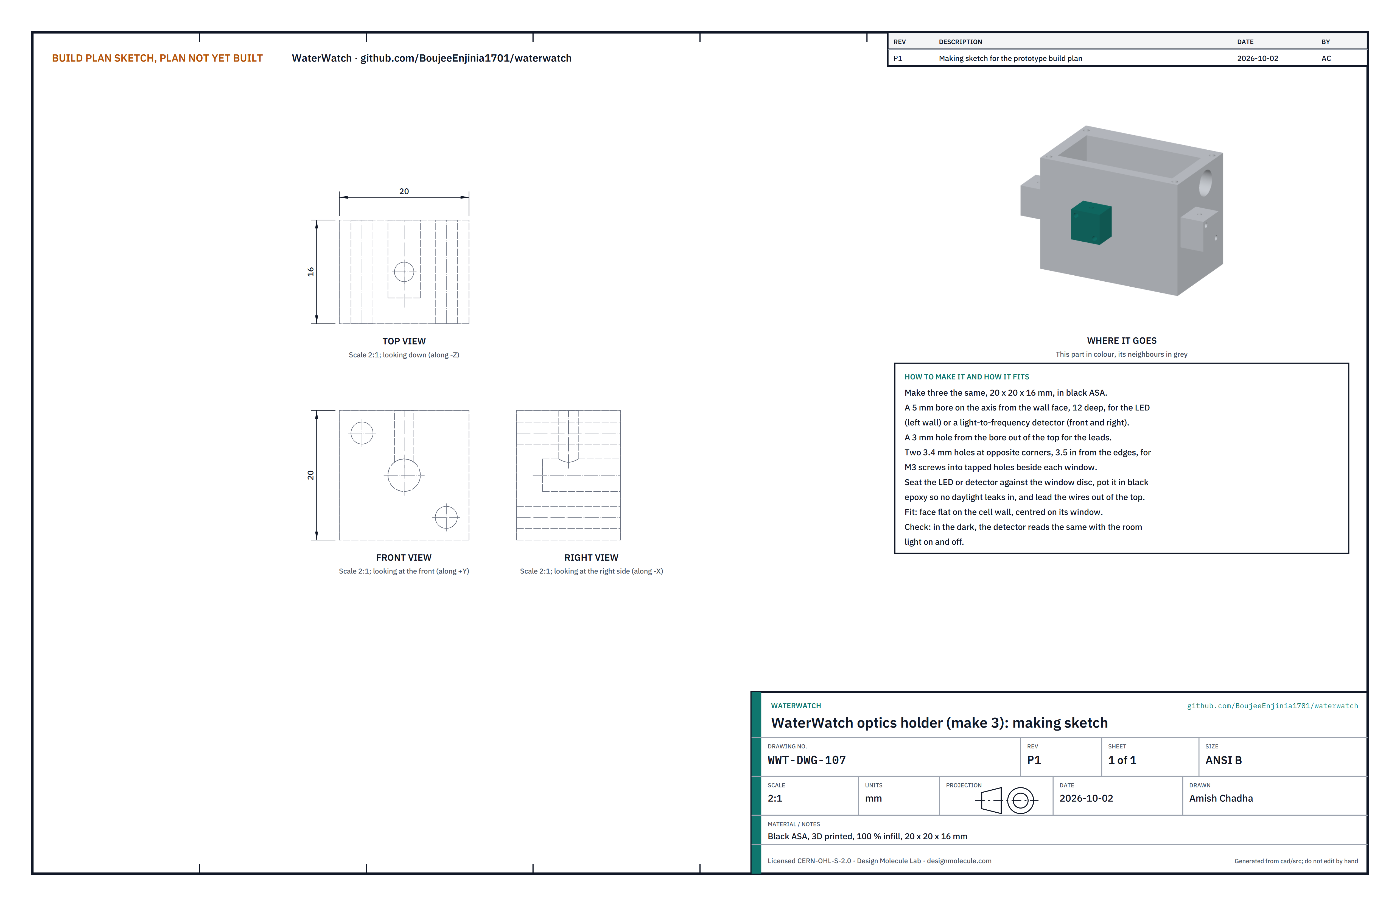
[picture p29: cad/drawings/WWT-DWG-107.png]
Figure 19. Making sketch of the optics holder


*Figure 19. Optics holder making sketch (WWT-DWG-107).*

**What it is and what it is made from.** Three small black blocks that hold the infrared LED (left wall), the 90° detector (front wall) and the 180° reference detector (right wall) against their windows and keep daylight out. Black ASA, printed at 100 % infill, 20 x 20 x 16 mm.

**How to make it.**

1. Print three, each with a 5 mm bore 12 deep on the axis from the face that goes on the wall, a 3 mm lead hole from the bore out of the top, and two 3.4 mm holes at opposite corners, 3.5 in from the edges.
2. Push the 860 nm LED into one holder and a light-to-frequency detector into each of the other two, against the window face, leads out of the top.
3. Pot each in black epoxy so no light can reach it except through the window.

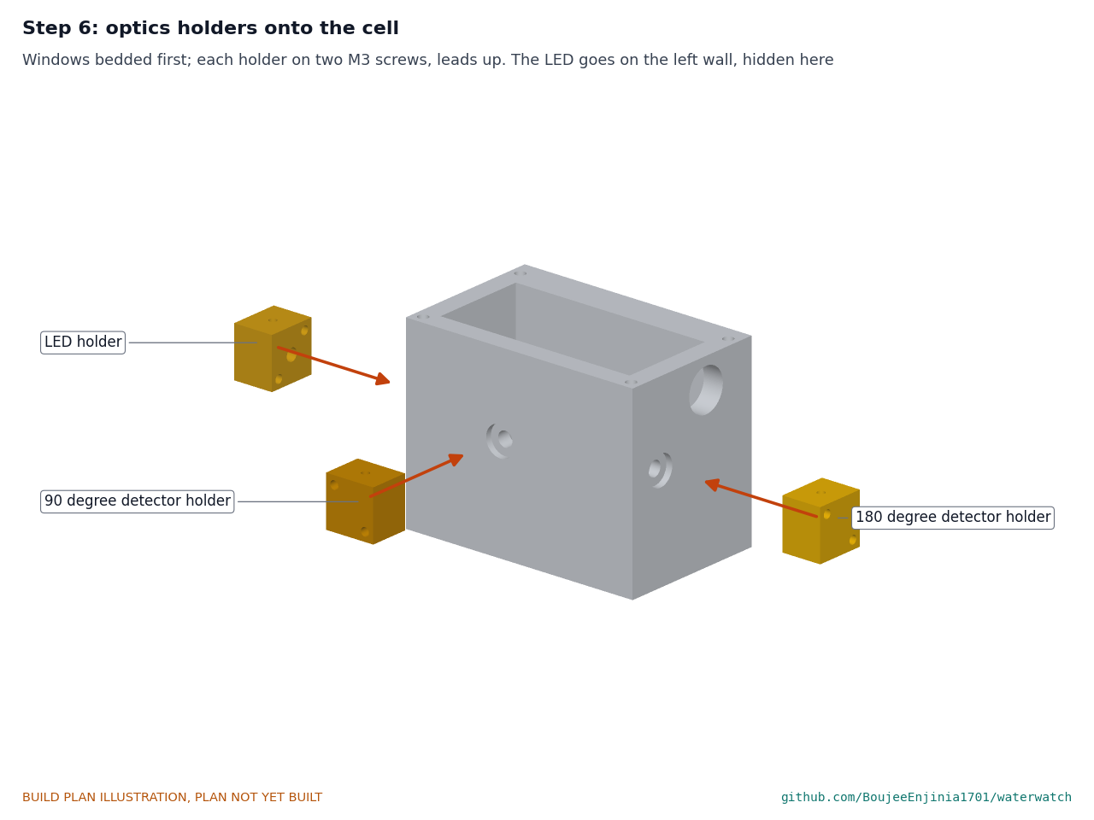
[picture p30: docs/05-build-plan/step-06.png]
Figure 20. Step 6 picture: the holders going on


*Figure 20. Each holder goes onto its window on two M3 screws.*

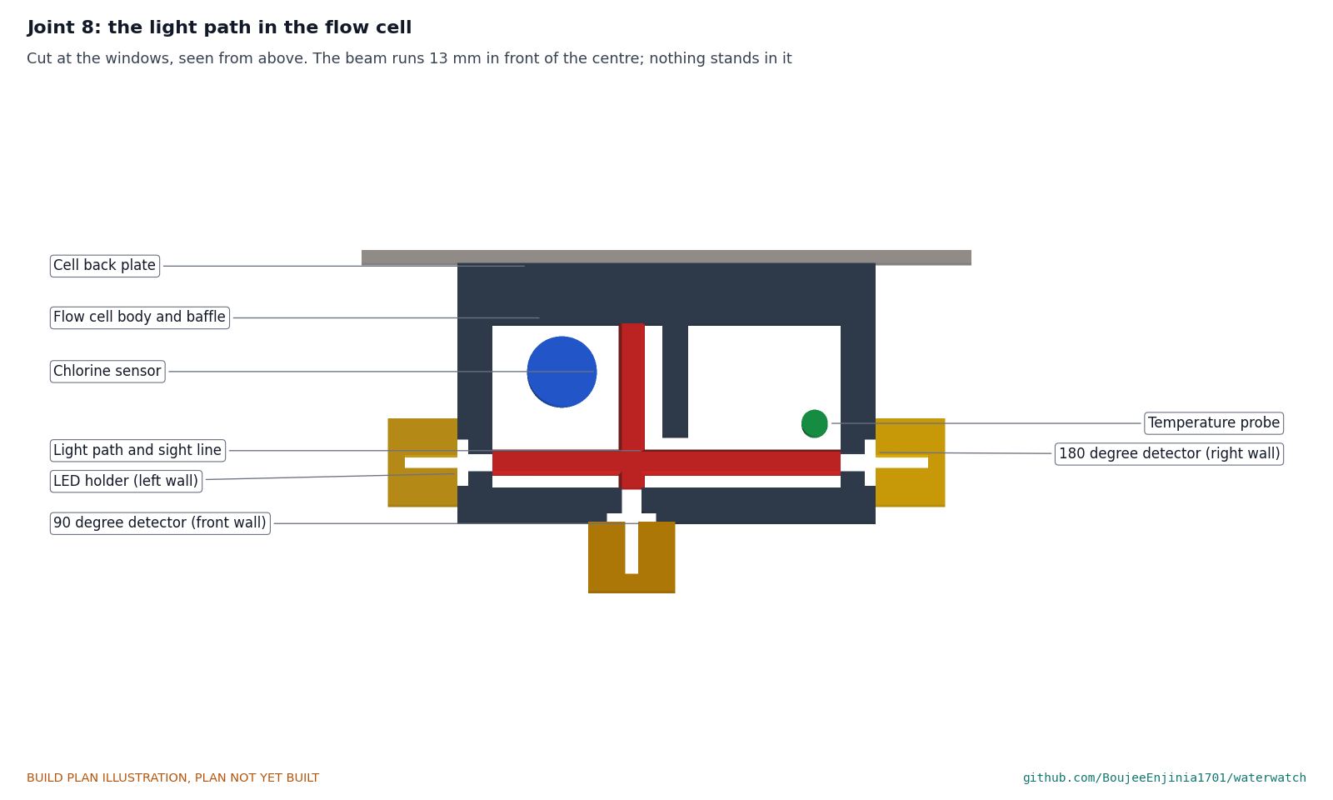
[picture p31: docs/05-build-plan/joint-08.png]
Figure 21. Joint 8: the light path in the flow cell


*Figure 21. Cut at the windows, seen from above. The beam runs from the LED on the left to the reference detector on the right, 13 in front of the pocket centre; the 90° detector looks across it from the front; the sensors and the baffle stand behind the beam.*

**How it fits the parts next to it.** Each holder's face sits flat on the cell wall, centred on its window, on two M3 screws. The three leads join one 6-core cable in a heat-shrink splice beside the LED holder.

**Check before moving on.** In a dark room, with the cell full of clean water, each detector reads the same with the room light switched on and off.

### 3.8 Free chlorine sensor

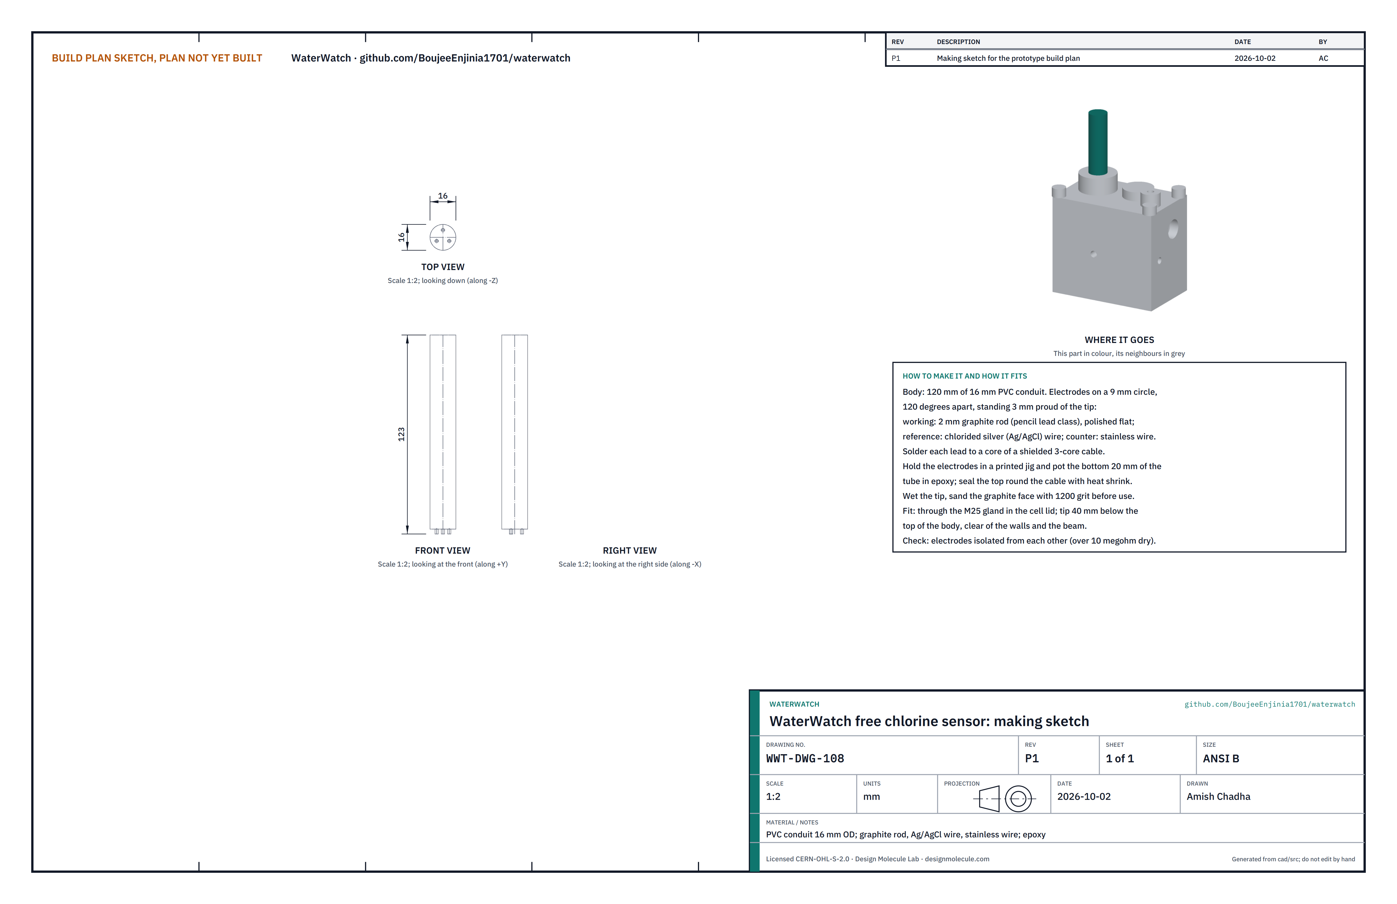
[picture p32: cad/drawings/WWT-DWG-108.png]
Figure 22. Making sketch of the free chlorine sensor


*Figure 22. Free chlorine sensor making sketch (WWT-DWG-108).*

**What it is and what it is made from.** A membrane-free three-electrode sensor: a graphite working electrode, a silver chloride reference and a stainless counter electrode, potted in the tip of a plastic tube. 16 mm PVC conduit, 2 mm graphite rod, chlorided silver wire, stainless wire, epoxy.

**How to make it.**

1. Cut 120 mm of 16 mm PVC conduit and deburr both ends.
2. Solder each electrode to a core of a screened 3-core cable and insulate the joints.
3. Hold the three electrodes in a printed jig on a 9 mm circle, 120° apart, standing 3 mm proud of the tube end.
4. Pot the bottom 20 mm of the tube in epoxy and let it cure fully. Seal the top round the cable with adhesive heat shrink.
5. Sand the graphite face flat with 1200 grit and rinse.

**How it fits the parts next to it.** The sensor goes through the M25 gland in the cell lid, its tip 40 below the top of the cell body, clear of the walls, the baffle and the beam (Figure 24).

**Check before moving on.** Dry, the electrodes read more than 10 megohms to each other.

### 3.9 Flow cell lid and gasket

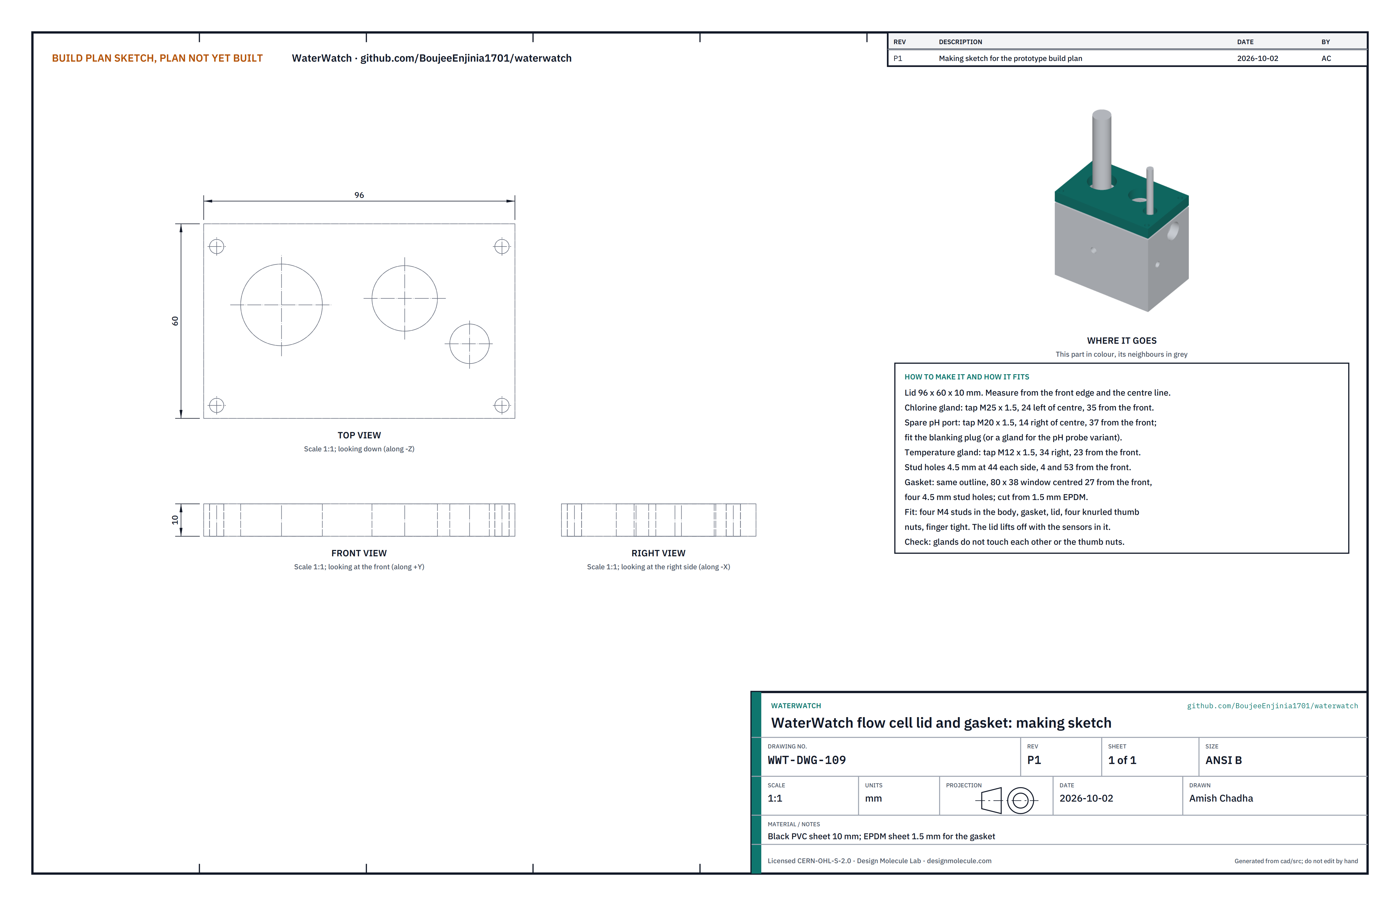
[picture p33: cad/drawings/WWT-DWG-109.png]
Figure 23. Making sketch of the lid and gasket


*Figure 23. Flow cell lid and gasket making sketch (WWT-DWG-109).*

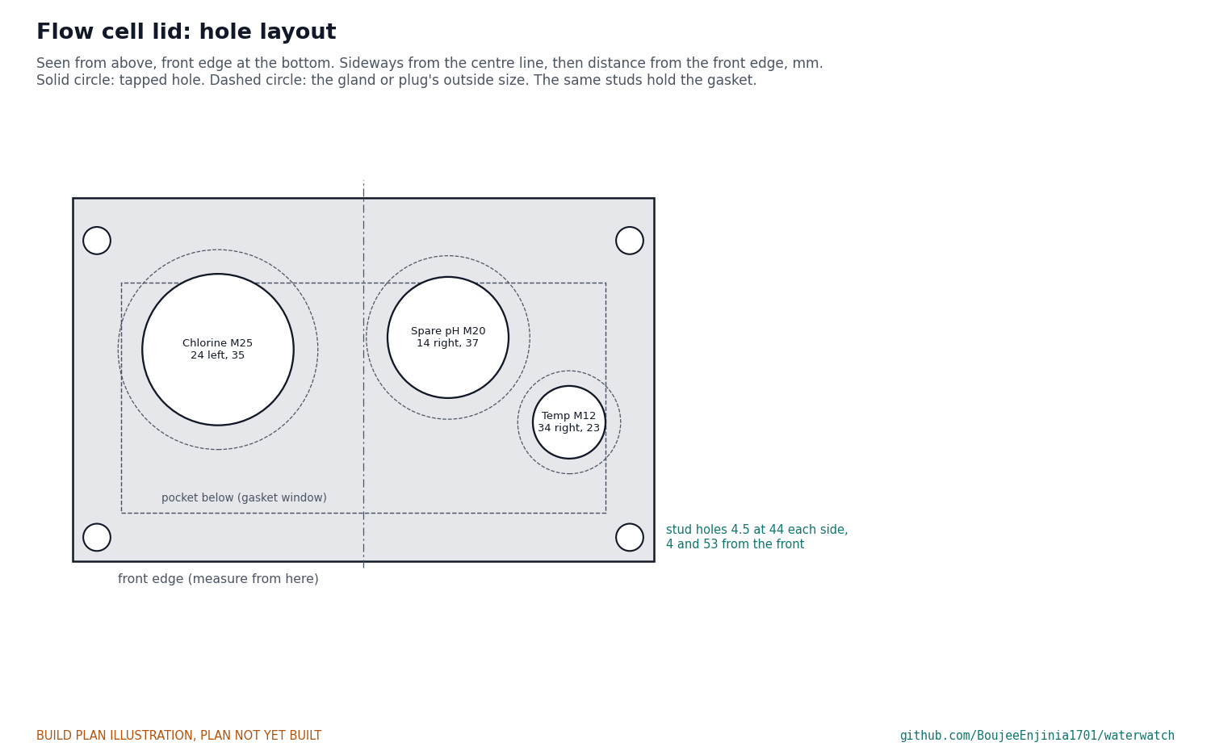
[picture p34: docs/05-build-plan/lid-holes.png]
Figure 23a. Lid hole layout


*Figure 23a. Lid hole layout, front edge at the bottom.*

**What it is and what it is made from.** The lid that carries the chlorine sensor, the temperature probe and the spare pH port, and lifts off with them for cleaning. Black PVC sheet 10 mm, cut to 96 x 60 mm; the gasket from 1.5 mm EPDM sheet.

**How to make it.**

1. Cut the lid to 96 x 60 and mark the front edge.
2. Chlorine gland: drill 23.5 and tap M25 x 1.5, 24 left of centre and 35 from the front edge.
3. Spare pH port: drill 18.5 and tap M20 x 1.5, 14 right of centre and 37 from the front edge.
4. Temperature gland: drill 10.5 and tap M12 x 1.5, 34 right of centre and 23 from the front edge.
5. Stud holes: four 4.5 mm holes, 44 each side of centre, 4 and 53 from the front edge.
6. Gasket: cut the same outline from EPDM, with an 80 x 38 window centred 27 from the front edge and the four stud holes.
7. Screw the M25 and M12 glands and the M20 blanking plug into the lid.

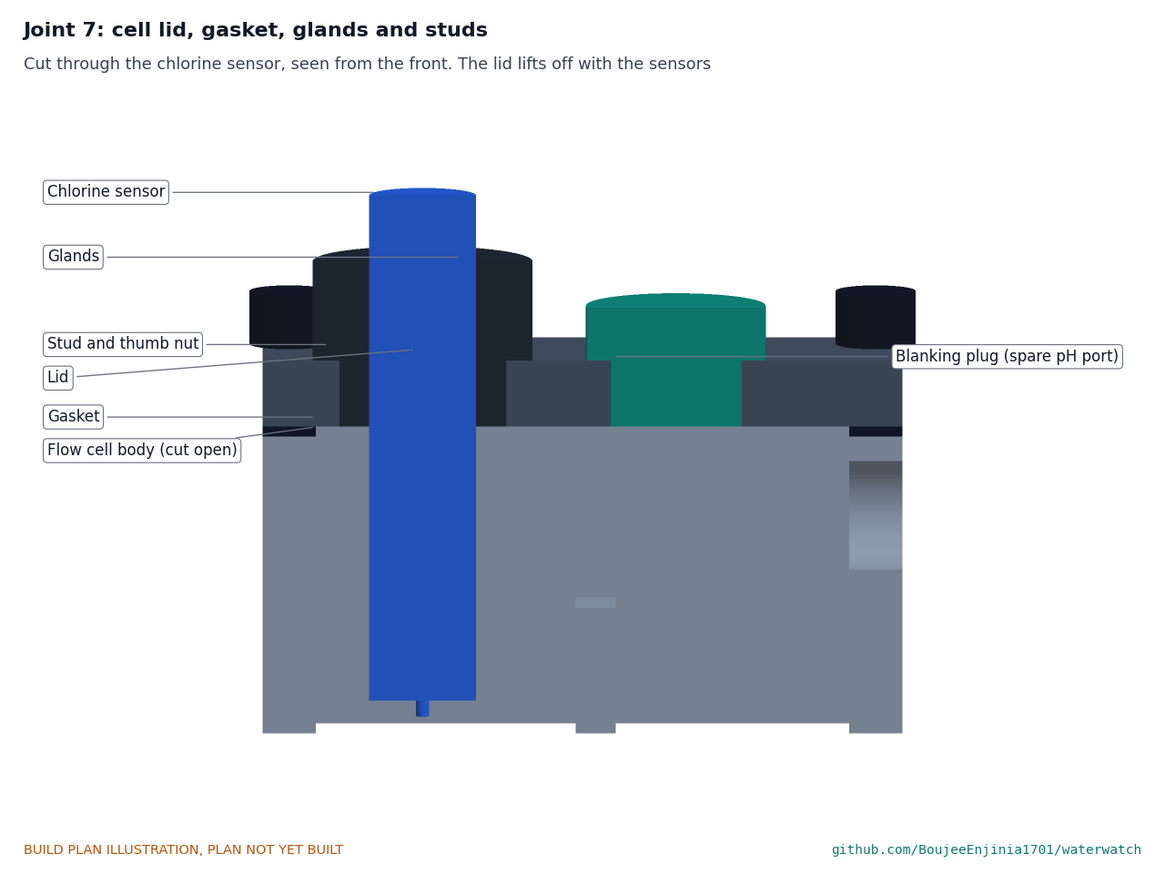
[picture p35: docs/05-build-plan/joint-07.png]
Figure 24. Joint 7: lid, gasket, glands and studs


*Figure 24. Cut through the chlorine sensor. The gasket sits between body and lid; the glands grip the sensors; the thumb nuts hold the lid down.*

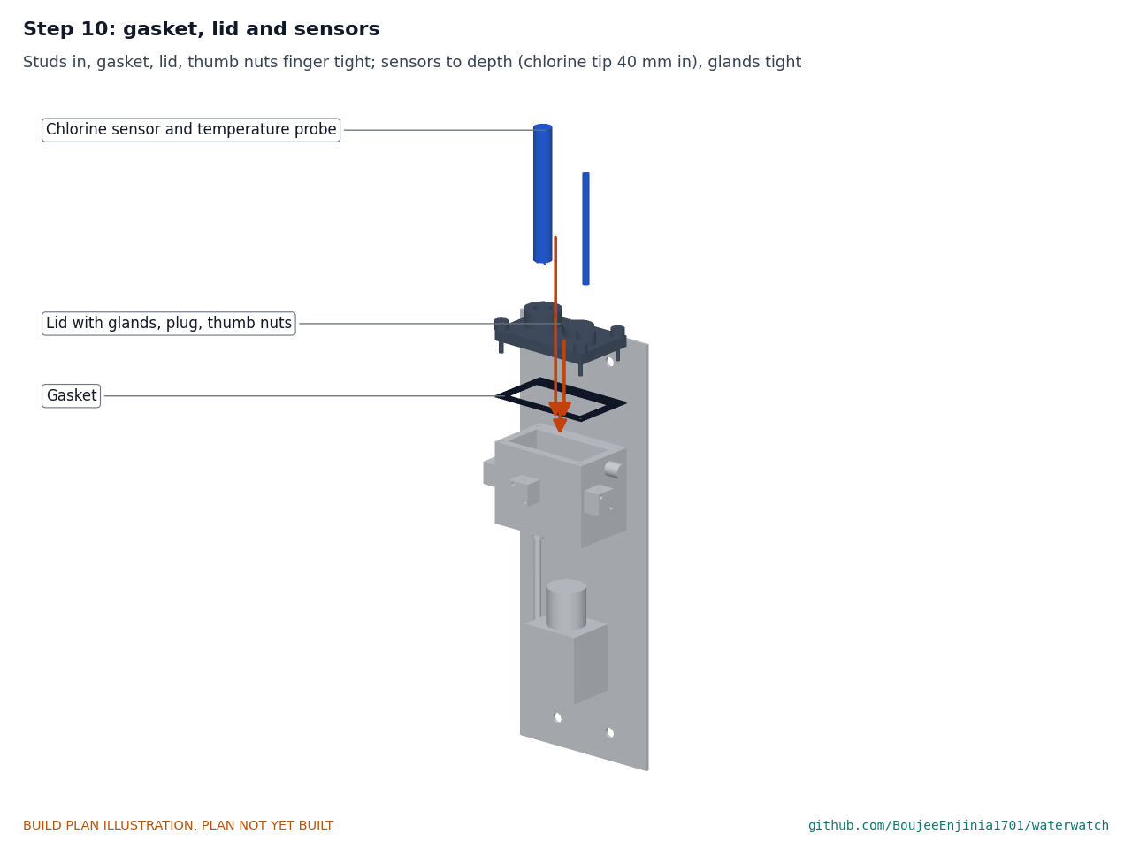
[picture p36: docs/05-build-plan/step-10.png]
Figure 25. Step 10 picture: gasket, lid and sensors


*Figure 25. The gasket and the lid go down over the four studs; the sensors go in from above.*

**How it fits the parts next to it.** Four M4 studs stand in the body's top face; the gasket and the lid go over them and four knurled thumb nuts hold the lid down, finger tight. The temperature probe goes 45 into the cell through its gland. At a site that needs the pH probe, a gland replaces the blanking plug.

**Check before moving on.** No gland body touches another or a thumb nut; with the cell full to the outlet, nothing drips from under the lid.

### 3.10 Bought components

Buy to specification, not brand. Line numbers are those of the bill of materials.

- **Pole, U-bolts and V-saddles (line 1).** 40 NB galvanized tube, 48.3 x 3.2 mm, 2.7 m long; four M8 U-bolts for 48 mm pipe, each with a 90° V-saddle, washers and nyloc nuts.
- **Solar panel and pole-top mount (line 2).** 5 W monocrystalline, 6 V class, about 250 x 190 mm, aluminium frame with fixing holes; a pole-top tilt mount for 48 mm pipe with set screws.
- **Enclosure and lid (lines 3 and 4).** Polycarbonate, IP66, UV stabilized, 200 x 120 x 260 mm, four moulded bosses inside the back wall, tamper-resistant lid screws, and the maker's four-lug mounting kit (line 19). Drill as section 3.2.
- **Battery (line 5).** LiFePO4, 1S2P 32700 cells, 3.2 V, 6 Ah, with protection board, temperature sensor and an in-line 3 A fuse.
- **Controller carrier (line 6) and modem (line 7).** ESP32-S3 module, LiFePO4 solar charger with a 0 to 45 °C charging window, LMP91000-class potentiostat, 12 V boost valve driver, microSD and real-time clock; LTE-M and NB-IoT modem with 2G fallback and SIM holder.
- **Antenna (line 8).** LTE and GSM whip about 140 mm on an SMA bulkhead for a 6.5 mm hole, with pigtail.
- **Temperature probe (line 12).** DS18B20 in a 6 mm stainless sheath, 1 m cable.
- **Valve (line 13).** 12 V latching, direct acting, normally closed, 1/4 in ports, food-safe wetted parts, with two M4 mounting holes in its back face or the maker's bracket.
- **Sample line (line 14).** 25 mm saddle tee with an isolation ball valve; strainer, check valve and pressure-compensating 0.5 L/min regulator, all screwed in line on brass nipples; 1 m of 1/4 in food-grade PE tube; two push-fit elbows (1/8 BSPT).
- **Drain (line 15).** 3/8 BSP hose tail for 12 mm hose, a tee for the air-break vent, 2 m of 12 mm bore hose and a clamp.
- **Glands and cables (line 16).** Seven M16 IP68 nylon glands with nuts (one the spare, one for the status light lead), one M16 blanking plug for the spare, one M12 pressure-equalizing vent; sensor and panel cables.
- **Status light (line 21).** One 5 mm bi-colour LED with a series resistor, a 16 mm clear polycarbonate disc 1.5 mm thick, the printed holder of section 3.4 and 1 m of two-core 3.5 mm lead with crimps.
- **Fixings (line 20).** Stainless: 4 x M5 x 12 screws with nyloc nuts (lugs), 4 x M4 x 12 screws (internal plate), 4 x M5 knurled thumb screws (shield; tamper-resistant M5 screws instead on field units), 2 x M5 x 16 screws (cell), 2 x M4 x 10 screws (valve), M3 screws and 6 mm nylon standoffs, a battery strap, UV-stable cable ties.

### 3.11 How the bought parts join

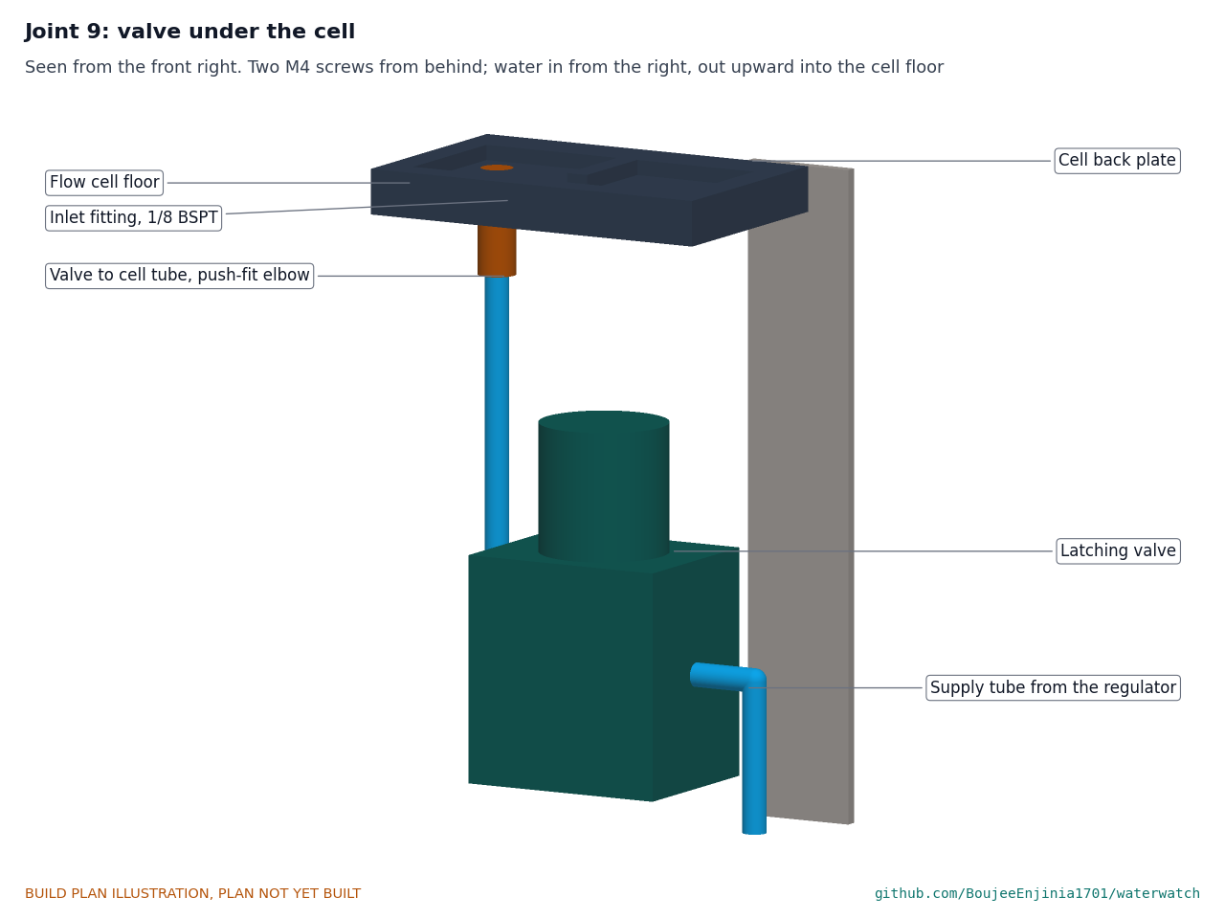
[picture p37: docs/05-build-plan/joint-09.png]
Figure 26. Joint 9: valve under the cell


*Figure 26. The valve sits flat on the cell plate under the cell, held by two M4 screws from behind. Water comes in from the regulator on the right and leaves upward through a push-fit elbow and a straight tube into the inlet fitting in the cell floor.*

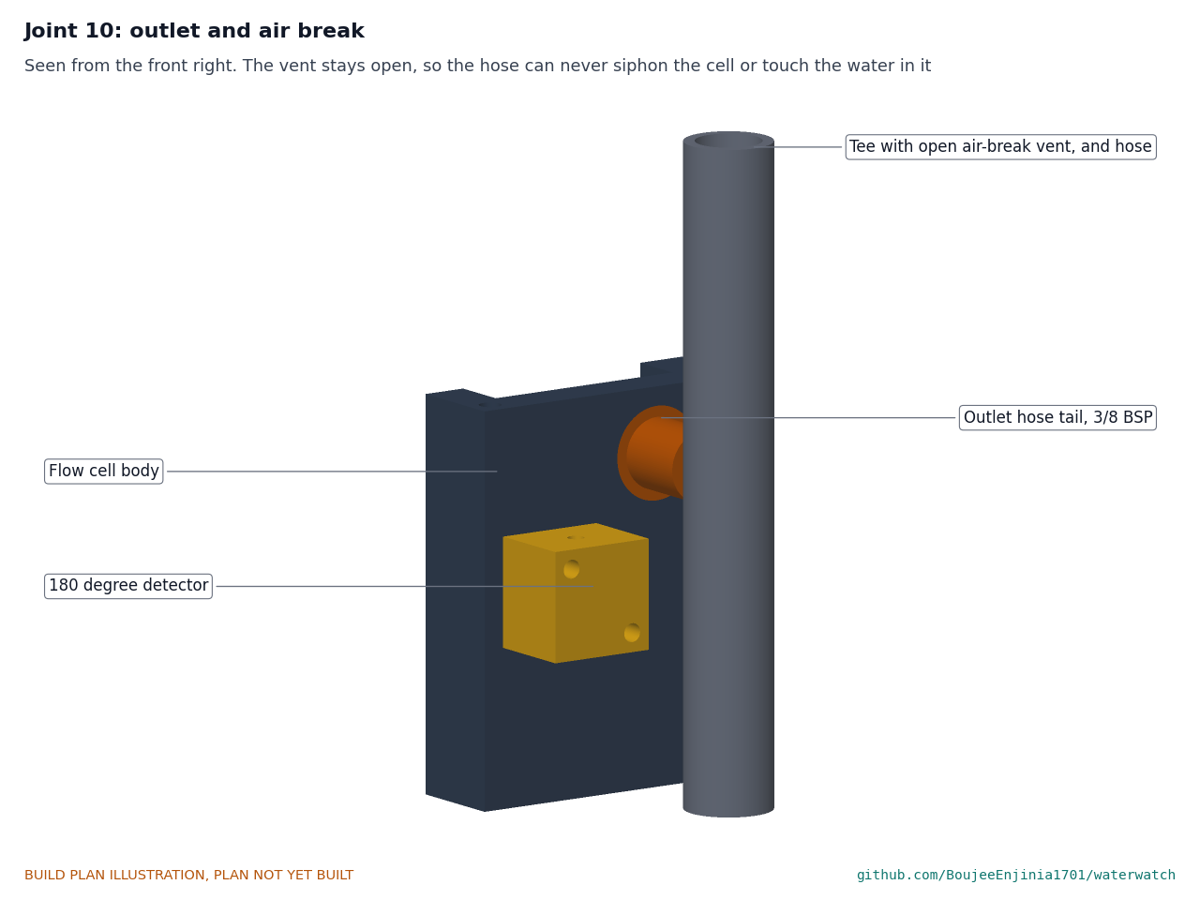
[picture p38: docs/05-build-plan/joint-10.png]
Figure 27. Joint 10: outlet and air break


*Figure 27. The hose tail screws into the right wall near the top. The tee above it carries an open vent pointing up and the hose pointing down, so the hose cannot siphon the cell and the drain never touches the water in it.*

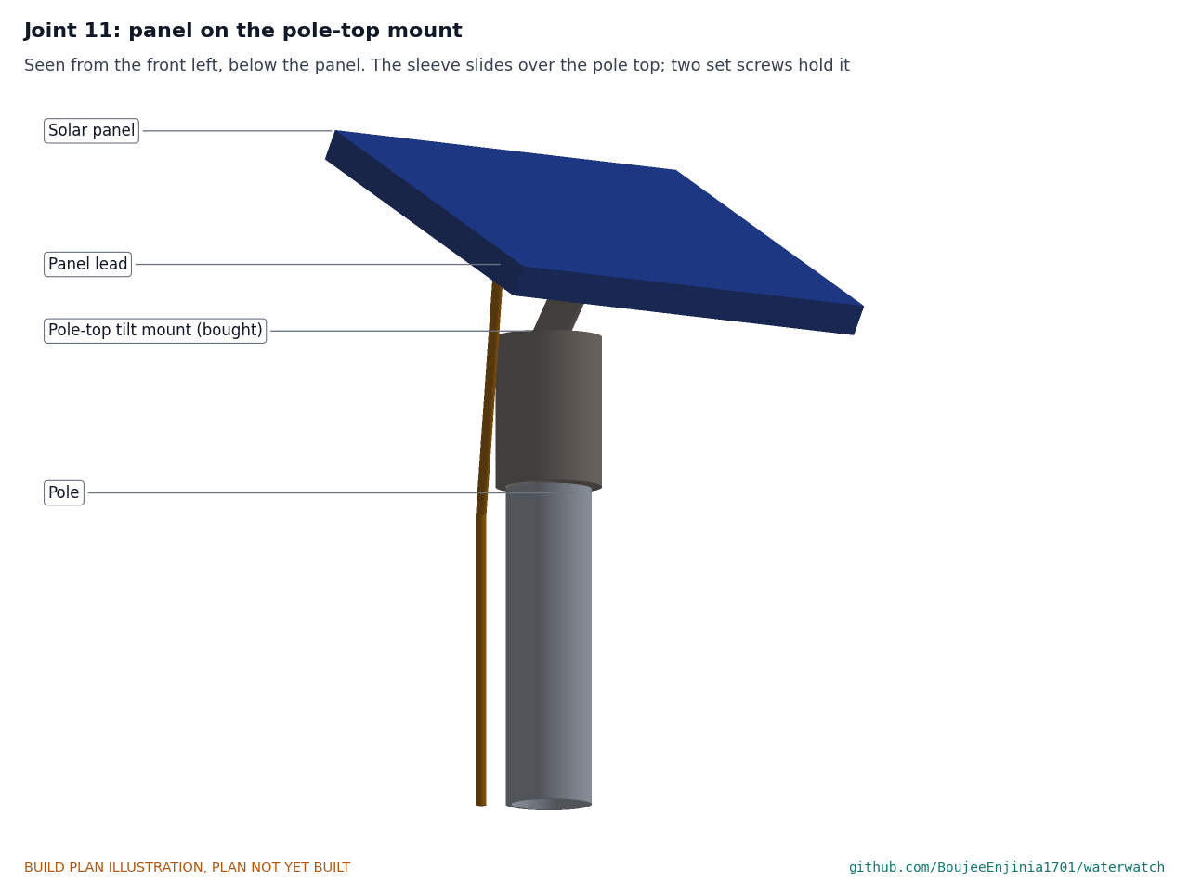
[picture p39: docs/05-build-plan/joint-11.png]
Figure 28. Joint 11: panel on the pole-top mount


*Figure 28. The mount's sleeve slides over the pole top and is held by two set screws; the panel bolts to the tilt rail at 30°. The panel lead leaves the junction box beside the rail.*

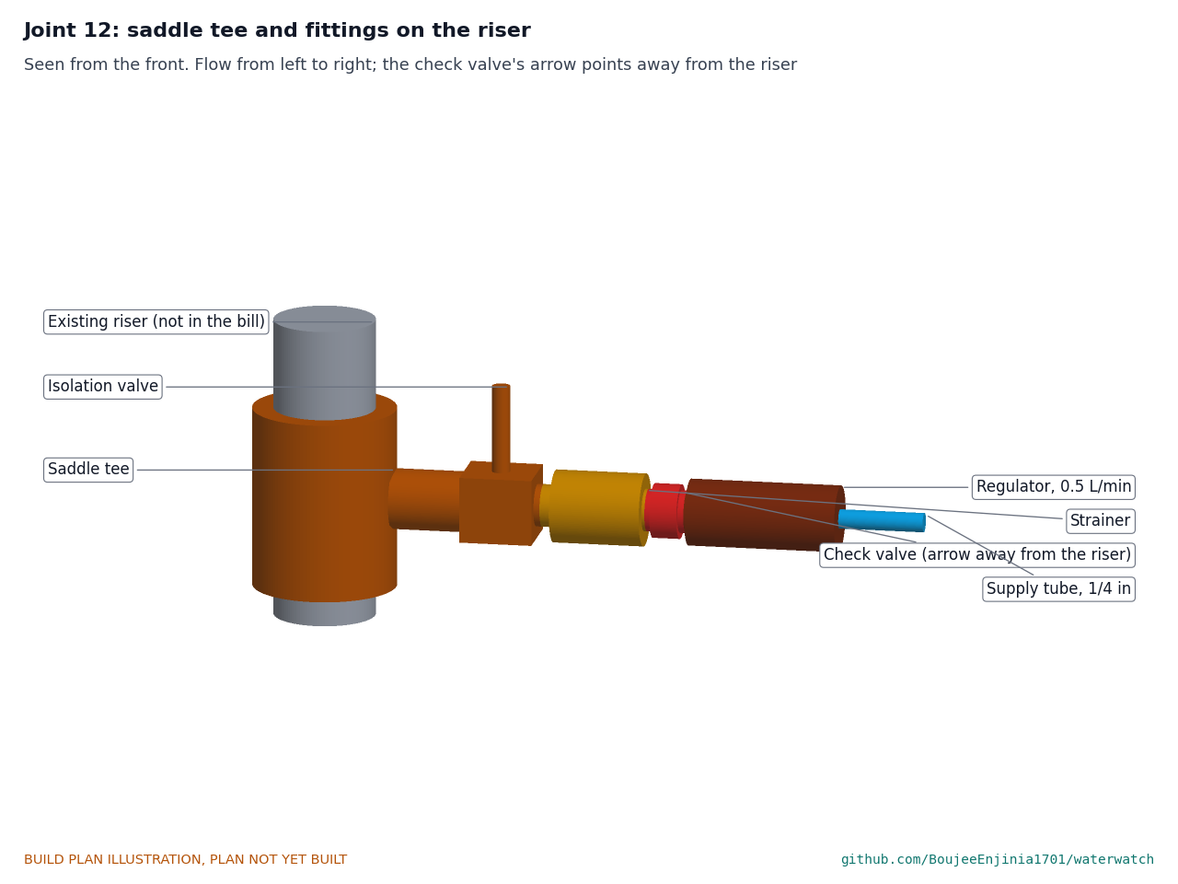
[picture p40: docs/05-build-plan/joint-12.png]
Figure 29. Joint 12: saddle tee and fittings on the riser


*Figure 29. The saddle tee clamps round the riser; the isolation valve, strainer, check valve and regulator screw on in that order, flow from left to right.*

## 4. Putting it together

In each picture the parts already fitted are grey and the parts being fitted are in colour, with an arrow showing the way they go in. Steps 1 to 10 are bench work; steps 11 to 18 are at the site.

### Step 1: glands, vent and antenna into the box

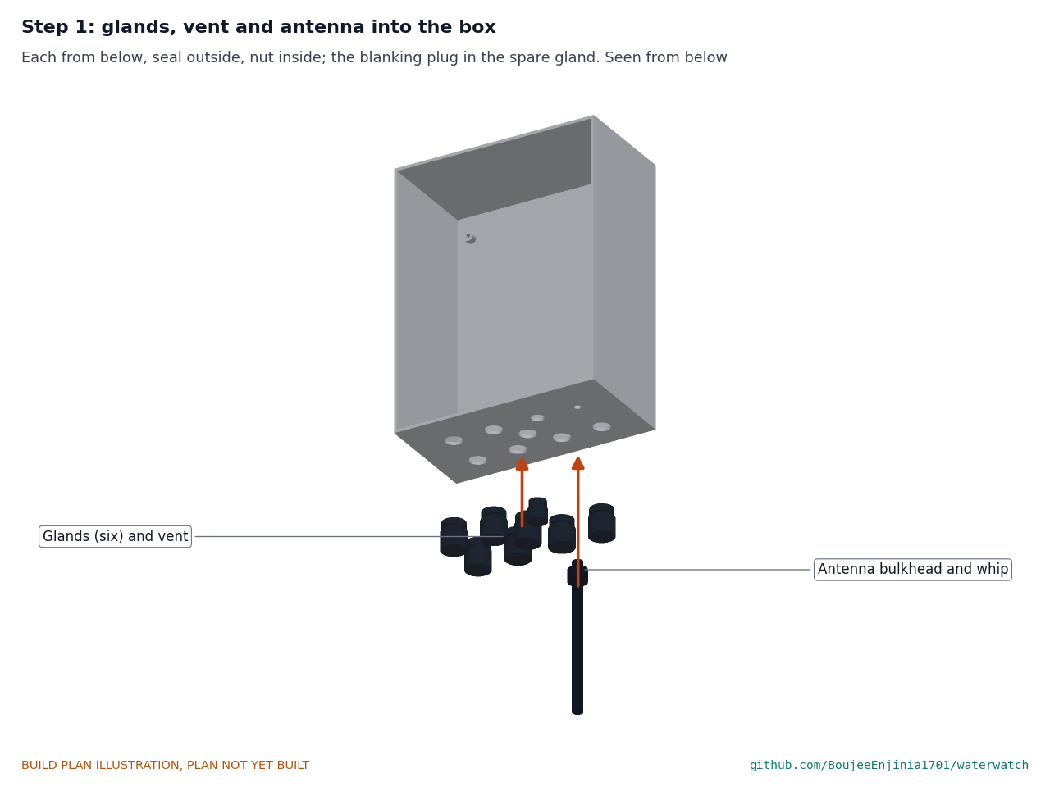
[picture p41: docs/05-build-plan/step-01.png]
Step 1


Each goes in from below with its sealing washer outside and its nut inside, tightened to the maker's torque. Put the blanking plug in the spare gland until a pH probe is fitted.

### Step 2: lugs onto the box

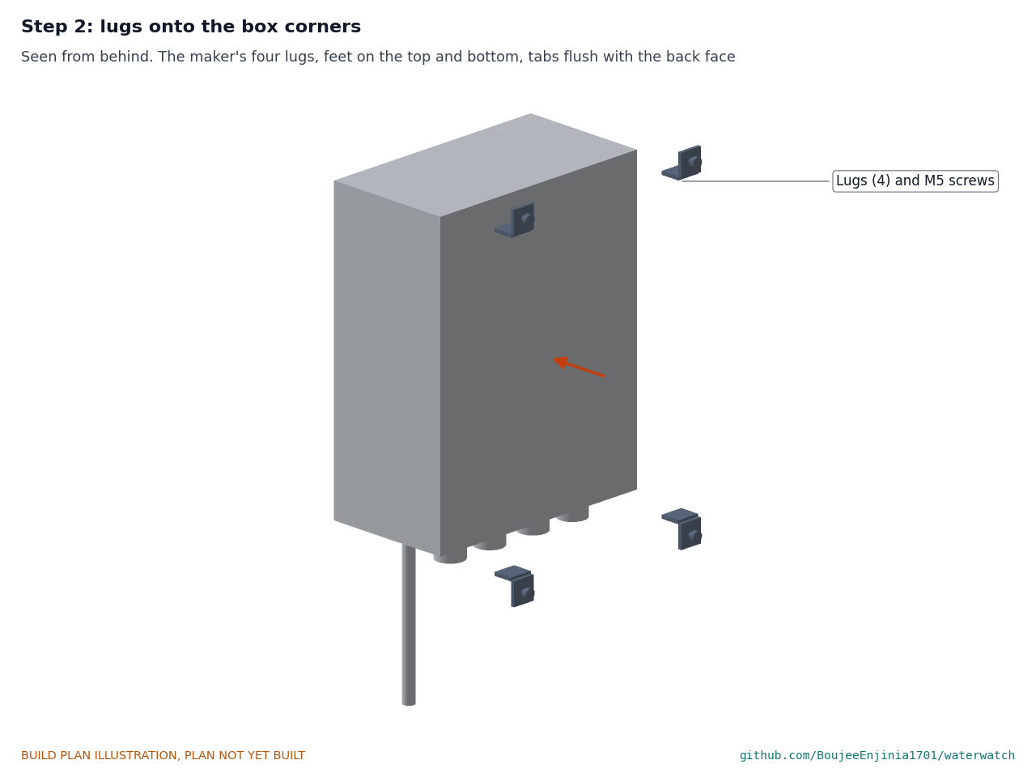
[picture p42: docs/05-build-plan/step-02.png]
Step 2


The maker's four lugs on the back corners, feet on the top and bottom faces, tabs flush with the back face.

### Step 3: build the internal plate

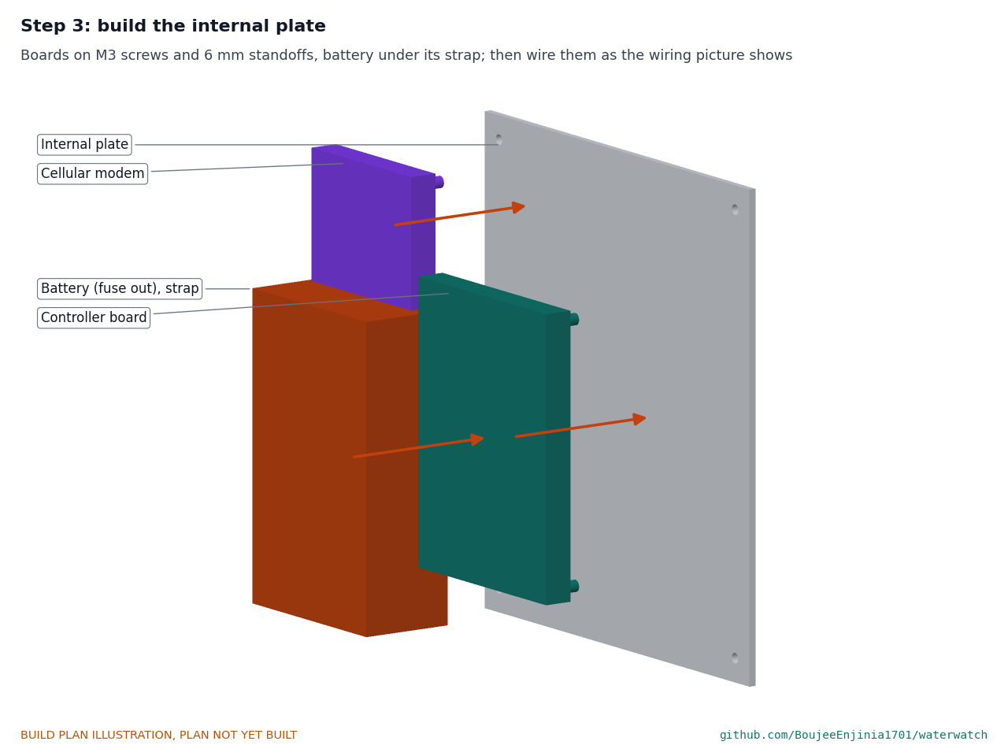
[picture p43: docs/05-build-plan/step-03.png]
Step 3


Boards on M3 screws and standoffs, battery under its strap with its fuse out; wire them as Figure 10. **Hold point:** the wiring checks of section 3.3 pass before going on.

### Step 4: internal plate into the box

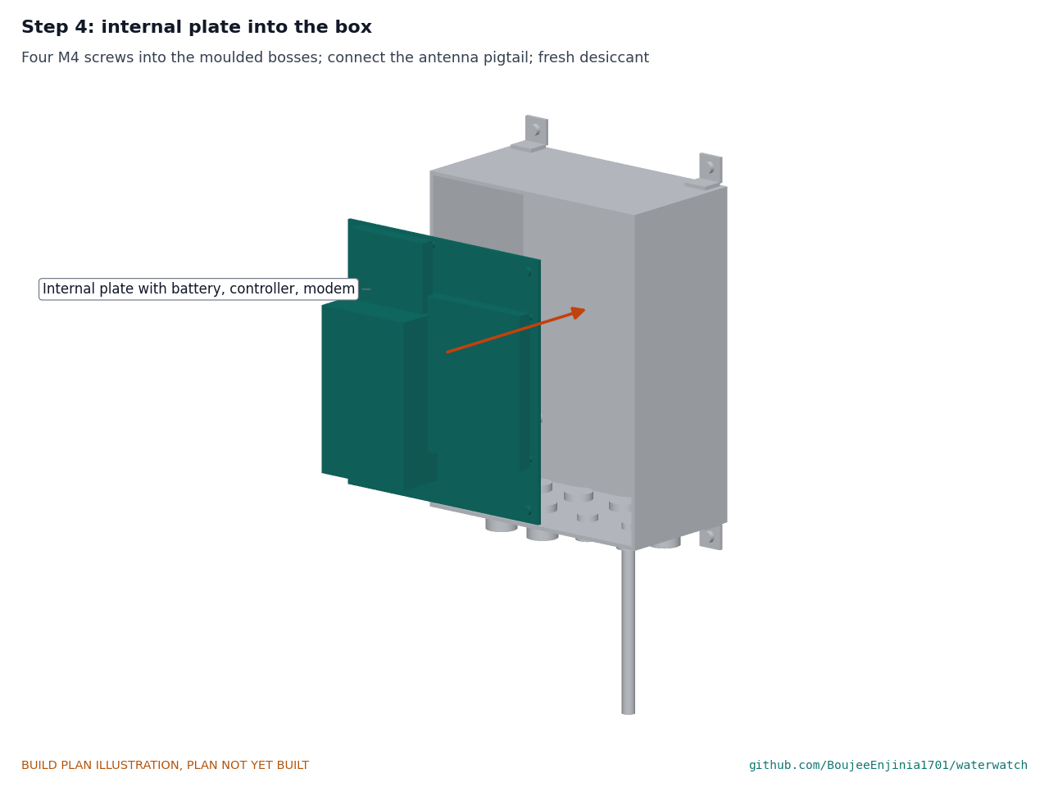
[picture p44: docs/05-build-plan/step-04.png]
Step 4


Four M4 screws into the bosses. Connect the antenna pigtail. Add a fresh desiccant pack.

### Step 5: box onto the enclosure back plate

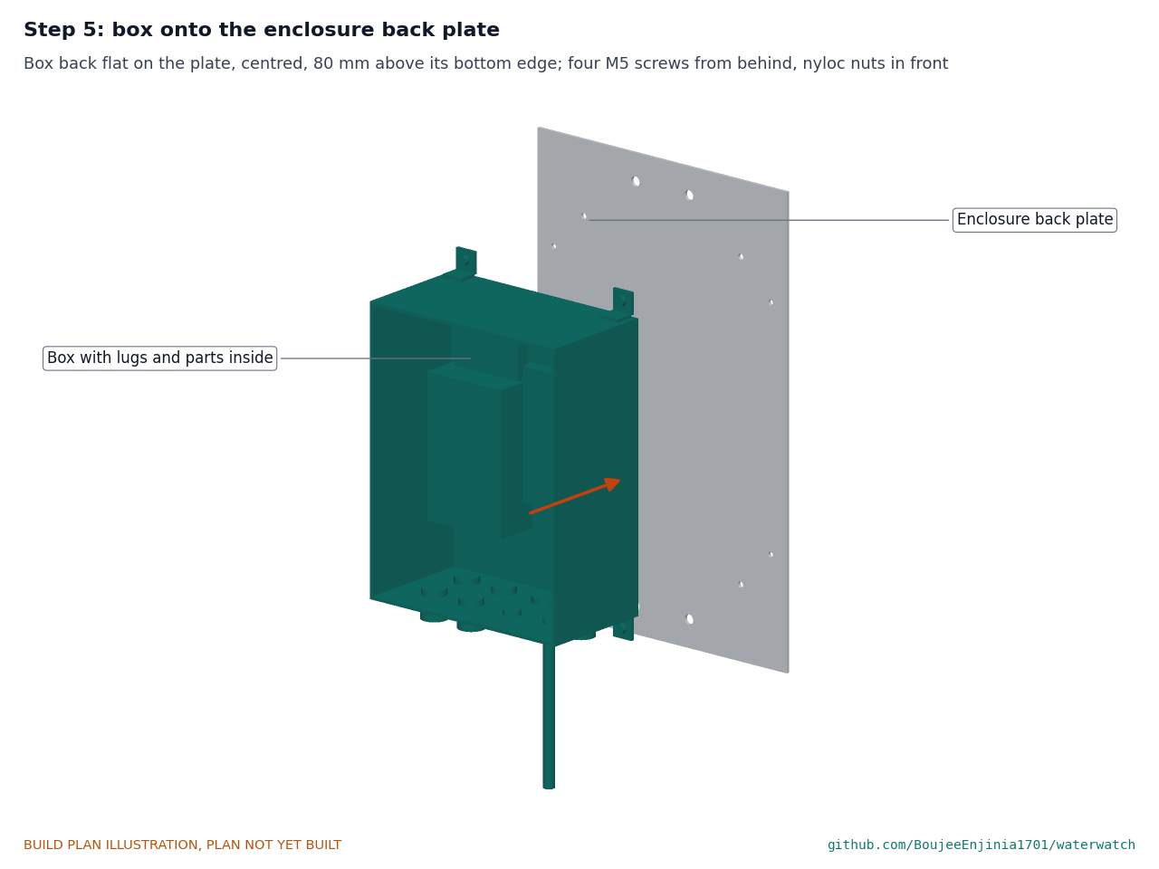
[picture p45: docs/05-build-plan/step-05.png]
Step 5


Box back flat on the plate, centred, 80 above the plate's bottom edge. Four M5 screws through the lug tabs from behind the plate, nyloc nuts in front, snug.

### Step 6: optics holders onto the cell

Step 6

Windows bedded and cured first. Each holder on two M3 screws, leads out of the top; splice the three leads to the 6-core cable.

### Step 7: cell onto the cell back plate

Step 7

Back face flat on the plate, 213 above its bottom edge, centred. Two M5 screws from behind, snug: the threads are in plastic.

### Step 8: valve onto the cell plate

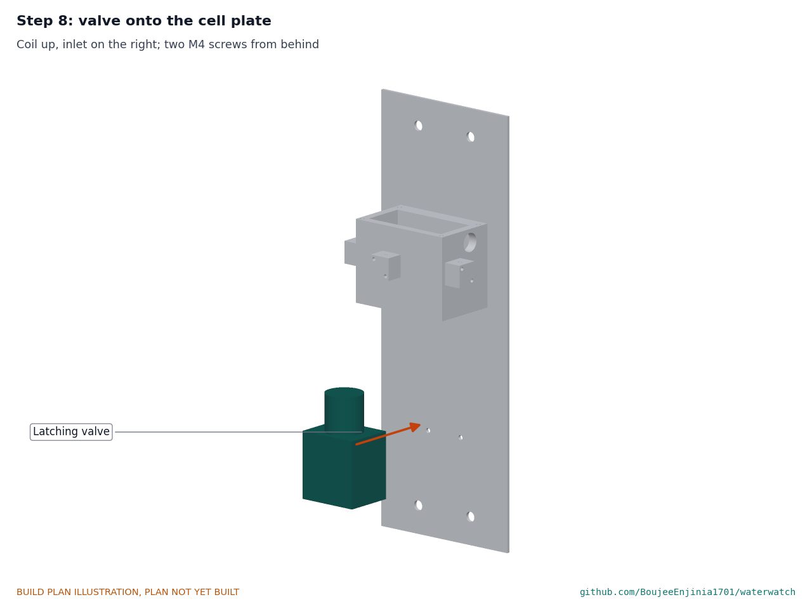
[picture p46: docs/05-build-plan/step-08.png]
Step 8


Coil up, inlet port on the right, centred, 63 above the plate's bottom edge. Two M4 screws from behind.

### Step 9: fittings and the valve-to-cell tube

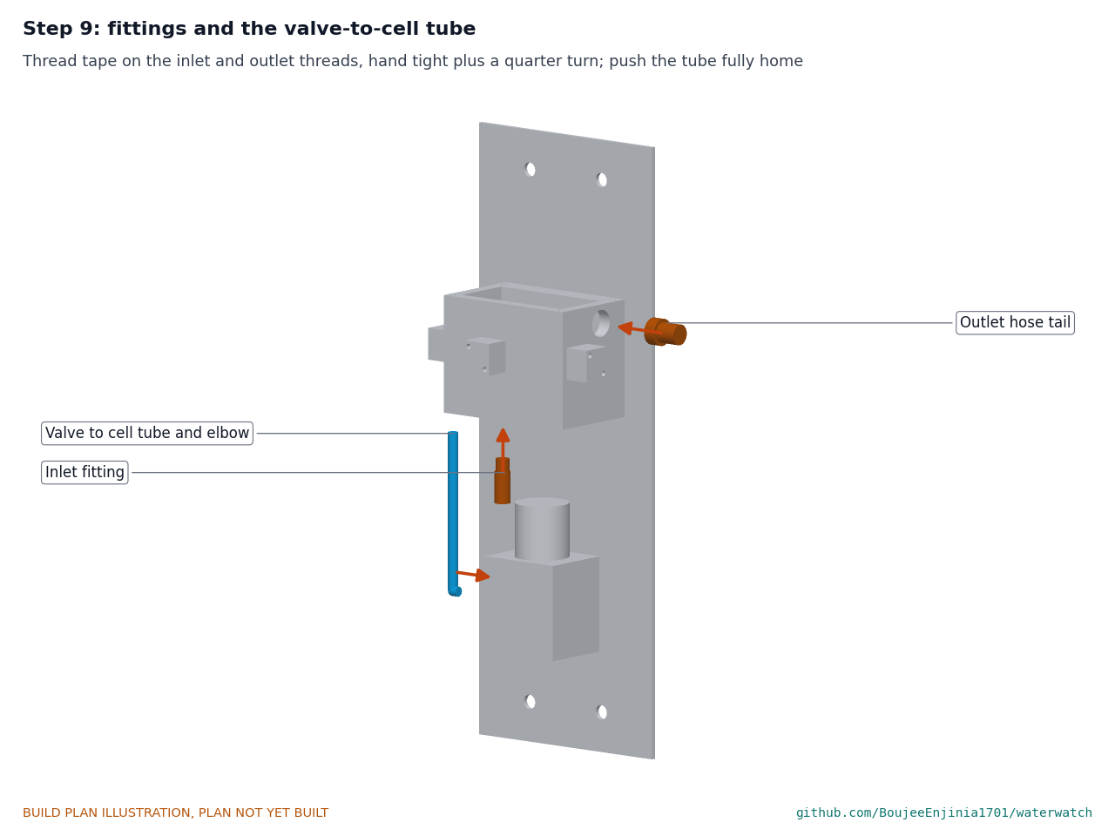
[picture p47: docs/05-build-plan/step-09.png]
Step 9


Thread tape on the inlet fitting and the outlet hose tail, hand tight plus a quarter turn. Push-fit elbow on the valve outlet; tube straight up into the inlet fitting, pushed fully home.

### Step 10: gasket, lid and sensors

Step 10

Studs into the body, gasket, lid, four thumb nuts finger tight. Chlorine sensor down until its tip is 40 below the top of the body; temperature probe 45 in; tighten both glands by hand.

### Step 11: pole and footing (survey visit)

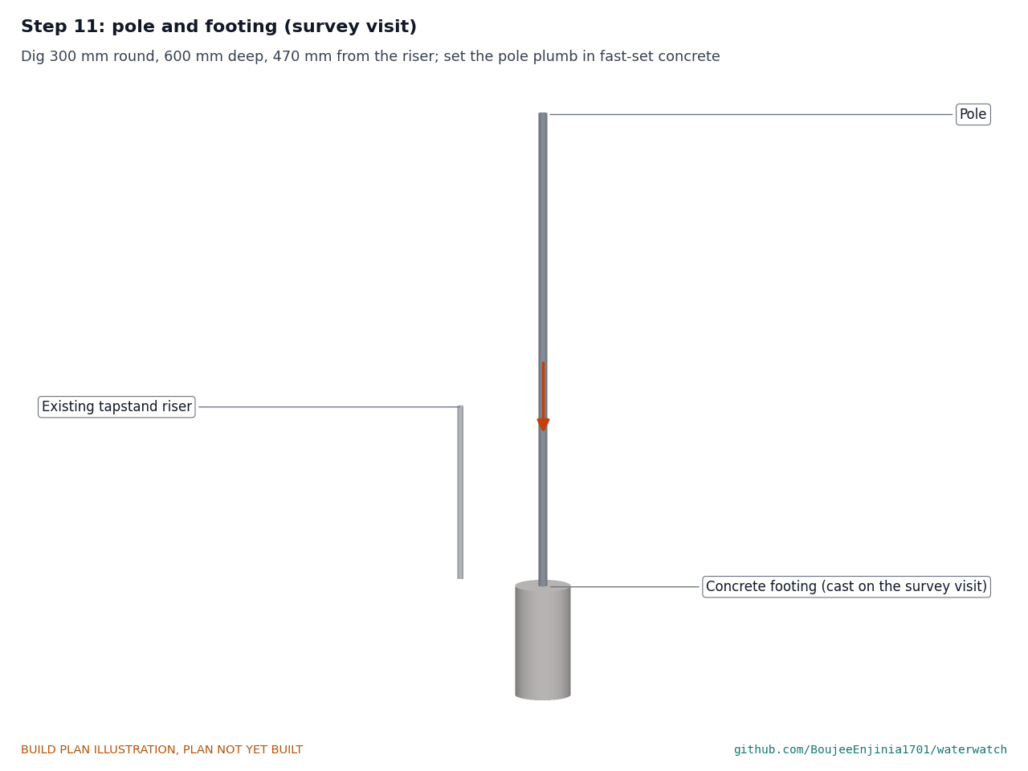
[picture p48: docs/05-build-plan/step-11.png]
Step 11


On the survey visit, before installation day: dig a 300 mm hole 600 deep, 470 mm from the riser centre and square to the tapstand; set the pole plumb in fast-set concrete with 2.1 m standing above the ground.

### Step 12: saddle tee and fittings on the riser

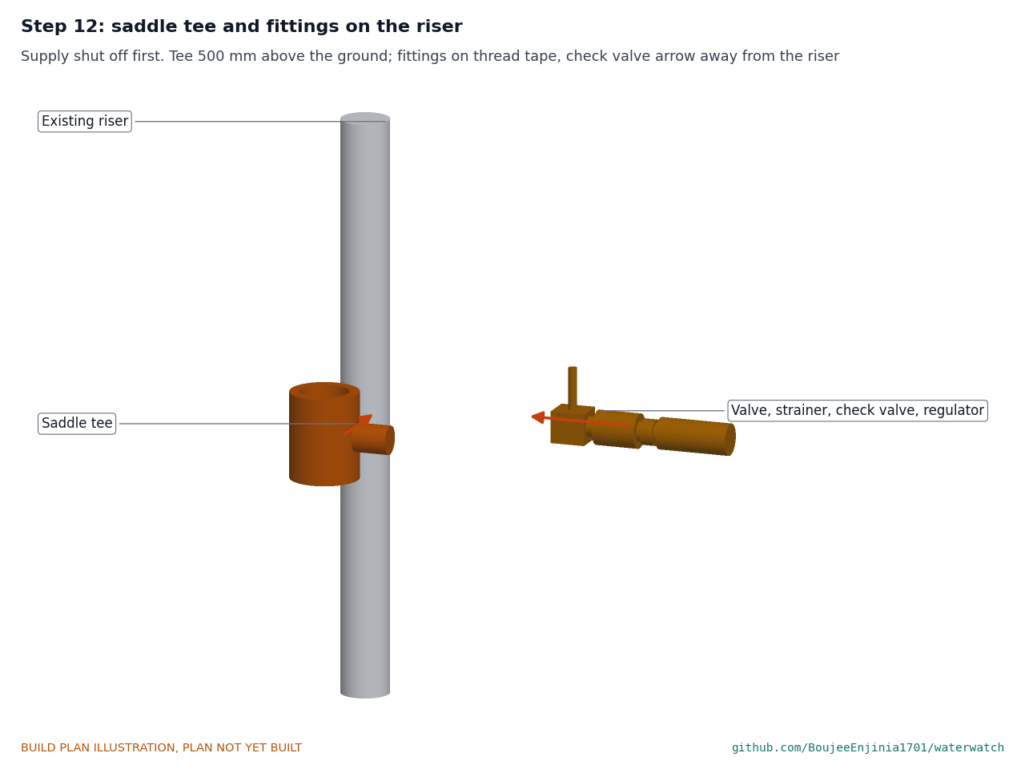
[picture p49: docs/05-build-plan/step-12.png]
Step 12


**Hold point:** the supply to the tapstand is shut off and the riser drained. Saddle tee 500 above the ground; isolation valve, strainer, check valve and regulator on thread tape, with the check valve's arrow pointing away from the riser. Leave the isolation valve shut.

### Step 13: cell plate onto the pole

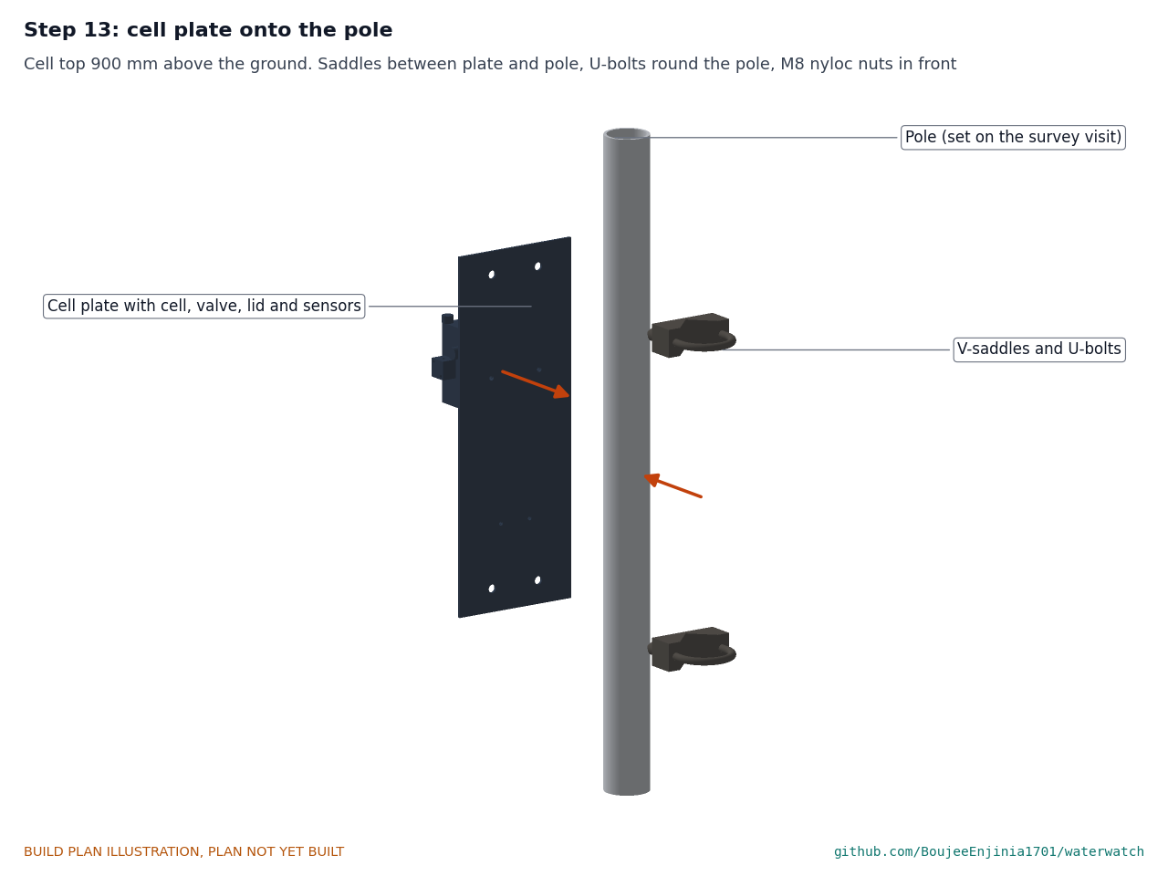
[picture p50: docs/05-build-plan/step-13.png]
Step 13


Seen from behind. The top of the cell lid 900 above the ground, facing the same way as the tapstand tap. A V-saddle between plate and pole at each U-bolt; U-bolts round the pole; M8 nyloc nuts in front, tightened evenly.

### Step 14: enclosure plate onto the pole

Step 14

Seen from behind. Box centre 1,300 above the ground, square with the cell plate below. Same saddles and U-bolts.

### Step 15: panel mount and panel on the pole top

Step 15

Sleeve over the pole top, two set screws. Panel on the tilt rail with the mount's bolts through its frame, facing the equator at 30°.

### Step 16: supply tube and drain hose

Step 16

Push-fit tube from the regulator outlet to the valve inlet, clipped to the pole. Tee on the outlet hose tail with the vent pointing up and open; hose down to the basin, clamped, falling all the way.

### Step 17: cables into their glands; close the lid

Step 17

Status light lead into its own gland, its free end left hanging under the box. Panel lead down the back of the pole, tied every 300 mm, under the plate and up into its gland; sensor and valve cables up the front of the cell plate into theirs. A drip loop below each gland; tighten the gland caps. Lid gasket clean, lid screws in a cross pattern. **Hold point:** safety stops S3 to S6 in section 6.

### Step 18: sun shield

Step 18

Slide it over the box from the front until its flanges lie on the plate; four M5 thumb screws, finger tight. Field units take tamper-resistant M5 screws here.

### Step 19: status light unit

Step 19

Lift the unit up into the slot in the shield front, lens facing out, and let its lead hang down to the gland under the box. To take the shield off again, pull the unit down out of the slot first.

## 5. First checks

These are the checks a TRL 4 test report would record; this plan only lists them. Requirement numbers are those of WWT-REQ-001.

*Table 2. First checks.*

| Check | Requirement | How | Pass when |
| --- | --- | --- | --- |
| Cell holds water | R2, R9 | Fill the closed cell to the outlet on the bench; 30 min on paper | No wet mark |
| Light tight | R2, R9 | Detectors read in a dark room with the light on and off, cell full | Same reading both ways |
| Turbidity response | R2 | Clean water, then a prepared, stabilized 20 NTU standard | The 90° reading rises clearly; the 180° reading falls |
| Chlorine response | R1 | Tap water and the same water after standing open a day, each checked with a DPD kit | The current follows the DPD difference |
| Temperature | R3 | Probe beside a reference thermometer in a water bath | Within 0.5 °C |
| Charge voltage and cut-offs | R7, R9 | Bench supply at 6 V in place of the panel, 1 A limit, temperature sensor replaced by resistors for -1 °C and 46 °C | 3.6 V charge, give or take 0.05 V; no charge current in either cut-off case |
| Valve | R4, R7 | Pulse open and closed from the controller | Opens and closes on one pulse each; no current between pulses |
| Flow per flush | R8 | Time the outflow at the hose end over 90 s at the site pressure | 0.75 L, give or take 10 % |
| Backflow | R11 | Close the isolation valve, open a drain cock upstream | Nothing flows back past the check valve |
| Air break | R1, R2 | Close the valve after a flush | The cell stays full to the outlet; the vent stays open and dry |
| Report and alert | R5, R6 | Force an upload and a test alert | Upload received; SMS received at the test number |
| Entries sealed | R9 | Look at each washer under a lamp; gland caps tight on their cables | Every washer evenly squeezed |
| Shield gap and fixing | R9 | Measure the gap; push the shield by hand | 25 mm, give or take 3, all round; nothing moves |
| Mounting | R11 | Pole plumb with a spirit level; push on the panel and the box | Plumb within 1°; no movement at a U-bolt |
| Installation time | R11 | Time installation day with two people | 2 h or less |

## 6. Safety stops

Stop at each point. Carry on only when everything listed is true.

- **S1. Before the battery comes into the workshop.** Voltage about 2.8 to 3.4 V; no swelling, dents or leaks; a datasheet from its maker. Fuse out. A charging spot ready on a non-combustible surface with a fire extinguisher for electrical fires within reach.
- **S2. Before the battery fuse goes in.** The wiring checks of section 3.3 pass. Battery polarity at the carrier board checked with a meter, not by wire colour.
- **S3. Before any charging source is connected.** The charge voltage is measured at 3.6 V with the battery out; the panel input polarity is checked at the board.
- **S4. Before the battery is allowed to charge.** Both cut-off checks of section 5 pass with the substitute resistors; the temperature sensor is back on the cells.
- **S5. First charge.** Attended the whole time, lid open, on the charging spot; battery temperature checked every 15 minutes. Stop if it passes 45 °C or 3.65 V.
- **S6. Before the modem transmits.** The antenna is connected. Transmitting without one can damage the modem.
- **S7. Before cutting into the riser.** The supply is shut off at the scheme valve and the riser drained, or a tool for tapping under pressure is used with the operator's permission. Local plumbing rules for a connection to drinking water are checked.
- **S8. Before the isolation valve is opened.** The check valve points away from the riser; every threaded joint is taped and tight; the air break vent is open; the drain hose falls to the basin all the way.
- **S9. Before the pole carries anything.** The concrete has set for at least the maker's time (overnight for a first build); the pole is plumb.
- **S10. Work at height.** Fit the panel from a stable ladder footed by a second person, never on a pole that carries power lines.

## 7. Tools, skills and workspace

**Tools.** Hacksaw or jigsaw with a metal blade; files; bench drill or a drill in a stand; drills 2.5 to 15 mm; step drill to 20 mm; taps M3, M4, M5, M12 x 1.5, M20 x 1.5 and M25 x 1.5, 1/8 BSPT and 3/8 BSP, with their tap drills; small milling machine (or a 3D printer with an enclosure and a 120 x 120 mm bed that prints ASA, for the cell body); scriber, square, steel rule and calipers; soldering iron, ferrule crimper and wire strippers; multimeter with a megohm range; bench power supply with a current limit (0 to 15 V, 0 to 2 A); spanners or sockets for M8 nuts and the glands; pipe wrench and thread tape; spade and post-hole digger; spirit level; stepladder; stopwatch and a measuring jug.

**Skills.** No certified trade is needed for the unit itself. Basic metalwork (marking out, cutting, drilling, tapping), milling or 3D printing, through-hole soldering and crimping, safe use of a bench power supply and care with lithium cells. Connecting to a drinking water supply may need the scheme operator's permission and a plumber's sign-off under local rules. All circuits are extra-low voltage: 3.6 V at the battery, 12 V at the valve pulse, under about 10 V from the panel; no mains wiring is part of this build.

**Workspace.** A bench about 1.2 x 0.6 m; a metalwork corner kept apart from the electronics so chips stay off the boards; a ventilated place for the printer, the epoxy and the silicone; the charging spot of S1.

**Personal protective equipment.** Safety glasses for cutting, drilling, soldering and concrete; gloves for sheet edges, epoxy and wet concrete; hearing protection when cutting; no gloves near a turning drill.

## 8. Where the numbers come from

- Model and constructability checks: `cad/src/model.py` (`python cad/src/model.py --check`, 97 checks); STEP and STL exports in `cad/step/` and `cad/stl/`.
- Pictures: `cad/src/build_plan_media.py`, using `.kit/build_views.py`; written to `docs/05-build-plan/` and `cad/drawings/WWT-DWG-101` to `WWT-DWG-109`.
- General arrangement: `cad/drawings/WWT-DWG-001.pdf`, Rev P4.
- Calculations: `docs/04-calcs/01-sizing.md` (WWT-CAL-001 v0.4) and `docs/04-calcs/sizing.py`; flush and tube [D1] to [D5], enclosure temperature [C4], installation [J2], cost [K1].
- Bill of materials: `bom/bom.csv`.
- Decisions: `docs/decisions/0003-design-for-construction.md` (WWT-DDR-003), with WWT-DDR-001 and WWT-DDR-002; design decisions register `docs/06-design-decisions.md` (WWT-DEC-001).
- Requirements: `docs/03-requirements.md` (WWT-REQ-001 v0.5).

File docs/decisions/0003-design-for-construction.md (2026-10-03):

---
doc_id: WWT-DDR-003
title: WaterWatch design for construction
project: WaterWatch
doc_type: Design decision record
version: "0.3"
status: Draft
date: '2026-10-02'
author: Amish Chadha
license: CERN-OHL-S-2.0
revisions:
- version: "0.1"
  date: '2026-10-02'
  author: Amish Chadha
  change: Changes that make the concept physically buildable, with the reason for each; made under Amish's 2026-09-30 instruction to make the design physically buildable; open for his review
- version: "0.2"
  date: '2026-10-02'
  author: Amish Chadha
  change: Accepted by Amish on 2026-10-02, with A1 to A3 decided as recommended
- version: "0.3"
  date: '2026-10-02'
  author: Amish Chadha
  change: "Status light carried into the model (WWT-DEC-001): lens unit in a slot in the shield front, line 21, seventh gland; cost USD 322"
---

# 0003: Design for construction

- **Date:** 2026-10-02
- **Status:** Draft; accepted. Amish, 2026-10-02: "APPROVED: The open decisions from the last wave (TremorTrace to ZeerBox) came in after the review and aren't on the page either." This approves the recommendation written for each open decision in the design decisions register (WWT-DEC-001 v0.1): every change in Table 1 is accepted as made, and A1 to A3 in Table 3 are decided as recorded there.

## Context

On 2026-09-30 Amish approved the build plan format for the portfolio and wrote: "If you are realising that the design cannot be built as per concept - fix the design assumptions to match and be physically feasible as you draw the illustrations." The TRL 3 model of WWT-DDR-002 showed what WaterWatch does and passed its calculations, but many of its parts were shapes that could not be made, fixed or fitted as drawn. Checking the model with build123d (intersections, distances and volumes between every pair of parts) found the thirteen problems below.

The changes keep what WaterWatch does: the same pole, footing and heights, the same enclosure, battery, controller, modem, panel and tilt, the same flow cell cavity, water volume, baffle size, inlet at the bottom and outlet near the top with its air break, the same sensors, valve, regulator, check valve and drain, and the same sun shield gap. Nothing here changes the pitch, the measurement principle or the safety case. Every change is in `cad/src/model.py`, which now runs 97 constructability checks (`python cad/src/model.py --check`): 68 pairs that must touch do touch without overlapping, 17 pairs keep their stated clearance, no two of the 53 parts overlap, the light path in the cell is clear of every part, and the windows stay under water when the cell stands full. All 97 pass.

## Decision

*Table 1. Changes made to the model, the BOM and the calculations.*

| # | Problem in the concept | Change made | Why this way |
| --- | --- | --- | --- |
| P1 | The enclosure and cell "plates" were solid 10 mm and 43 mm blocks that met the round pole along a line, and the four clamps were rings round the pole joined to nothing. | Two 3 mm aluminium back plates (enclosure plate 270 x 420 mm, cell plate 140 x 385 mm), each held to the pole by two M8 U-bolts through 90° V-saddles, with nyloc nuts on the plate front. The pole axis moves from 94 to 103 mm behind the enclosure centre. | A U-bolt with a V-saddle is the standard bought way to hold a flat plate to a round pole; the pole bears on both faces of the V and the U-bolt pulls it in. The heights of every part are unchanged. |
| P2 | The enclosure had no fixing to its plate. | The enclosure maker's kit of four external lugs, one at each back corner, feet on the box top and bottom, each held by one M5 screw through the plate. | The box back stays sealed and flat on the plate. |
| P3 | The battery, controller and modem floated against the back wall. | A printed internal plate (186 x 205 x 3 mm) on the box's four moulded bosses, 6 mm off the back wall and 37 mm above the floor; boards on 6 mm standoffs; the battery under a strap. The modem moves 13 mm up and 5 mm right, the battery 48 mm up and the controller 5 mm down, to clear the bosses and the gland nuts. | Uses what a stock box already has; leaves room above the floor for cables to bend up from the glands. |
| P4 | The antenna stood on the enclosure top and passed through the sun shield; the panel lead came down through the shield to a top entry; only three glands served five cables. | Every entry is in the bottom face, in two rows 28 and 70 mm from the back face: six M16 glands (panel lead, valve, chlorine, temperature, optics, and a spare closed by a blanking plug for the pH probe variant), the vent and the antenna bulkhead, with the whip pointing down. The panel lead runs down the back of the pole and comes forward under the plate with a drip loop. | Nothing passes through the shield, so the shield can come off, and no entry faces the rain. Flanges are at least 16 mm apart, room for a spanner. |
| P5 | The sun shield had no fixing and could not lift off over the antenna. | A 15 mm flange folded in at the back of each side lies flat on the plate; four M5 thumb screws into tapped holes in the plate. The shield slides off forward. | No tools at the pole; the 25 mm gap on the top, sides and front and the open bottom are unchanged, so the thermal result stands. |
| P6 | The turbidity "head" was one block on the left wall, which cannot give both a 90° scatter path and a 180° reference path; and a beam across the cell at mid-height would have struck the baffle and the chlorine sensor. | Three holders, each 20 x 20 x 16 mm with a 6 mm window: the LED on the left wall, the 180° reference detector on the right wall, the 90° detector on the front wall. The beam runs 13 mm in front of the cavity centre, 41 mm above the underside of the cell. The baffle, unchanged in size, now stands on the back wall instead of the front. | This is the Kelley et al. (2014) geometry the concept cites. The dark back wall is the light trap. The beam is 16 mm under the standing water level. |
| P7 | The three lid ports were in one line: the chlorine and pH gland bodies would have overlapped (22 mm apart, 30 mm needed), and a pH probe in the centre port would have hit the baffle. | Lid layout: chlorine (M25 gland) 24 mm left of centre and 8 mm behind it, spare pH port (M20 gland and blanking plug) 14 mm right and 10 mm behind, temperature probe (M12 gland) 34 mm right and 4 mm in front. | Every gland body clears the others and the thumb nuts; every probe clears the walls, the baffle, the beam and the 90° detector's line of sight. |
| P8 | The cell lid had no fixing and no seal; it was "tool-free" in words only. | A 1.5 mm EPDM gasket and four M4 studs in the body's corners, with knurled thumb nuts. | The lid lifts off with the sensors in it for the monthly clean, without tools. |
| P9 | The cell was held on by nothing. | The back wall is 14 mm thick (body 96 x 60 x 74 mm instead of 96 x 54 x 74 mm); two M5 screws from behind the plate go 10 mm into it, 4 mm short of the water. The cavity and its 0.185 L are unchanged. | No hole through a wet wall; the plate and the screws are reached from behind with the cell full. |
| P10 | The valve hung on the 1/4 in tube, 230 mm from the riser, with no support. | The valve is screwed to the cell plate under the cell (two M4 screws from behind); its outlet goes up through a push-fit elbow into the cell floor. The tube run falls from 738 to 696 mm (10.7 to 10.1 mL). | A plastic tube cannot carry a valve. Keeping the valve beside the cell also keeps the stale water between valve and cell short. |
| P11 | The panel bracket was a rod passing into the pole top. | A bought pole-top tilt mount: a sleeve over the pole top with two set screws and a tilt rail under the panel. | A stock part for a 48 mm pole; the panel position and 30° tilt are unchanged. |
| P12 | The strainer, check valve and regulator were joined by lengths of 1/4 in tube, and the check valve was not drawn. | The isolation valve, strainer, check valve and regulator screw together in one brass line on short nipples off the saddle tee; the tube starts at the regulator outlet. | Threaded fittings make a rigid line; the check valve is now shown where it must go. |
| P13 | Cables ran through the air 60 mm from the pole and through the shield. | Every cable has a route: sensor and valve cables up the front of the cell plate to their glands, the optics cable from the LED holder, the panel lead down the back of the pole. Each clears every part it is not fixed to. | So the plan can say where each one goes. |

*Table 2. Knock-on changes.*

| Item | Change | Reason |
| --- | --- | --- |
| BOM | Lines 1, 2, 3, 8, 9, 10, 13, 14, 15, 16 and 17 respecified; lines 18 (mounting plates), 19 (lugs and internal plate) and 20 (fixings) added. 20 lines, USD 319.00 (was USD 283.00). | Parts added for construction: plates USD 10, lugs and internal plate USD 8, fixings USD 6, three more glands and a blanking plug USD 4, cell gasket, studs and lid glands USD 4, push-fit elbows USD 2, shield fixing USD 1, drain hose tail USD 1. |
| Cost | Value-engineering target: USD 300. Estimated cost of the constructable design: USD 319 (USD 19 over the target). `budget_usd` unchanged. | Savings worth trying are in the design decisions register (WWT-DEC-001). |
| Calculations | WWT-CAL-001 v0.3: tube run 696 mm and 10.1 mL [D1]; two chlorine error figures move by 0.001 mg/L [E4]; cost [K1], [K2]. No requirement changes status except R12, now reported as over the value-engineering target. Energy, solar, temperature, water use, data, alert latency, wind and task times are unchanged. | Re-run of `docs/04-calcs/sizing.py`. |
| Documents | WWT-REQ-001 v0.5 and WWT-PRC-001 v0.5 updated; WWT-DWG-001 Rev P4; making sketches WWT-DWG-101 to 109; build plan WWT-BLD-001; design decisions register WWT-DEC-001. | Follow the model. |
| Media | `media/hero.png`, `cutaway.png`, `exploded.png`, `concept-blueprint.*`, `flow.png`, `model.glb` regenerated. The photoreal renders, `media/card.png` and `media/social-preview.png` (made on Amish's Mac) still show the concept: the antenna through the shield top and the single turbidity block. | Visible change. |

*Table 3. Decided by Amish, 2026-10-02.*

| # | Question | Options | Recommendation |
| --- | --- | --- | --- |
| A1 | The shield now comes off by hand, which lowers tamper resistance at a public tapstand. | (a) knurled thumb screws, as modelled; (b) tamper-resistant M5 screws, which add about 2 minutes to a visit that only rarely needs the box open. | (a) for the prototype; (b) for field units after the first site visit. **Decided by Amish, 2026-10-02.** |
| A2 | The antenna now points down from the bottom face, about 0.1 m above the cell lid and 0.13 m from the steel pole. | (a) keep it there and measure signal strength at TRL 4; (b) a short cable to an antenna on the pole top beside the panel. | (a): it keeps the shield free and costs nothing; (b) if a weak-signal site needs it. **Decided by Amish, 2026-10-02: (a).** |
| A3 | Water stands in the cell only up to the outlet's lower edge, 17 mm below the lid, about 0.14 L, not the full 0.185 L the calculation uses. | (a) keep 0.185 L in WWT-CAL-001, which is conservative for flushing (a smaller standing volume is cleared faster), and measure at TRL 4; (b) revise the calculation now. | (a): no requirement changes, and the chlorine tip stays 23 mm under water. **Decided by Amish, 2026-10-02: (a).** |

*Table 4. Carried into the design, 2026-10-02 (decision of the status light, WWT-DEC-001).*

| Item | Change | Reason |
| --- | --- | --- |
| Status light | One 5 mm LED behind a 16 mm lens in a printed holder whose barrel sits in a 12.2 mm slot, open at the bottom, in the shield front panel; its lead hangs from the unit to a seventh gland in the bottom face (middle row, on the centre line). The unit drops out of the slot downward, so the shield still slides off forward after the four thumb screws. | Decision of 2026-10-02 |
| Clearances | The holder stays 10 mm or more from the clear lid; the lead stays 20 mm or more from the antenna whip. The model's 106 checks pass. | Constructability checks |
| BOM | Line 21 added (USD 2.00); line 16 gains a seventh gland (USD 19.00). 21 lines, USD 322.00, USD 22 over the USD 300 target; `budget_usd` unchanged. | Basis in `bom/bom.csv` |
| Calculations | WWT-CAL-001 v0.4: 2 mWh a day for the light; autonomy 28.5 days. No requirement changes status. | Energy line A2 |
| Drawings | WWT-DWG-001 Rev P5; shield and enclosure sketches (WWT-DWG-104 and 102), the bottom-face layout, joint 3, steps 1 and 17 to 19 and the wiring picture regenerated. | Follows the model |

## Consequences

- `design_state: constructable` in `project.yaml`. The build plan WWT-BLD-001 shows every component and step in pictures generated from the model (`cad/src/build_plan_media.py`).
- Requirement status: none not met, 4 at risk (R1, R2, R9, R10), 5 met on paper, 3 met by design, and R12 over the value-engineering target by USD 19 (WWT-CAL-001 v0.3).
- The appearance model `cad/src/product_model.py` and the photoreal renders still show the concept layout; they need updating on Amish's Mac, where Blender is.
- The enclosure, U-bolt kits, valve and pole-top mount are chosen at TRL 4; the items to confirm when they are bought are listed in WWT-DEC-001.

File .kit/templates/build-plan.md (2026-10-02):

---
doc_id: PRJ-BLD-001
title: Project prototype build plan
project: Project name
doc_type: Build plan
version: "0.1"
status: Draft
date: YYYY-MM-DD
author: Amish Chadha
license: CERN-OHL-S-2.0
revisions:
  - version: "0.1"
    date: YYYY-MM-DD
    author: Amish Chadha
    change: First build plan; design made constructable
---

# Project prototype build plan

**Plan, not yet built.** How to build the first proof-of-concept prototype, component by component. Building and testing to it is TRL 4 work. Decisions still to be made are kept in the design decisions register (`docs/06-design-decisions.md`), not here.

## 1. What you are building

Every component, pulled apart and numbered in build order

One short paragraph: what the prototype is, how many components, which are made and which are bought, and the main ways they are made.

## 2. What changed to make it buildable

| Component | The concept had | The buildable design has | Why |
| --- | --- | --- | --- |

## 3. Making the components

### 3.1 Component name

Making sketch

**What it is and what it is made from.**

**How to make it.**

1. Mark out ...
2. Cut ...

**How it fits the parts next to it.**

Close-up of the joint

**Check before moving on.**

## 4. Putting it together

### Step 1: ...

Step 1

## 5. First checks

| Check | Requirement | How | Pass when |
| --- | --- | --- | --- |

## 6. Safety stops

## 7. Tools, skills and workspace

## 8. Where the numbers come from

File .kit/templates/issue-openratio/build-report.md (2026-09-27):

---
name: Build report
about: Tell us what happened when you built, printed or tested part of this design
title: "Build report: "
labels: build-report
---

This is a research and educational prototype, not a medical device. It is a TRL 3 concept and is not released for fabrication. If you build any part of it, you do so at your own risk. Reports help everyone.

**What you built** (part, sub-assembly or test)

**Materials, tools and settings**

**What worked**

**What did not work, with photos or measurements if you have them**

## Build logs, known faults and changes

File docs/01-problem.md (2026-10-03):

---
doc_id: WWT-PRB-001
title: WaterWatch problem statement
project: WaterWatch
doc_type: Problem statement
version: "0.4"
status: Draft
date: '2026-10-02'
author: Amish Chadha
license: CERN-OHL-S-2.0
revisions:
- version: "0.1"
  date: '2026-09-24'
  author: Amish Chadha
  change: Initial scaffold
- version: "0.2"
  date: '2026-09-25'
  author: Amish Chadha
  change: Populate to TRL 2 (problem, users, context, constraints, prior work, open questions)
- version: "0.3"
  date: '2026-09-25'
  author: Amish Chadha
  change: For TRL 3, record Amish's decisions from WWT-DDR-001 (tapstands first, default thresholds); partner and region left open
- version: "0.4"
  date: '2026-10-02'
  author: Amish Chadha
  change: Partner, alert and data questions answered by Amish's decisions of 2026-10-02 (WWT-DEC-001)
---

# WaterWatch problem statement

Rural water points go untested between rare lab visits, so a chlorinator that runs dry or a storm that clouds the source can go unnoticed for weeks while people keep drinking the water.

## The problem

In 2024, 2.1 billion people still lacked safely managed drinking water, and about 40 % of rural people had no safely managed service ([WHO and UNICEF JMP, 2025](https://www.who.int/news/item/26-08-2025-1-in-4-people-globally-still-lack-access-to-safe-drinking-water---who--unicef); [JMP report 2025](https://data.unicef.org/resources/jmp-report-2025/)). Many rural schemes now chlorinate at the tank or with an in-line doser, but the check that the chlorine actually reaches the tap is a manual test with a comparator kit, done when a technician visits.

Two quantities tell an operator most of what they need to act on:

- **Free chlorine residual.** WHO guidance, as summarized for field use by Oxfam, is at least 0.5 mg/L after 30 min of contact at pH below 8, and at least 0.2 mg/L at the point of delivery ([Oxfam WASH, chlorination in emergencies](https://www.oxfamwash.org/chlorination-in-emergencies/)). No residual at the tap means the dose is missing or used up, and the water has no protection against recontamination.
- **Turbidity.** Particles shield microbes from chlorine. Chlorination loses effectiveness above about 10 NTU and is not recommended above 100 NTU without pre-treatment (same source); WHO's review of turbidity explains why lower is better ([WHO, Water quality and health: review of turbidity](https://iris.who.int/server/api/core/bitstreams/938bdda2-b77c-480b-806c-1aa06e3126d0/content)).

Remote monitoring has already changed rural water services for **functionality**. Cellular sensors on handpumps in Rwanda shortened repair times when paired with a maintenance service that acted on the data, and similar sensors have tracked functionality and use in Nigeria ([Nagel et al., ES&T 2015](https://pubs.acs.org/doi/10.1021/acs.est.5b04077); [Plateau State sensors, 2022](https://www.sciencedirect.com/science/article/pii/S2352728522000094); [Thomson, WIREs Water 2021](https://wires.onlinelibrary.wiley.com/doi/10.1002/wat2.1502)). The same is not yet true for **water quality**. Reagent-free in-line chlorine analyzers are built for utilities: an amperometric probe alone lists at about $1,900 ([Sensorex FCL](https://sensorex.com/product/fcl-amperometric-free-chlorine-sensor/)) and needs a flow cell, a transmitter and mains power. Low-cost parts exist but are not yet a system: a proven open-source turbidimeter ([Kelley et al., Sensors 2014](https://www.mdpi.com/1424-8220/14/4/7142)), research graphite chlorine sensors ([Pan et al., Anal. Chem. 2015](https://pubs.acs.org/doi/10.1021/acs.analchem.5b03164); [pencil graphite electrodes, PLOS ONE 2021](https://journals.plos.org/plosone/article?id=10.1371%2Fjournal.pone.0248142)) and early long-term trials of low-cost chlorine sensors in on-site water reuse ([Water Science and Technology, 2025](https://iwaponline.com/wst/article/92/2/326/108695/Long-term-performance-of-low-cost-free-chlorine)). There is no open, solar-powered reference design that a small operator can build, install on a tapstand and trust enough to act on.

## Users and context

Table 1. Users and context (proposed; to be confirmed through co-design).

| User | Need | Context |
| --- | --- | --- |
| Tapstand caretaker or water committee member | A plain alert when the water at the tap needs attention, and a simple monthly check routine | Village tapstand, kiosk or school tank; phone with SMS, often not a smartphone |
| Scheme operator or maintenance service provider | Chlorine and turbidity trends from many points, so dosing and repairs can be targeted | Small utility, NGO or private operator serving several villages |
| District water or health officer | Evidence that treated water reaches people, especially during cholera or flood season | Periodic review; outbreak response |
| Researcher or open hardware community | A reproducible, inspectable design to build on | University labs, makerspaces, WASH research groups |

Typical site: a public tapstand or a storage tank outlet on a piped rural scheme with chlorination at the source or tank. No mains power. Ambient temperature from about 0 to 45 °C, direct sun, dust and splashing. Cellular coverage is usually 2G or LTE-M/NB-IoT; some districts have a LoRaWAN gateway.

## Constraints

- Garage-buildable prototype, about $300 USD in parts per unit (`project.yaml`), using off-the-shelf modules and simple fabricated parts.
- Solar powered, with no mains connection and no change to the tapstand beyond one tee on the riser.
- Must not waste much treated water, and must not contaminate the supply (backflow and material safety).
- Must be maintainable by a trained caretaker with a comparator kit, without special tools.
- Must not claim that water is "safe". It reports measurements and alerts; accredited lab testing, including microbiological testing, stays necessary.

## Out of scope

- Microbiological detection (for example *E. coli*); the sensor watches indicators only.
- Chemical contaminants such as arsenic, fluoride or nitrate.
- Controlling the chlorine dose; WaterWatch observes and alerts, it does not dose.
- Household point-of-use treatment.

## Co-design checklist

- [ ] Identify a partner scheme operator or maintenance service and two or three pilot sites.
- [ ] Interview caretakers, operators and district officers on alert content, language, thresholds and who acts.
- [ ] Confirm local cellular coverage and SMS costs, or LoRaWAN availability.
- [ ] Agree where flushed sample water goes at each site.
- [ ] Agree who owns the data and who may see it.

## Open questions

- Which partner and region first? Decided by Amish, 2026-10-02 (WWT-DEC-001): a scheme operator that runs chlorinated, solar-powered piped schemes with public tapstands; the first candidate to approach is Water Mission, which runs such schemes in East Africa, with the first region taken from its country programs; not yet approached.
- Tapstand only, or also storage tank outlets and kiosks? Decided by Amish, 2026-09-25: tapstands first, tank outlets and kiosks later (WWT-DDR-001, D8).
- Which alert thresholds should be defaults? Decided by Amish, 2026-09-25: free chlorine below 0.2 mg/L and turbidity above 5 NTU, confirmed by two consecutive readings and adjustable per site (WWT-DDR-001, D6). Partners may still ask for other site values.
- Alert language, recipients and data ownership: decided by Amish, 2026-10-02 (WWT-DEC-001) as defaults to confirm in co-design: alerts go by SMS in the site's main local language, with an English copy to the operator, stating only what was measured, when and the threshold crossed; they go to the caretaker and the operator's maintenance contact, with a weekly summary to the district water officer; the scheme operator owns the data; the water committee and the district water and health offices can see it; anonymized site data are published only with the operator's written agreement.

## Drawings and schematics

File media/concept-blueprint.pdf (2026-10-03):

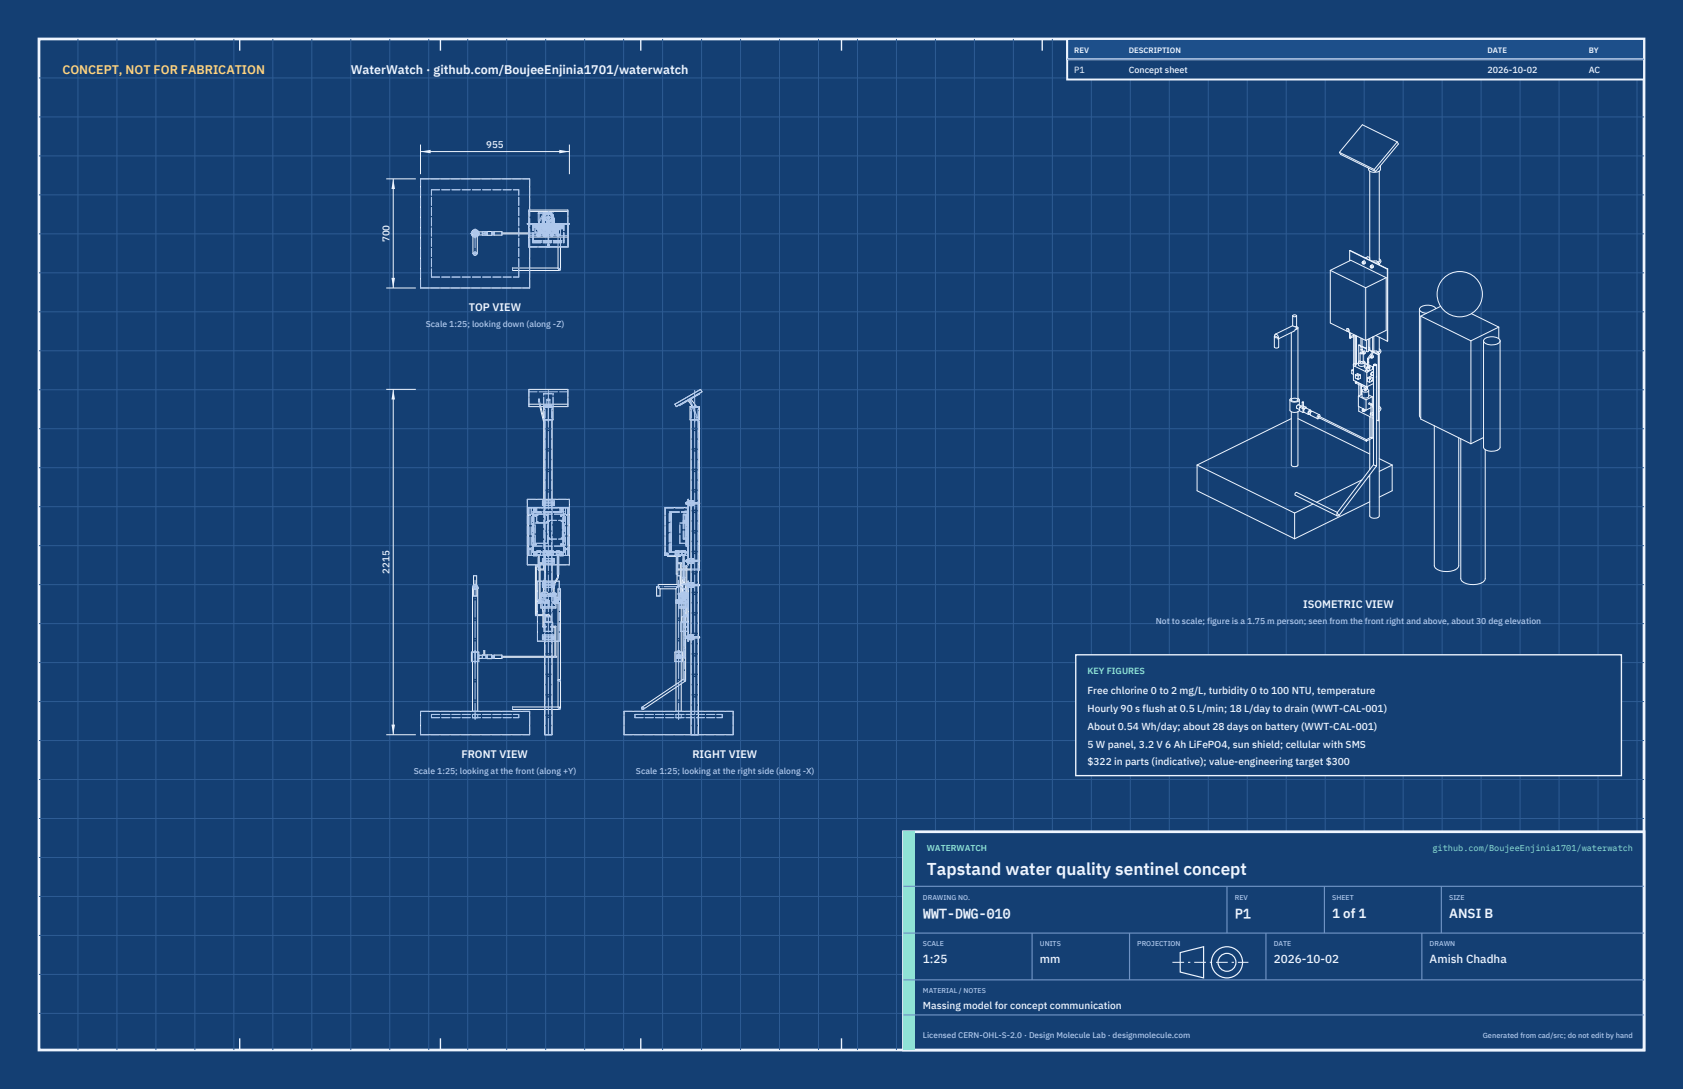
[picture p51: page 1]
CONCEPT, NOT FOR FABRICATION; WaterWatch · github.com/BoujeeEnjinia1701/waterwatch; FRONT VIEW; TOP VIEW; RIGHT VIEW; ISOMETRIC VIEW; REV; DESCRIPTION; DATE; Concept sheet; WATERWATCH; github.com/BoujeeEnjinia1701/waterwatch; DRAWING NO. WWT-DWG-010; REV P1; SHEET 1 of 1; SIZE ANSI B; SCALE 1:25; UNITS mm; PROJECTION; DRAWN Amish Chadha; Licensed CERN-OHL-S-2.0 · Design Molecule Lab · designmolecule.com; Generated from cad/src; do not edit by hand

Scale 1:25; looking down (along -Z)

Not to scale; figure is a 1.75 m person; seen from the front right and above, about 30 deg elevation

KEY FIGURES
Free chlorine 0 to 2 mg/L, turbidity 0 to 100 NTU, temperature
Hourly 90 s flush at 0.5 L/min; 18 L/day to drain (WWT-CAL-001)
About 0.54 Wh/day; about 28 days on battery (WWT-CAL-001)
5 W panel, 3.2 V 6 Ah LiFePO4, sun shield; cellular with SMS
$322 in parts (indicative); value-engineering target $300

Scale 1:25; looking at the front (along +Y)

Scale 1:25; looking at the right side (along -X)

Tapstand water quality sentinel concept

MATERIAL / NOTES
Massing model for concept communication

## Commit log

2026-09-24 Initial scaffold: standard open hardware layout, CERN-OHL-S v2 + MIT licenses
    Claude-Session: https://claude.ai/code/session_01XuhhSU4W6fYhgCfURbrkut
    [bom.csv]
2026-09-25 Adopt portfolio kit v1.3.0: session commands, scale figure, 3D viewer, flow diagrams
    Adds .claude/commands (/populate, /advance-trl3, /rein-in, /refresh-media)
    so every Claude Code session starts from the standard prompts, and extends
    concept media with a 1.75 m scale figure, an interactive glTF viewer and
    system or energy flow diagrams. TRL cap 3 unchanged.
    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
2026-09-25 Kit v1.3.1: renderer fixes from the TremorTrace pilot
    Context scale parts for small objects, cutaway exclusions, and text
    labels in flow diagrams.
    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
2026-09-25 Populate waterwatch to a strong TRL 2 with concept media (batch 6)
    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
    [bom.csv]
2026-09-25 Advance waterwatch to TRL 3 (batches 5 and 6)
    Decisions approved by Amish 2026-09-25 recorded in DDR-001. TRL 4 is on hold.
    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
    [bom.csv, enclosure.step, enclosure.stl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]
2026-09-26 Accept all recommendations (DDR-002), switch footer to designmolecule.com, add README write-up with new inspiration point
    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
    [bom.csv, enclosure.step, flow-cell.step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]
2026-09-27 Product appearance model and photoreal renders
    Adds cad/src/product_model.py (appearance model for renders only, all main
    dimensions from model.py) and Blender renders in media/render-*.png,
    captioned with the project, repository and viewing direction. README leads
    with the product render; trl stays 3.
    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
2026-10-01 Image quality pass: legible exploded views, flow diagrams and drawing sheets
    Kit 1.6.1 image layout: the parts list sits in its own column, number bubbles sit on visible parts and never overlap, small parts get a leader, pictures are cropped to the subject, flow labels keep numbers with their units, and sheet captions and the revision table no longer overprint. Concept images, blueprint and general arrangement sheet regenerated; repo-specific labels moved clear of other text and lines.
2026-10-02 Kit 1.7.0: constructable design, illustrated build plan and design decisions register
    The design is now constructable: every part can be made and fits its neighbours, with each change recorded in a Design for construction decision record (made under Amish's 2026-09-30 instruction; ope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
    FlexHand also credits Dr. Geeti Chadha as a contribut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
    [bom.csv, enclosure.step, enclosure.stl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]
2026-10-03 Carry approved follow-ups into the design and redo photoreal renders
    Amish approved the follow-up actions from the open-decision sign-off ("APPROVED CHANGES, COMPLETE THESE", 2026-10-02), the design-for-construction change tables in ten repos, the last wave's open dec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
    [bom.csv, enclosure.step, enclosure.stl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]
2026-10-28 Kit 1.9.1 upgrade: pipeline documents and detailed CAD for every option
    Kit 1.9.1 installed (.kit, CLAUDE.md, .claude/commands). Kit 1.8 pipeline: STEM check with fixes under the 2026-10-23 standing instruction, concept options with the current design as option A, URS, PRS, generated RTM, REG, FEA, RSK with design FMEA, MKT, PLN and DDR; kit 1.9 D3 model of every option passing cad/fidelity.json; independent review recorded in the STEM check. Amish's 2026-10-25 decisions recorded where he approved a recommendation; all others proposed, awaiting Amish. Product renders and the options picture follow in a later commit where not yet included.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
2026-10-29 Add Cycles product renders and the concept options picture
    Blender Cycles renders of the kit 1.9.1 model, rendered on Amish's Mac and captioned; media/options.png from the D3 option models (this also clears the failing docs check, which needs the picture); cards and PDFs rebuilt. The options picture labels option A as the current design unless project.yaml records Amish's choice.
2026-10-29 Add the concept options picture rendered from the D3 option models
    media/options.png from Blender Cycles panels of every option, rendered on Amish's Mac; the label reads CURRENT DESIGN unless project.yaml records Amish's choice. Clears the docs check, which needs th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

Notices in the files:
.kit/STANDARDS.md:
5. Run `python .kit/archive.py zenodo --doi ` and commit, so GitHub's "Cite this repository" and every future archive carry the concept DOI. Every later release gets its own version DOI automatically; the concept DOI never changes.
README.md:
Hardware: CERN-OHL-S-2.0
